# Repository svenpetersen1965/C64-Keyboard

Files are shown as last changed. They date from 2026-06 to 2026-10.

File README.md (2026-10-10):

# Status
* Hardware tested: done
* Software tested: done
* Upload all design files: done
* Documentaion: completed, except "Howto: Keycaps"
  
# C64-Keyboard
A mechanical keyboard for the C64.
*	<b>Reset</b>: The keyboard can generate RESET and EXROM RESET signals.
*	<b>Kernal switching</b>: The keyboard can switch between multiple Kernals on an EPROM Kernal adapter.
*	<b>OLED display</b>: An I²C OLED display can be connected to the keyboard.
*	<b>Piezo buzzer</b>: The keyboard includes a piezo buzzer for signaling.
*	<b>USB keyboard</b>: The keyboard can be operated as a USB keyboard for VICE and BMC64.
*	<b>RGB lighting</b>: The keyboard can produce a light show using a WS2812B RGB LED strip.
*	<b>Power LED</b>: The C64's power LED can be connected to the keyboard on either the left or right side and can be made to blink.
*	<b>Additional buttons</b>: Two additional buttons beside the shorter space bar provide additional control functions.

This is a work in progress. I am sharing some files in advance. A full release will happen soon. 

After about 21 months of work, the day has finally come: I’m releasing my Commodore C64 keyboard project on GitHub!

I haven’t been working on it full-time, of course, but I’ve still put several person-months of work into it (most of it for documentation). And I’ve certainly spent a few thousand euros along the way (so you don't have to).

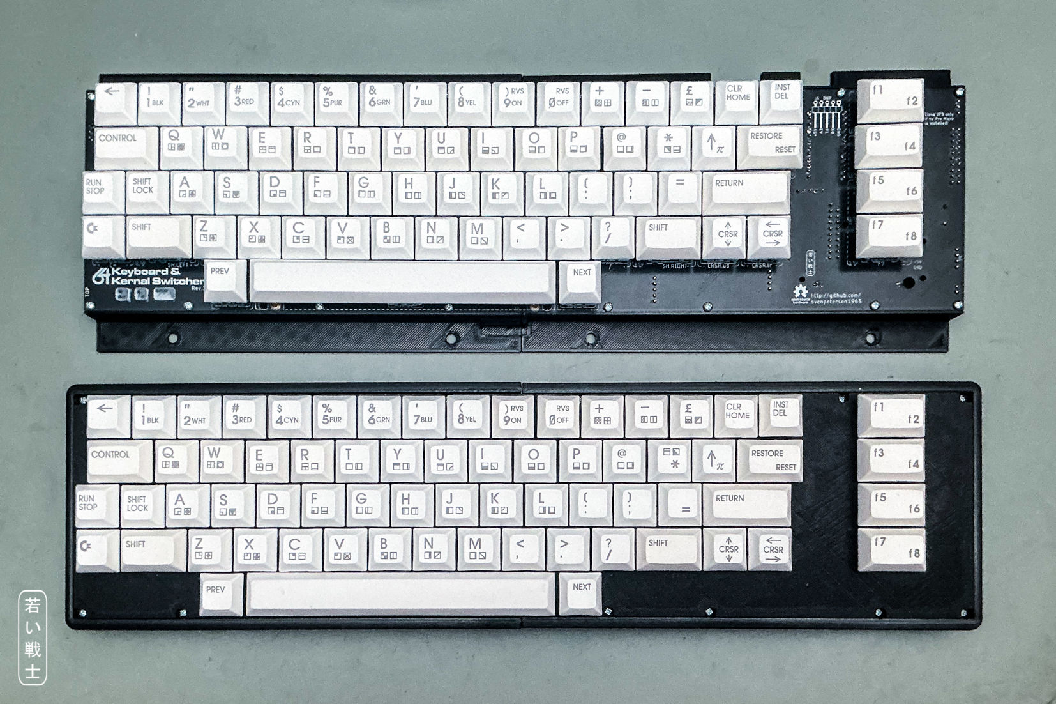
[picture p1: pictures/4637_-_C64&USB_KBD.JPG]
C64-Keyboard and the USB-Keyboard version

<p align="center">The C64 mechanic Keyboard and the USB-Keyboard version for VICE and BMC64</p>

My goal was to build a complete keyboard, including the keycaps, and figure out a way for others with some DIY skills to build one, too, without having to spend anywhere near as much money.

Let me be clear, though: this isn’t meant to be a cheap replacement for an original C64 keyboard. It’s for people who use a C64, an Ultimate 64, or another C64-compatible system and enjoy mechanical keyboards. If you’d like to build your own keyboard and add some extra functionality to your setup, this project might be just what you’re looking for.

The documentation is around 80 pages long, but most of it consists of pictures, and you don't need to read every single page. I'd really appreciate it, though, if you took the time to understand the important parts. Otherwise, I might end up providing support for years to come, and I'd rather spend that time working on new projects!

The bill of materials (BOM) is quite flexible. You don't need all the components; you can populate only the parts required for your intended setup. I've designed the BOM to make this as straightforward as possible.

However, you should decide which features you need before ordering the components. Even if you fully populate the board, none of the unused circuits will interfere with the keyboard's normal operation.

I'd like to draw your attention to the following important sections of the documentation:
*	Hardware module description: Versions with and without hot-swap sockets for the keyboard switches.
*	C64 Keyboard Connector PCB: Module description.
*	Which Cables Do I Need?
*	How To: Keycaps: A short guide to making your own keycaps.
*	Software documentation: How to use and configure the firmware.

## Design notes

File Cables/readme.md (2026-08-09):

There are three cables in this subdirectory:
1. The keyboard cable to the C64 Keyboard Connector PCB (plugged into the mainboard): KB_Cab
2. The Kernal Switcher Cable (between the keyboard and the EPROM Kernal adapter): KSw_Cab
3. The Ultimate 64 cable between the keyboard and the button pin header: Ulti_Cab

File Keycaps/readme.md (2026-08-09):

The key caps were scanned off a C64C keyboard. Then redrawn in Inksacpe and finally exported as PNG file for further processing/printing.

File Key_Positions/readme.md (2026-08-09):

The position information was obtained by measuring an original C64 keyboard plastic shield with calipers (a normal and an extral long one).

The data was further processed to even out failure and to finally calculate the switch positions on the PCB.

The "gap" left of the function keys occures on classic C64. Moving the function keys 0.7mm to the left would center them. 

I decided against doing so, because the original position would fit all cases, while I don't know, if a corrected position will do. 

Note: moving the function keys will require modifying the 3D ptintable plates, as well.

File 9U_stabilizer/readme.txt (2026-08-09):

The 9U stabilizer wire is bent from 1.5mm spring steel. It is only required, if classic keycaps are used, since 9U screw-in stabilizers are not sold anywhere.

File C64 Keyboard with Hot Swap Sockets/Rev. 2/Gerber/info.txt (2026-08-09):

      
       Board: Keyboard C64 (Hot Swap)
       Rev.:  2
  
       Files:
       ======
  
       All Gerber files are generated in extended gerber format (RS274X)
       *.TOP        : Film top copper
       *.BOT        :  -"- bottom copper
       *.STC        :  -"- top soldermask 
       *.STS        :  -"- bottom soldermask
       *.PLC        :  -"- silk screen top
       *.PLS        :  -"- silk screen bottom
       *.CRS        :  -"- cream bottom
       *.DK         : Drills plated Through (Excellon)
       *.NDK        : Drills not plated Through (Excellon)
       *.OUT        : Board outline

       Board Size:
       ===========
       Length     :   385.6 mm
       Width      :   96.4 mm
       Thickness  :   1.6 mm
       Material   :   FR 4
       Copper     :   35 um
       Surface    :   HASL
       
       Remarks:
       ========
       width > 6mil
       distane >= 6 mil
       drill >= 6mil

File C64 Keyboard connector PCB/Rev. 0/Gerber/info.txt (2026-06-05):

      
       Board: Keyboard C64 connector PCB
       Rev.:  0
  
       Files:
       ======
  
       All Gerber files are generated in extended gerber format (RS274X)
       *.TOP        : Film top copper
       *.BOT        :  -"- bottom copper
       *.STC        :  -"- top soldermask 
       *.STS        :  -"- bottom soldermask
       *.PLC        :  -"- silk screen top
       *.PLS        :  -"- silk screen bottom
       *.DK         : Drills plated Through (Excellon)
       *.NDK        : Drills not plated Through (Excellon)
       *.OUT        : Board outline

       Board Size:
       ===========
       Length     :   53.0 mm
       Width      :   15.0 mm
       Thickness  :   1.6 mm
       Material   :   FR 4
       Copper     :   35 um
       Surface    :   HASL
       
       Remarks:
       ========
       width > 6mil
       distane >= 6 mil
       drill >= 6mil

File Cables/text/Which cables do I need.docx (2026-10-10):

C64 Keyboard: Which Cables Do I Need?

You can find three cable drawings in the /Cables/pdf subfolder:

- KB_Cab.pdf: The 20-way ribbon cable connecting the keyboard to the keyboard connector PCB.
- KSw_Cab.pdf: The cable connecting the Kernal EPROM adapter PCB to /RESET and /EXROM.
- Ulti_Cab.pdf: The cable connecting the keyboard to the “Buttons” pin header on the Ultimate 64 Elite II or C64 Ultimate mainboard.

Which cables you need depends on how you intend to use the keyboard.

- USB keyboard for VICE: No cables required.
- C64 keyboard without Kernal switching or reset functionality: KB_Cab.
- C64 keyboard with Kernal switching and reset functionality: KB_Cab + KSw_Cab.
- Keyboard connected to an Ultimate 64 Elite II or C64 Ultimate: KB_Cab + Ulti_Cab.

So, you never need more than two cables.

# Making the ribbon cable

Making a ribbon cable requires no soldering and should only take a few minutes. All you need is a vise to press the connector onto the cable and a pair of scissors to cut the ribbon cable to length.

# Making the Dupont cables

For the Dupont cables, you can either use a ready-made 40 cm Dupont ribbon cable with individual female connectors, which can be used as is, or additionally use a Dupont connector assortment with crimp housings in the required sizes (3-way, 4-way and 5-way). The latter option is a bit better, as the housings keep the wires in the correct order and prevent mix-ups. To do this, you can remove the crimp terminals from the individual 1-way housings (pointy tweezers) and insert them into the appropriate multi-way housings from the assortment.

f you want to crimp the connectors yourself, I recommend the IWISS SN-025 crimping tool. It's the only tool I've personally found that can properly crimp Dupont terminals. Other tools, such as the SN-28B or SN-48B, are sometimes advertised as Dupont crimping tools, but they aren't suitable for this purpose. They're good tools, just not for Dupont terminals.

Which cables do I need.docx 10.10.2026 17:31 Drafted by Sven Petersen Page 2 of 2 Doc.-No.: 000-6-00-00

Which cables do I need.docx 10.10.2026 17:31 Drafted by Sven Petersen Page 1 of 1

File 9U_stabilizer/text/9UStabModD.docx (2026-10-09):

How To: 9U stabilizer (v.0)

Like 9U space bars, a 9U stabilizer cannot be purchased off the shelf. The only situation in which you need a 9U stabilizer is when using the original 9U space bar from a classic C64. A Blingboard64 or C64 Ultimate space bar is also 9U long, but uses a 7U stabilizer.

A 9U stabilizer can be made from a stabilizer of any length by replacing its stabilizer wire with a homemade wire of the appropriate length.

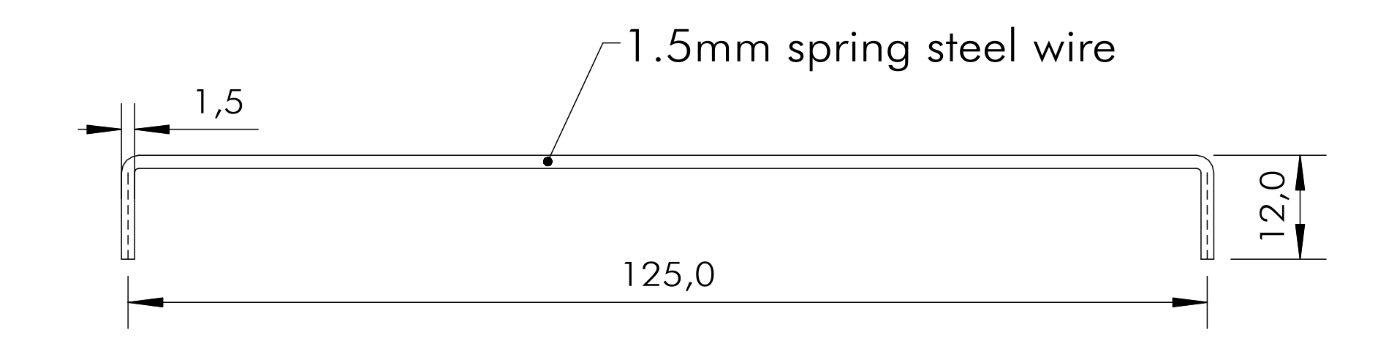
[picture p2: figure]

Figure 1: Dimensions of the 9U stabilizer wire

The material is 1.5 mm spring steel wire. This is often sold as a 5-meter spool, but a shorter, straight piece is easier to handle, as it does not need to be straightened first.

The required wire length is 147.5 mm. However, it is recommended to cut a slightly longer piece and trim and file the ends to the correct length after bending.

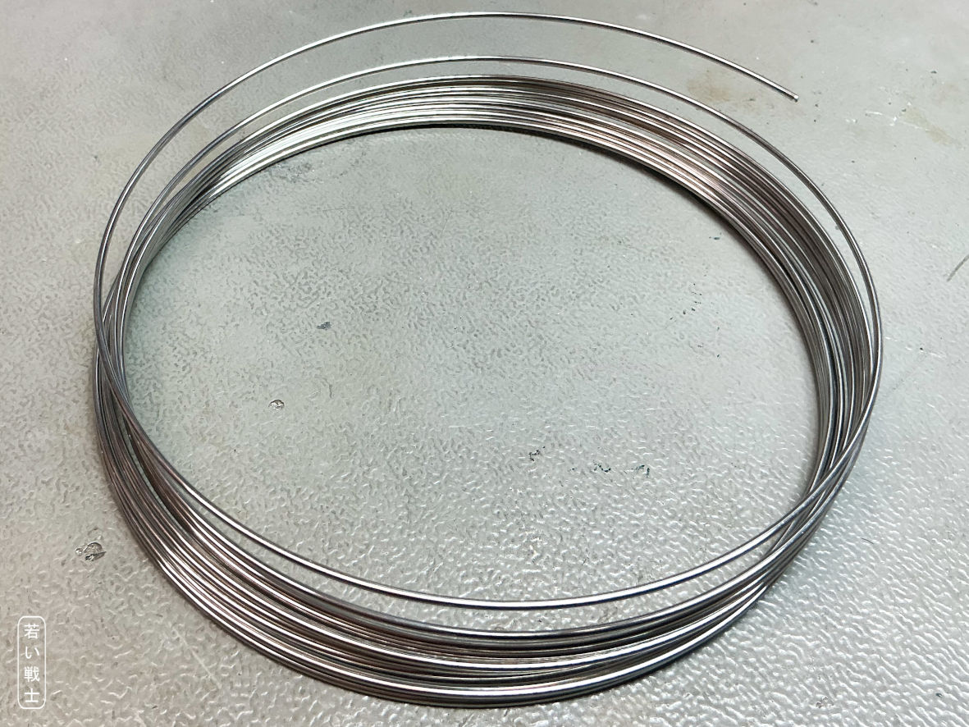
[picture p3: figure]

Figure 2: 1.5mm spring steel spool

The wire can be straightened using a wire straightener, which is an investment of €40 or more.

I was advised to unwind wire from the spool, then hold one end in a vise and pull the wire with combination pliers until it is straight. This, of course, requires a longer piece of wire, as the end will be worn out during this process.

The wire straightener I bought (Figure 3) gets the wire reasonably straight, but not perfectly straight. To achieve a perfectly straight wire, it can be rolled between two flat, hard surfaces as a final step. I tried it without this last step, and it worked fine.

The wire straightener consists of four steel rollers on one side and three on the other, all mounted on ball bearings. The distance between the rollers can be adjusted with a screw.

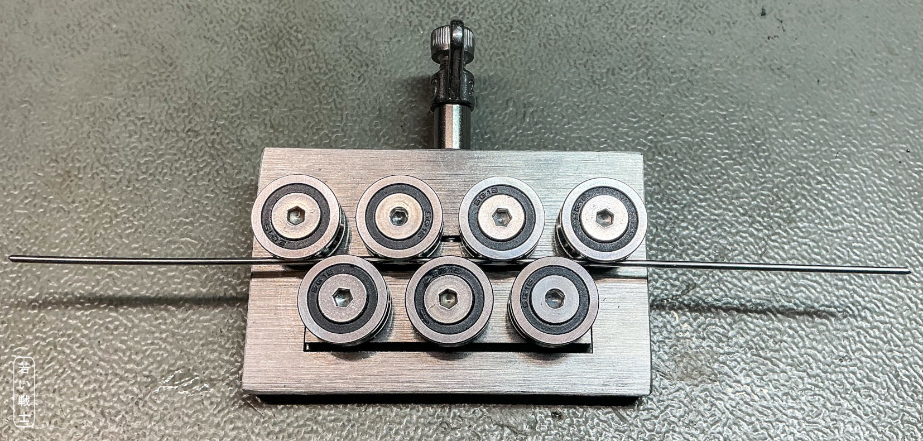
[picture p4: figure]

Figure 3: Wire straightener

The basic strategy for producing a straight wire is to cut a piece about 40–50 cm long from the spool.

Start with a relatively large distance between the rollers, which will leave the wire slightly curved. Push and pull the wire through the straightener several times. Then reduce the distance between the rollers and repeat the process. Reduce the distance again and continue in this way, gradually straightening the wire more and more.

If the wire becomes slightly overbent in the opposite direction, turn it 180°, increase the roller distance very slightly, and see what happens. “Pretty straight” is good enough.

The length of the stabilizer wire does not need to be highly accurate, neither does the angle. I estimate the tolerance to be ±0.7mm, that the stabilizers can accept, which I have used. The first 90° bend is not problematic at all. Just get the 12mm end a bit longer than that, it will later be trimmed and filed. For bending the wire, combination pliers and a hard surface are ok, a wire bender might be slightly better.

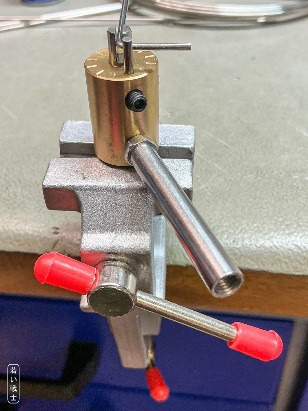
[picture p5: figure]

Figure 4: Not the greatest wire bender

I have bought a pretty crappy wire bender (Figure 4). The vise is actually the bad part of it. In case you always wanted to have a wire bender, make sure that a 1.5mm wire will fit in its slot.

Keep in mind, that the inner radius of the bend is not zero. I have managed about 1mm bending radius.

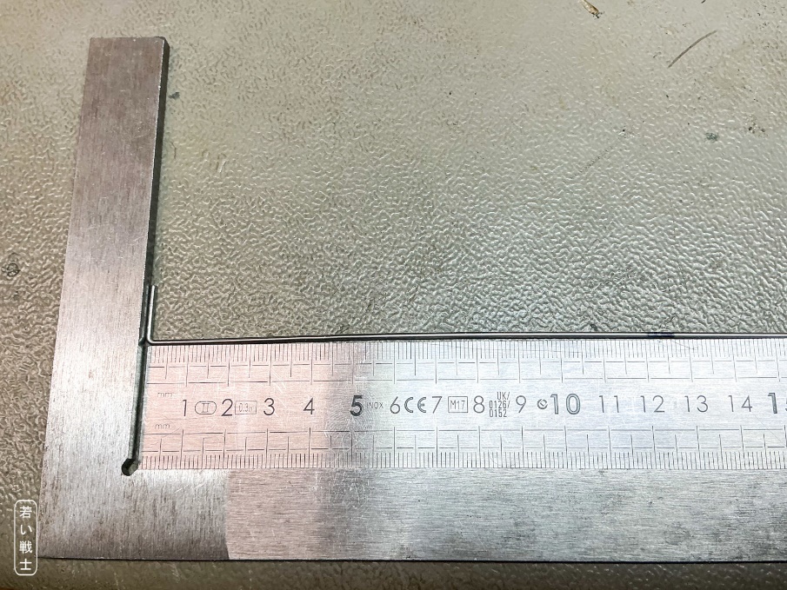
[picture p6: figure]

Figure 5: Marking the desired length after the first bend

For simplicity, I have measured the distance of the 2nd bend. It was a rough estimation, that marking 125mm from the outer surface of the first bend would be a good position. I first painted the wire a bit with a sharpie and marked the position with the scriber (Figure 5).

When bending the wire, it was important to have the first and the 2nd bend aligned (estimated), so the stabilizer wire is not twisted.

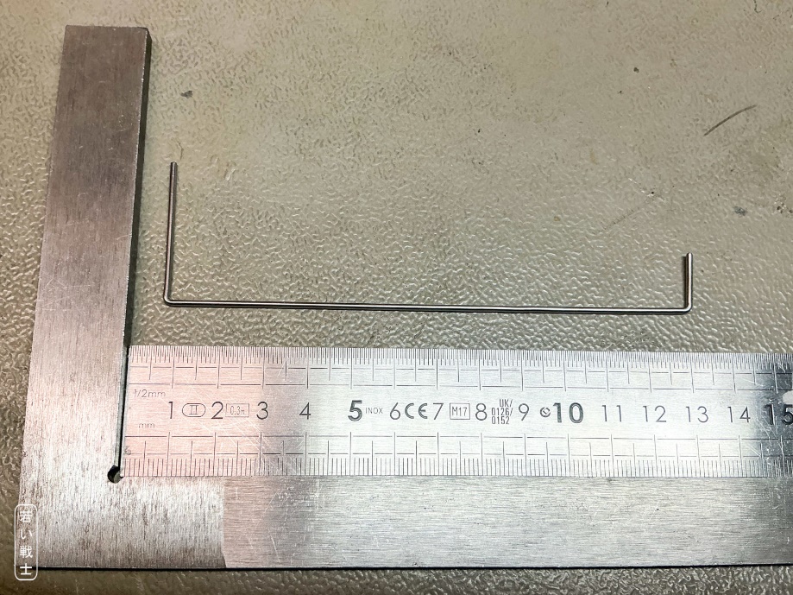
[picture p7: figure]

Figure 6: 2nd bend

The bent wire should lay flat on the work bench, the angle should be about 90°. To make it fit, you can manually twist and bend the wire a bit.

The bent parts of the wire should then be trimmed and filed to length. It should be 12mm or a bit less (Figure 1). If that it too long, the wire will not move freely, which is required.

Keep in mind, that testing the stabilizer wire before the switches are soldered in makes things a lot easier.

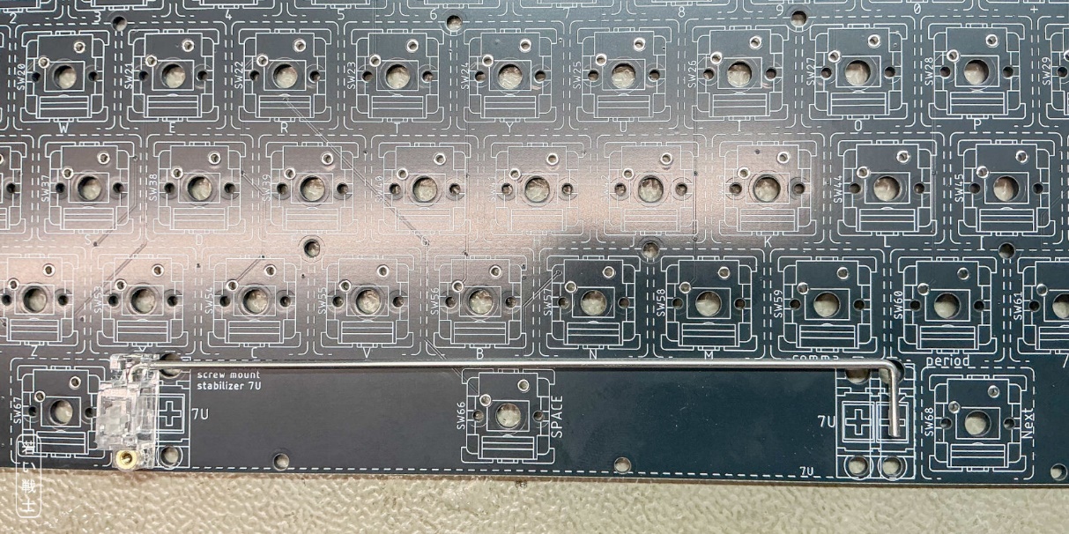
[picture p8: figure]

Figure 7: Checking the length of the stabilizer wire

Insert the wire into one of the stabilizers (the body with the little moving plastic part) and mount it on the PCB. The 2nd bend should be positioned on the center line of the 2nd stabilizer (Figure 7). If that is the case, the 2nd stabilizer can be mounted.

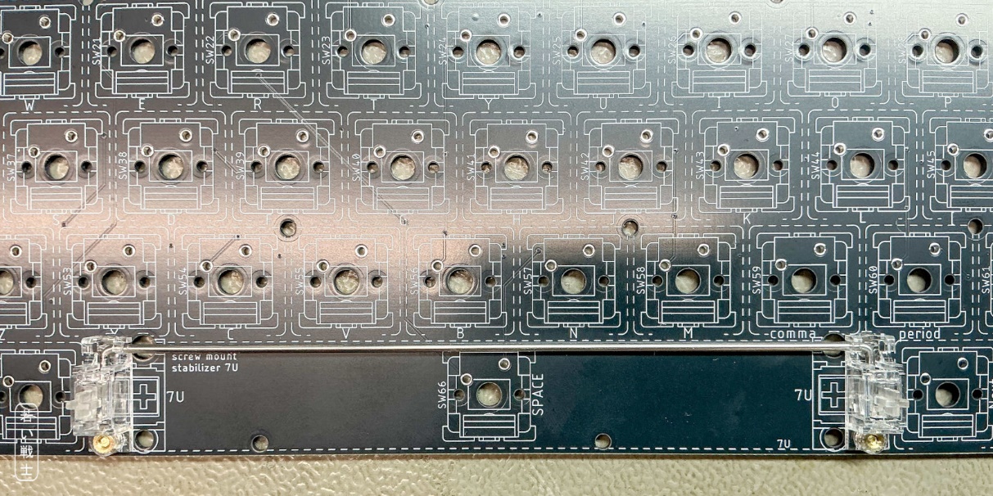
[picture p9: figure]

Figure 8: Space bar stabilizer completely mounted

The moving parts should move freely up and down. If you lift one side, the other should also lift in the same manner. When dropping it, the other side should drop, too. It should not get caught. The spring of the space bar switch needs to be able to fully push the space bar up.

I have made three stabilizer wires yet and screwed up one. So, it is a good thing to have enough wire for two or three attempts.

The perfect wire would have the outer dimension of 0.75mm + 125mm +0.75mm = 126.5mm. The screwed-up wire was only 125mm in total – 1.5mm too short. It could still be installed, but the stabilizer didn’t move freely anymore.

9UStabModD.docx 09.10.2026 18:35 Drafted by Sven Petersen Page 2 of 2 Doc.-No.: 232-6-00-00

9UStabModD.docx 09.10.2026 18:35 Drafted by Sven Petersen Page 1 of 1 Doc.-No.: 232-6-01-00

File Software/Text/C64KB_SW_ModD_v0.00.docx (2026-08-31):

C64 Keyboard Software

Module Description v0.00

# 1. Introduction

The C64 Keyboard functions as a normal/standard matrix keyboard if no micro controller (Pro Micro) is installed. However, if you want to use “smart” functions, like

- RESET/EXROM RESET
- Kernal Switching
- RGB LED illumination (WS2812B strip)
- USB Keyboard (for VICE or BMC64)

some software needs to be installed on the Pro Micro. This can be done using the free Arduino IDE, a suitable USB-C or micro-USB cable, and a PC.

The software can be configured to suit your particular use case simply by uncommenting the appropriate preprocessor macros. This does not require a PhD in computer science and will be described later in this document.

# 2. Functions

## 2.1. C64 (Matrix) keyboard

This requires the Kernal switcher cable to be connected to a Kernal EPROM adapter (long board or short board), plus /RESET and /EXROM.

Key | Duration | Function
| < 0.3 secs | Normal RESTORE
| ≥ 0.3 secs | “RESTORE Fix”: 5 pulses (of 30 msecs each) are issued on the RESTORE signal of the keyboard.
| ≥ 3 secs | A “normal” RESET is issued. SHIFT LOCK is turned off.
| ≥ 5 secs | An EXROM RESET is issued. This bypasses some CBM80 copy protections. SHIFT LOCK is turned off.
| | Cycle through RGB LED modes (downwards)
| | Cycle through RGB LED modes (upwards)
+ | | Cycle through Kernals (downwards), RESET the C64
+ | | Cycle through Kernals (upwards), RESET the C64

The requirement to press PREV/NEXT and RESTORE simultaneously prevents accidentally switching Kernals, since doing so resets the C64 and causes any running program to be lost.

## 2.2. Ultimate (Matrix) keyboard

This requires the Ultimate Buttons cable to be connected to the Buttons pin header on the Ultimate Elite II board. On earlier models, the button pin header is not implemented.

Key | Duration | Function
| < 0.3 secs | RESTORE key
| ≥ 0.3 secs | RESTORE key
| ≥ 3 secs | The RESET button on the buttons pin header is simulated. SHIFT LOCK is turned off.
| ≥ 5 secs | SHIFT LOCK is turned off.
| | Cycle through RGB LED modes (downwards)
| | Cycle through RGB LED modes (upwards)
+ | | The FREEZE button on the buttons pin header is simulated.*
+ | | The MENU button on the buttons pin header is simulated.

* The FREEZE button only has an effect when a freeze cartridge is present.

## 2.3. VICE USB Keyboard

The USB keyboard in VICE mode uses a positional keyboard layout in either English, German, or Swedish. The keyboard is scanned 125 times per second (every 8 ms).

Key | Duration | Function
| < 0.3 secs | RESTORE key sent.
| ≥ 0.3 secs | RESTORE key sent twice.
| ≥ 3 secs | A soft RESET (ALT+F9) is sent. SHIFT LOCK is turned off.
| ≥ 5 secs | A hard RESET (ALT+F12) is sent. SHIFT LOCK is turned off.
| | Cycle through RGB LED modes (downwards)
| | Cycle through RGB LED modes (upwards)
+ | | <ALT>+<8> is sent (attach disk image)
+ | | <ALT>+<C> is sent (attach cartridge image)

## 2.4. BMC64 USB Keyboard

The USB keyboard in VICE mode is a positional English keyboard. The keyboard is scanned 125 times per second (every 8 ms).

Key | Duration | Function
| < 3 secs | RESTORE key sent
| ≥ 3 secs | + f1 is sent. SHIFT LOCK is turned off. *
| ≥ 5 secs | + f3 is sent. SHIFT LOCK is turned off. *
| | Cycle through RGB LED modes (downwards)
| | Cycle through RGB LED modes (upwards)
+ | | + f5 is sent.*
+ | | + f7 is sent.*

* These functions require configuration in the BMC64 menu, which can be accessed by pressing RESTORE. The relevant submenu is:

Keyboard → Mapping → Positional

My Configuration:

Key | Configured Actions
+ f1 | Soft reset
+ f3 | Hard reset
+ f5 | Tape OSD
+ f7 | Menu

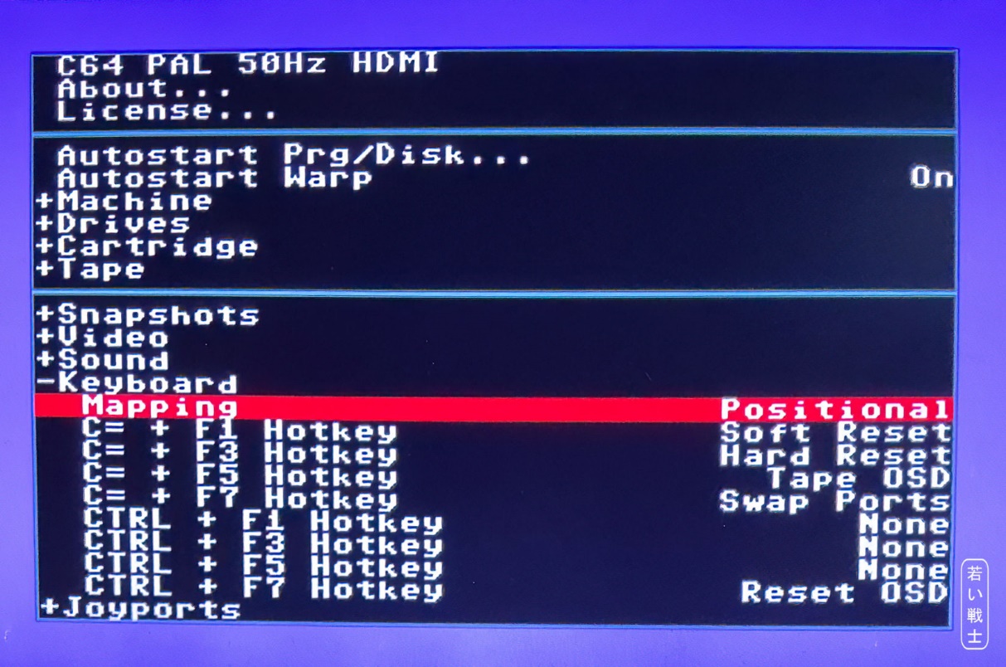
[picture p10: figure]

Figure 1: Configuration of BMC64 in the menu

# 3. Installing and preparing the Arduino IDE

## 3.1. Download and Installation

The Arduino IDE is required for programming the Pro Micro module. In addition, several libraries need to be installed using the IDE's Library Manager.

The Arduino IDE can be downloaded from arduino.cc (https://www.arduino.cc/en/software/). Select the version for your computer's operating system (Windows, Linux, or macOS) and follow the installation instructions.

## 3.2. Library Manager

Next, open the Library Manager in the Arduino IDE.

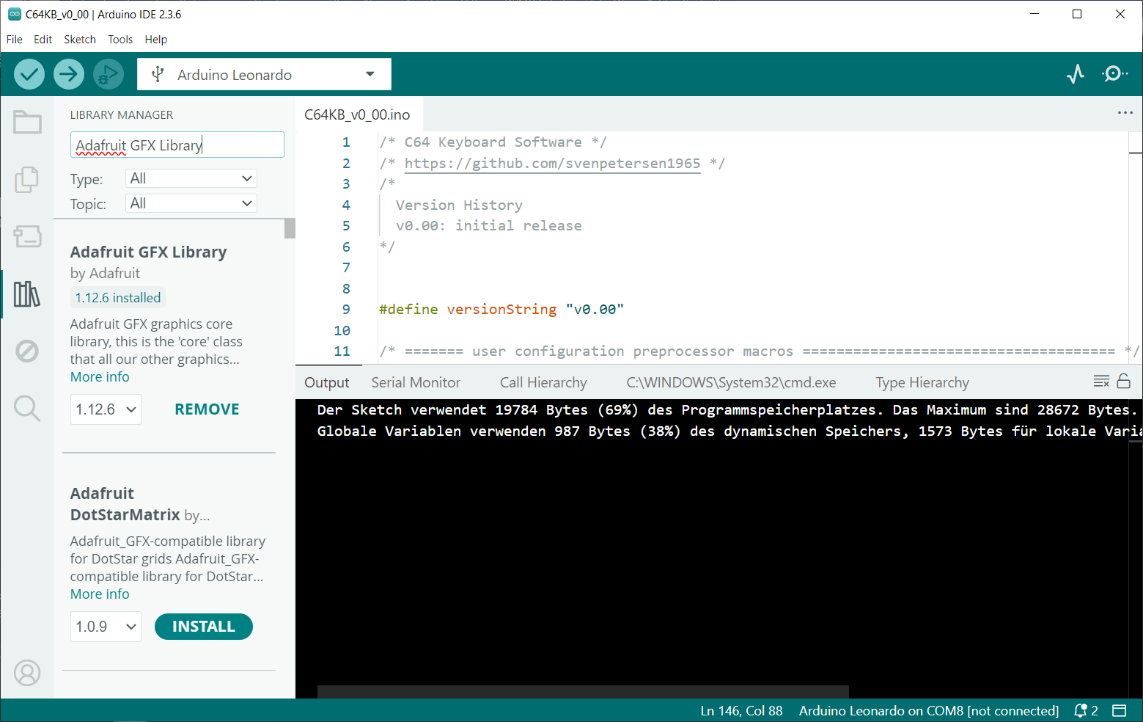
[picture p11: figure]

Figure 2: Library Manager (Arduino IDE 2.3.6)

The Library Manager can be found in the left-hand sidebar. It is represented by the “books” icon, as shown in Figure 2.

You need to install the following libraries:

Library | Source | Version used
Adafruit GFX Library | https://github.com/adafruit/Adafruit-GFX-Library | 1.12.6
Adafruit SSD1306 | https://github.com/adafruit/Adafruit_SSD1306 | 2.5.17
Adafruit SH110X | https://github.com/adafruit/Adafruit_SH110X | 2.1.15
PCF8575 | https://github.com/RobTillaart/PCF8575 | 0.3.0
HID-Project | https://github.com/NicoHood/HID | 2.8.4
Adafruit_NeoPixel | https://github.com/adafruit/Adafruit_NeoPixel | 1.15.5

The table above lists the required libraries, their Internet sources (which you probably will not need), and the library versions used for this project.

In most cases, using a newer version should not cause any problems. However, there may be cases where a newer version is incompatible with the project. If this happens, please install the specific library version used for this project.

# 4. Configuring the Software

## 4.1. Preprocessor macros

The C64 keyboard “C64KB_v?_??.ino” source code can be configured to suit your needs using preprocessor macros. These macros are evaluated during compilation and determine how the software is compiled.

Most of these macros are either defined or undefined. This allows options to be switched on or off simply by uncommenting or commenting out the corresponding line.

Comments are text annotations that are not compiled. A single-line comment starts with //. Preprocessor macros themselves are defined using a #define statement.

Note: Comments can also be enclosed between /* and */. However, this is less convenient when working with preprocessor macros.

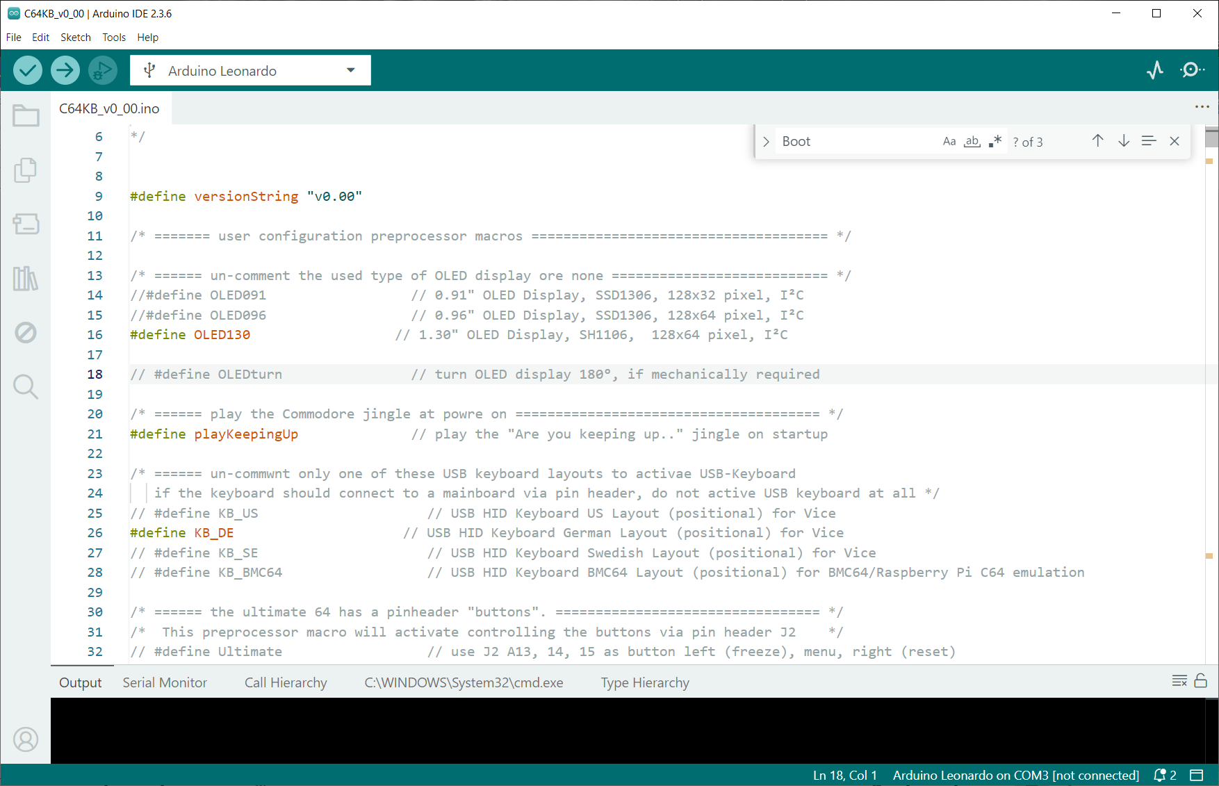
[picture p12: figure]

Figure 3: Some preprocessor macros (Arduino IDE)

In Figure 3 the preprocessor macros OLED130, playKeepingUp and KB_DE are enabled, while all other macros are disabled (i.e., commented out).

In the Arduino IDE editor, comments are displayed in grey, while active preprocessor macros are shown in color. The meaning of these macros is explained later in this document.

## 4.2. OLED display

The software supports three types of OLED displays.:

Preprocessor Macro | OLED Type
OLED091 | 0.91" OLED Display, SSD1306 controller, 128x32 pixel, I²C
OLED096 | 0.96" OLED Display, SSD1306 controller, 128x64 pixel, I²C
OLED130 | 1.30" OLED Display, SH1106 controller, 128x64 pixel, I²C

These OLED displays are widely available on eBay, Amazon, AliExpress, and other online retailers.

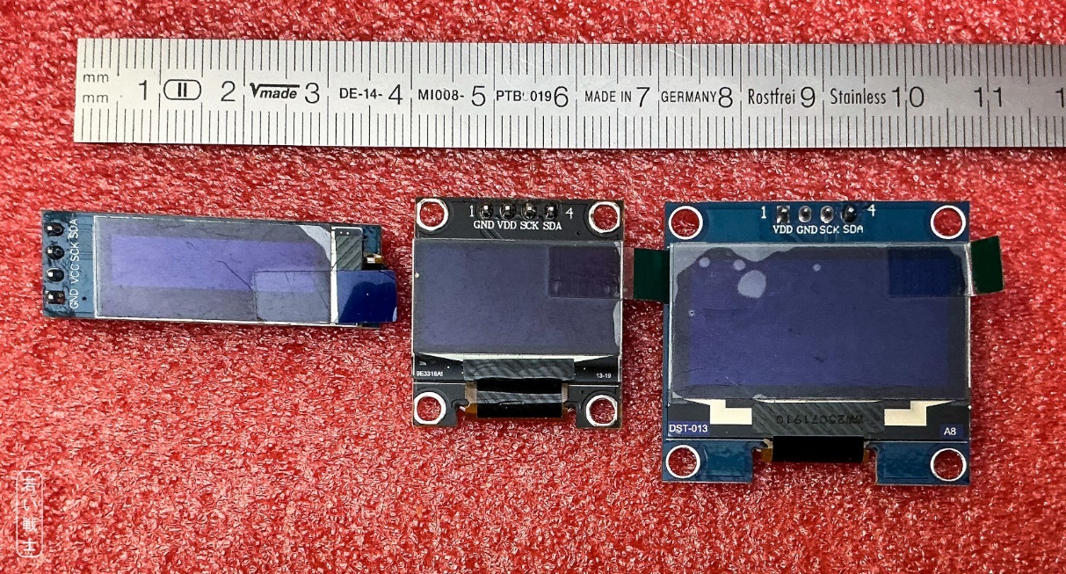
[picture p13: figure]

Figure 4: 0.91", 0.96" and 1.3" OLED Displays (l.t.r.)

If the display needs to be rotated 180° for a better installation, enable the OLEDturn preprocessor macro.

Only one display should be enabled at a time. If no display is connected, do not enable any of the display options.

Note:

- Enabling = uncommenting the macro definition by removing //.
- Disabling = commenting out the macro definition by adding // at the beginning of the line.

## 4.3. Playing the “Are you keeping up with the Commodore” jingle

Yes, I admit, it is a bit nerdy. I did it because I like to play…

The keyboard can play the jingle from the 1983 advertisement. Not in its full length, though—just a few seconds.

This feature can be activated by uncommenting the playKeepingUp. preprocessor macro definition. If it is not enabled, the keyboard starts up with just a beep.

## 4.4. USB Keyboard

There are four different types of positional USB keyboards: three for the VICE emulator and one for BMC64. To use these keyboards, VICE or BMC64 must be configured accordingly.

Preprocessor Macro | Keyboard Layout
KB_US | VICE, positional US Layout
KB_DE | VICE, positional German Layout
KB_SE | VICE, positional Swedish Layout
KB_BMC64 | BMC64, positional US Layout

The software does not support symbolic keyboard layouts (yet).

Only activate one or none of these layouts. If you want to connect the keyboard to a C64 or an Ultimate 64 via the pin header, do not enable any USB keyboard layout, as the keyboard scanning will interfere with the computer's keyboard scanning.

The Ultimate 64 and C64 Ultimate use a symbolic keyboard layout and are therefore not supported. The TheC64 Mini also uses a symbolic keyboard layout and is not supported. I was unable to determine which keyboard modes are required by the TheC64 Mini.

The USB keyboard requires the GPIO/PCF8575 module to scan the keyboard matrix.

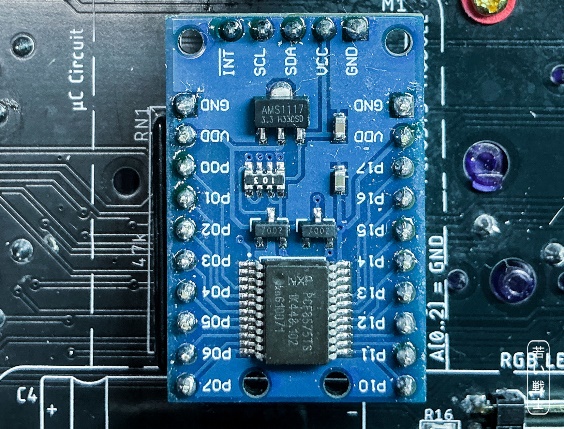
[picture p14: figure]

Figure 5: PCF8575 module M1

## 4.5. Ultimate 64 mode

In this mode, the keyboard is connected to the Ultimate 64 Elite II or C64 Ultimate mainboard via the 20-way ribbon cable/pin header. In addition, a cable must be connected between J2 and the “Buttons” pin header on the mainboard. In Ultimate mode, these buttons are emulated.

To enable this software option, uncomment the Ultimate preprocessor macro definition.

If you want to use the Kernal Switch functions with a regular C64 mainboard, disable this option.

## 4.6. WS2812B RGB LED Strip

The RGB LED strip can be enabled by uncommenting the RGB preprocessor macro definition. This requires several additional parameters, which are also defined as preprocessor macros:

- numRGB: The number of LEDs on your strip.
- effectLen: The length of the effect. It should be ≥ numRGB and can be a multiple of numRGB.
- RGBbright: The brightness of the LED effect.
- RGBspeed: The speed of the fade effect.

If numRGB is smaller than the actual number of LEDs, not all LEDs will be used. If it is larger, the additional value only wastes memory.

The brightness (and, in some cases, the hue) of the individual LEDs is derived from a sine wave function. Its wavelength is determined by effectLen. This value can—and should—be longer than the total number of LEDs (numRGB), resulting in a smoother and more subtle lighting effect.

RGBbright determines the brightness of the lighting effect—the amplitude of the sine wave described above. The maximum value is 255, while 0 turns the LEDs off. RGB LEDs can be very bright, potentially becoming distracting or even uncomfortable. Reflections from the LEDs on the monitor can also reduce the enjoyment of using the system. Therefore, the brightness should be selected carefully. I also recommend avoiding positioning the LEDs so that they point directly toward the monitor or the user's face.

RGBspeed determines the speed of the lighting effect. 0 is the fastest setting and the recommended value.

## 4.7. Kernal Names

The OLED display shows the Kernal name when the C64 Keyboard is used as a Kernal switcher. There are eight Kernals, or seven when using a short-board Kernal adapter. The default names are “Kernal #1” through “Kernal #8”. These names can be customized to match the Kernals programmed onto the Kernal EPROM. The names should not exceed 9 characters in length.

The names are defined using the preprocessor macros KrnName1 through KrnName8.

## 4.8. Boot Logo

There are two logos that can be shown on the OLED display during startup: the C64 logo and the VIC-20 logo, since the keyboard also works with the VIC-20.

Figure 6: 64 vs. VIC-20 logo

The Logo64 preprocessor macro displays the C64 logo, while Logo20 displays the VIC-20 logo. If neither preprocessor macro is defined, only the software version string (versionString) is displayed.

# 5. Programming The Software

The software is programmed using the Arduino IDE. All you need is a suitable USB cable: either a micro-USB or USB-C cable, depending on the model of your Pro Micro.

If you have a micro-USB model, please be careful while the cable is connected. The micro-USB connector is mounted directly on the PCB and can break off easily. USB-C Pro Micro boards are considerably more robust and are therefore the recommended model.

Connect the Pro Micro to your computer. It can either be connected to the C64 Keyboard or directly to the USB cable.

First, make sure that you select the correct board type in the Tools → Board → Arduino AVR Boards menu, as shown in Figure 7.

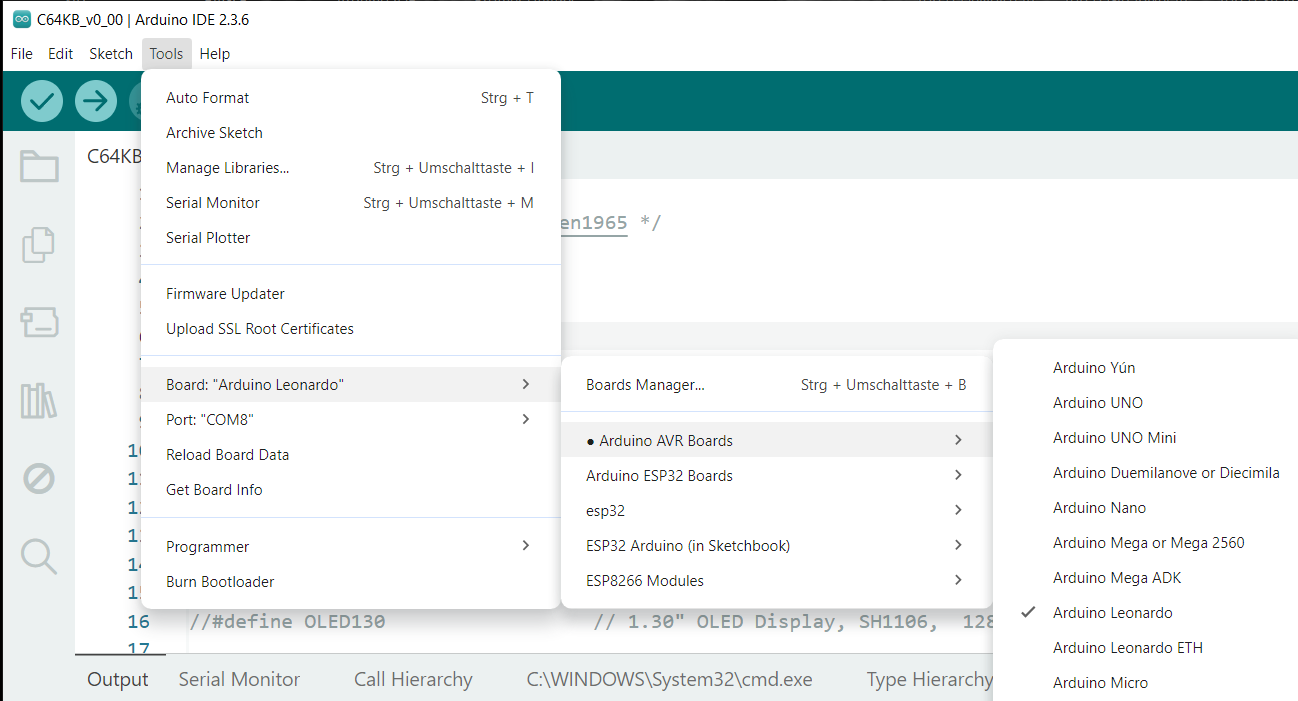
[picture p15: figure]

Figure 7: Selecting Arduino Leonardo

Now, select the appropriate COM port from the Tools → Port menu.

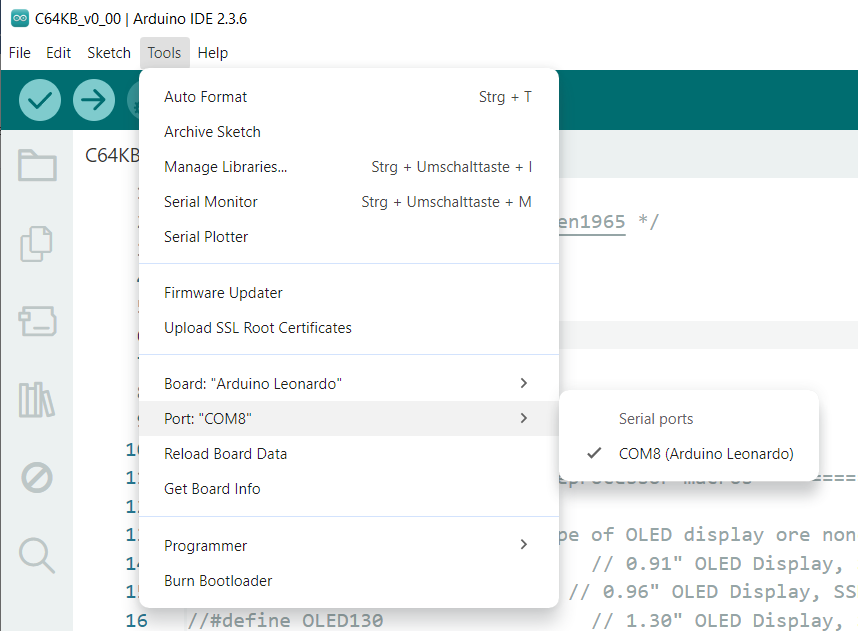
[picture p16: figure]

Figure 8: Selecting the port.

In my case, it is COM8. The port number depends on how the Pro Micro is registered on your computer, so it will be different for each system.

If you cannot find the Arduino Leonardo port, check the Device Manager in Windows:

Windows → Device Manager → Ports (COM & LPT)

The connected Pro Micro should appear there as Arduino Leonardo.

There are three buttons in the teal toolbar at the top of the Arduino IDE: Verify (✓), Upload (→) and Debug ().

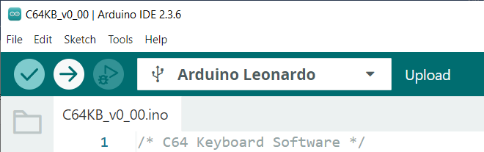
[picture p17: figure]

Figure 9: Verify, Upload and Debug buttons

The Verify button compiles the sketch (the term used by Arduino for source code). The Upload button also compiles the sketch, then connects to the Pro Micro and uploads the compiled program.

The result of compiling the source code (C64KB_v0_00.ino, where v0_00 indicates the version and may change) is displayed in the Output window at the bottom of the Arduino IDE. The output should show how much of the Pro Micro's flash memory and RAM is being used, without any error messages.

At some point during the upload process, the Arduino IDE will wait for the Upload Port. This should not take very long. The avrdude software will then write the program to the Pro Micro's flash memory. It produces red-colored output in the same window.

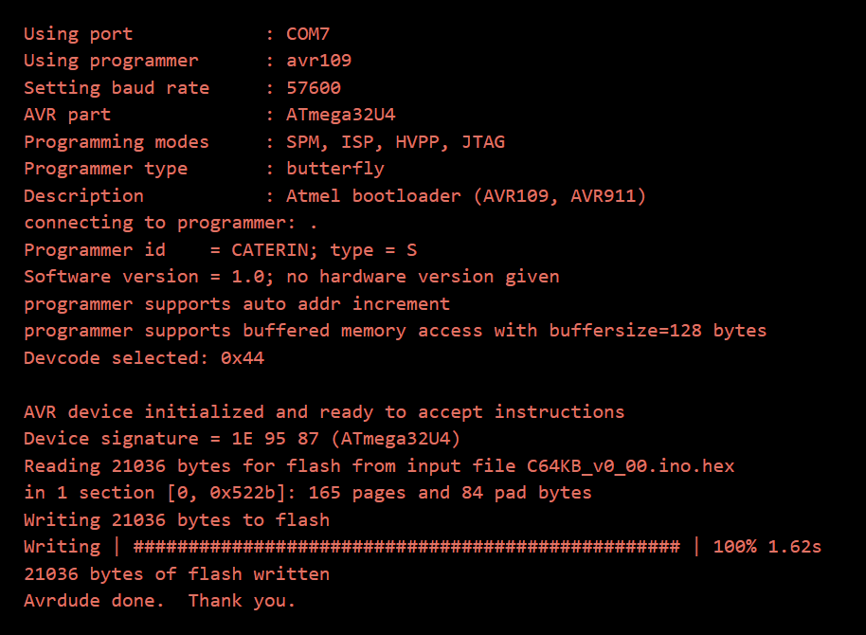
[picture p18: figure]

Figure 10: avrdude

It is important that the Writing | ##################### | progress indicator reaches 100%. This confirms that the Pro Micro has been programmed successfully.

In some cases, the Arduino IDE may fail to connect to the Pro Micro and remain at “Waiting for upload port…” for an extended period. I have read that this can be caused by incorrectly configured USB flags.

This problem can be resolved by resetting the Pro Micro after “Waiting for upload port…” has been displayed twice. To do this, briefly short the adjacent RST and GND pins on the Pro Micro using a jumper (Figure 11) or a reset button (Figure 12).

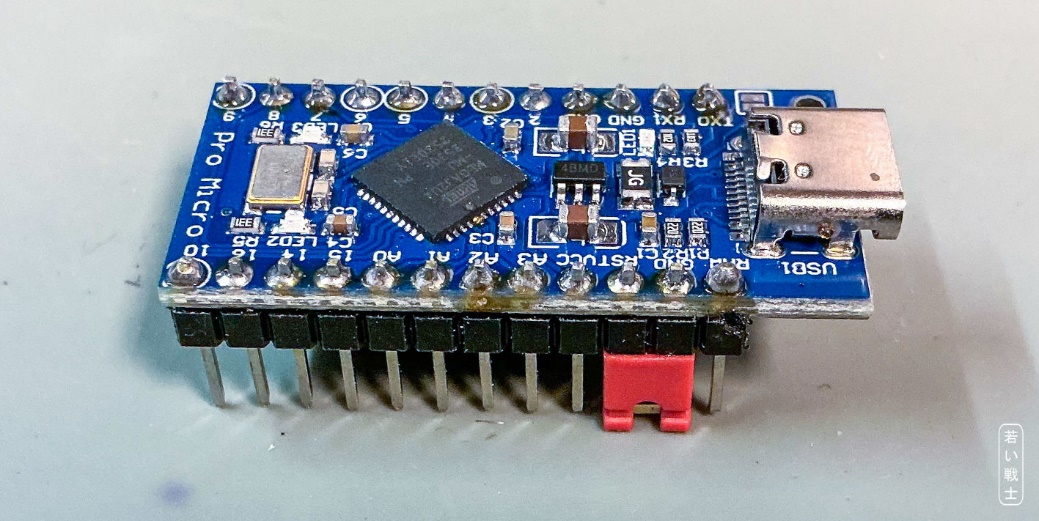
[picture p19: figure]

Figure 11: Pro Micro with a Reset jumper

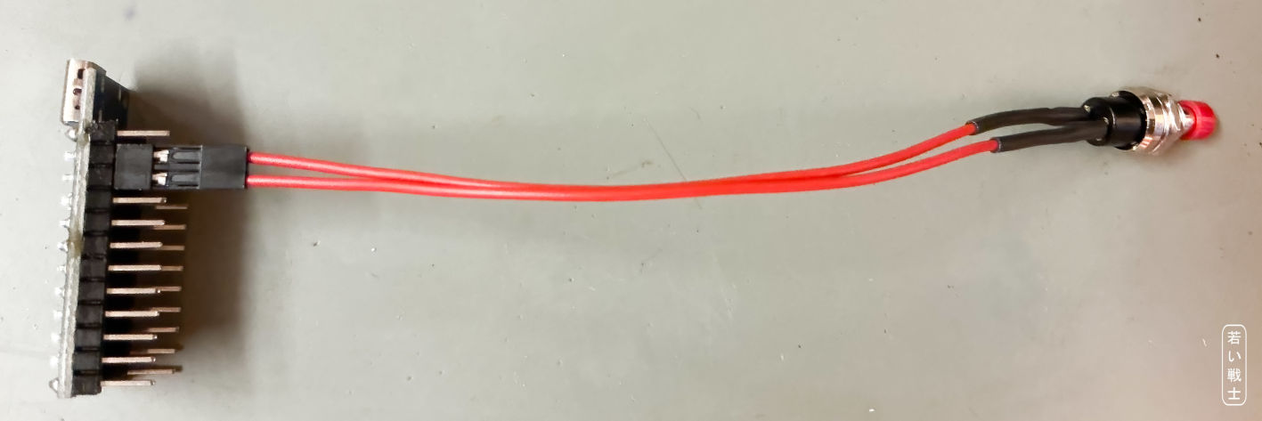
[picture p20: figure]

Figure 12: Pro Micro with a Reset button

In most cases, resetting the Pro Micro once was sufficient. In some cases, however, it was necessary to press the reset button twice. The same procedure can be performed using a jumper, or by briefly shorting the RST and GND pins with another suitable tool, such as tweezers or a Dupont wire.

# 6. Revision History

## 6.1. Rev. 0.00

- Initial Release

C64KB_SW_ModD_v0.00.docx 31.08.2026 16:07 Drafted by Sven Petersen Page 2 of 2 Doc.-No.: 231-6-01-00.00

C64KB_SW_ModD_v0.00.docx 31.08.2026 16:07 Drafted by Sven Petersen Page 1 of 1 Doc.-No.: 231-6-01-00.00

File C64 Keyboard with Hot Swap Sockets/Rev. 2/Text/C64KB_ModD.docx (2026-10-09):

C64 Mechanical Keyboard & Kernal Switcher

Hot Swap Socket Version Rev. 2

Module Description

# 1 Introduction

This project is a mechanical keyboard for the C64 or Ultimate 64, based on Cherry MX-compatible switches.

Mechanical keyboards are not a cheap alternative to the original keyboards. The switches alone (66 + 2) range from about €0.25 to over €1 per switch. The stabilizers for the space bar and Return key cost at least €8, while good-quality ones can easily cost over €20. A set of blank keycaps costs about €30. The PCB is surprisingly inexpensive, at less than €5 plus shipping and import taxes when ordered from JLCPCB.

Since it was possible, I added some functions that I like and that make this keyboard different from other mechanical keyboards for the C64:

- Reset: The keyboard can generate RESET and EXROM RESET signals.
- Kernal switching: The keyboard can switch between multiple Kernals on an EPROM Kernal adapter.
- OLED display: An I²C OLED display can be connected to the keyboard.
- Piezo buzzer: The keyboard includes a piezo buzzer for signaling.
- USB keyboard: The keyboard can be operated as a USB keyboard for VICE and BMC64.
- RGB lighting: The keyboard can produce a light show using a WS2812B RGB LED strip.
- Power LED: The C64's power LED can be connected to the keyboard on either the left or right side and can be made to blink.
- Additional buttons: Two additional buttons beside the shorter space bar provide additional control functions.

The software runs on a Pro Micro module, which is programmed using the free Arduino IDE via a USB cable (USB-C or micro-USB).

The keyboard does not require a metal positioning plate above the keyboard PCB because it uses 5-pin switches: two electrical pins and three centering pins. A 3D-printed frame holds the PCB in position and interfaces with the C64 case or, in the case of a C64C, the keyboard brackets.

The PCB is attached to the frame using 16 C 2.2 × 6.5 mm screws. The resulting assembly is sufficiently rigid to provide a wobble-free typing experience.

# 1 The Keycaps

## 1.1 General considerations

New keycaps have always been problematic. At least one crowdfunding campaign has failed. There are several ways to obtain suitable keycaps for this keyboard:

- Use old/original keycaps with an adapter pin, available from Retro Fuzion (https://www.retrofuzion.com/products/mechboard-64-injection-moulded-keycap-adapter-kit).
- C64 Ultimate-compatible keycaps from CBMStuff (https://www.cbmstuff.com/?utm_source=chatgpt.com) may become available in the future.
- Apply the legends onto available blank keycaps.

The keyboard requires:

- 54 × 1U keycaps + 2 × 1U keycaps for PREV and NEXT
- 8 × 1.5U keycaps
- 1 × 2U keycap (RETURN)
- 1 × 7U space bar

The keycaps need legends to be printed on them, except for the space bar.

For more information about the keycaps, please see the /Keycaps/ subfolder. It contains documentation on how to make or obtain suitable keycaps.

## 1.2 The 1.5U Key Problem (solved)

The problem is that original and modern 1.5U keycaps—such as those used for the F-keys, Shift, Control, and Restore—are different (Figure 1).

Modern keycaps, such as blank keycaps or those from the C64U, have their switch stem—the part on the underside of the keycap that connects to the switch plunger—located in the center.

Original keycaps have two switch-stems, each located 4.75 mm off-center.

Figure 1: Old versus new 1.5U keycap

The solution is that the switches can be installed in either the off-center or center position (see Figure 2). To achieve this, the switches are simply rotated by 90°. This does not affect their operation, since the keycap connector is symmetrical.

The SW**A position is the center position, while SW** is the original off-center position.

Figure 2: Alternative switch positions for the 1.5U keys

Now it is time to talk about the U. It is a unit used to specify key spacing.

Since the early 20th century, typewriter keys have had a spacing of ¾ inch (19.05 mm). This did not change with the transition to computer keyboards. The spacing was defined as 19 ± 1 mm in DIN 2111 from 1927, DIN 2139 from 1976, and ISO 1091 from 1977.

A 1U keycap fits a key with a 1U spacing. 1.5U keycaps are used for the SHIFT, CONTROL, RESTORE, and F-key keys.

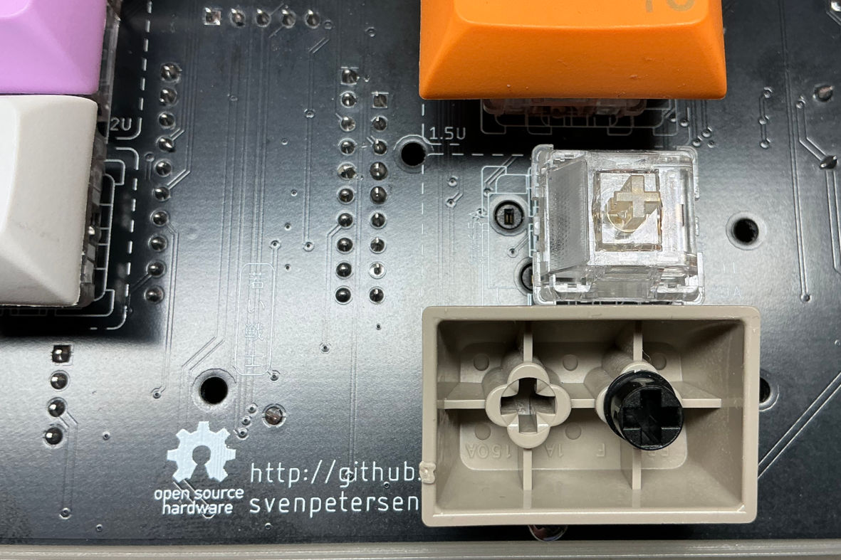
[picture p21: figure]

Figure 3: An original F7/F8 keycap with an adapter pin in position. The switch is mounted respectively (PCB Rev. 1 Hot Swap)

Figure 4: The original keycap mounted on switch

## 1.3 The Space Bar, PREV, NEXT

The original space bar is 9U wide, which I could not find available anywhere. I therefore decided to use a 7U space bar, which is available from several sellers on AliExpress. The remaining 2U are used for two additional 1U keys, PREV and NEXT, which can be used for switching between Kernals or LED modes.

## 1.4 Keycap Profiles

There are several keycap profiles available (Figure 5). Except for the CBMStuff keycaps, all other profile types differ from the original keycaps. Some profiles use a different keycap shape for each row of the keyboard, which would require ten different types of keycaps: four different 1U keycaps, four different 1.5U keycaps, one 2U keycap, and one space bar.

I have only looked for blank keycaps on AliExpress, and all the ones I found were DSA profile keycaps. At least this profile offers all the required keycap sizes.

The material of choice is PBT. It is well suited for applying legends, including processes involving heat, and it also has a pleasant feel.

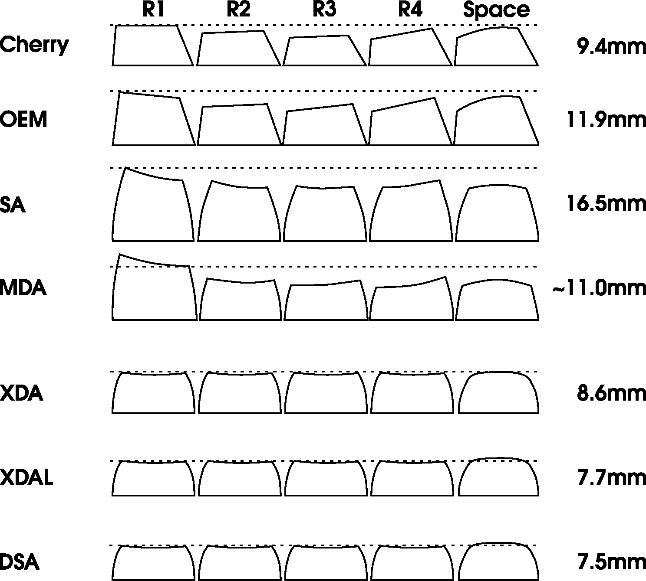
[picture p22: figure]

Figure 5: Different keycap profiles

# 2 The Switches

There are many mechanical switches available, offering different click characteristics and actuation-force profiles. I am not a “keyboard enthusiast,” so I do not have any particular preferences in this regard. I have tried switches ranging from budget models to somewhat more expensive ones and found them all quite good—and definitely better than the original keyboard. Even the €0.25 switches were perfectly acceptable.

Most importantly, the switches must be 5-pin switches. All switches have two electrically relevant pins and one plastic pin for centering. Since I did not design a separate mounting plate for this keyboard, the switches rely on two additional plastic pins, making a total of five pins, to position themselves accurately.

A mounting plate is a purely mechanical component made of metal, plastic, or FR4 (the material used for PCBs). It provides a second level, 5 mm above the actual PCB, with square cutouts for the switch bodies.

I once built a keyboard for 3-pin switches using a second PCB as the mounting plate. Due to the milled cutouts, this was several times more expensive than the keyboard PCB itself. Therefore, 5-pin switches are by far the better choice for this design.

Figure 6: 3 pin versus 5 pin switches (right)

When choosing the switches, avoid 3-pin switches as well as magnetic switches. Magnetic keyboard switches require Hall-effect sensors, which are not supported by this PCB.

The Shift Lock key does not latch. As far as I know, latching keyboard switches are no longer manufactured. Even if you can still find them, they are prohibitively expensive, costing more than €30 each.

# 3 The Hot Swap Sockets

The switches can be inserted into hot swap sockets without soldering. These hold the switches sufficiently well. It is likely, that you might pull out the switch together with keycap, in case you want to extract the keycap.

The hot swap socket is an SMD part which is placed on the solder (bottom) side of the C64 Keyboard PCB.

Figure 7: Hot swap sockets on the solder side of the PCB

The switches can easily be replaced with other switches of a different type. However, care must be taken when inserting them, as the hot-swap sockets can be damaged if the switch pins are not properly aligned and “excessive” force is used.

The 3D-printed plate should be thoroughly deburred so that the switches can snap into position without excessive force. From the bottom side of the PCB, check that both switch pins are properly seated in the hot-swap sockets before pressing the switch fully into place.

Damaging a hot-swap socket can also damage the associated copper traces. I experienced this once when using a plate that had not been properly deburred.

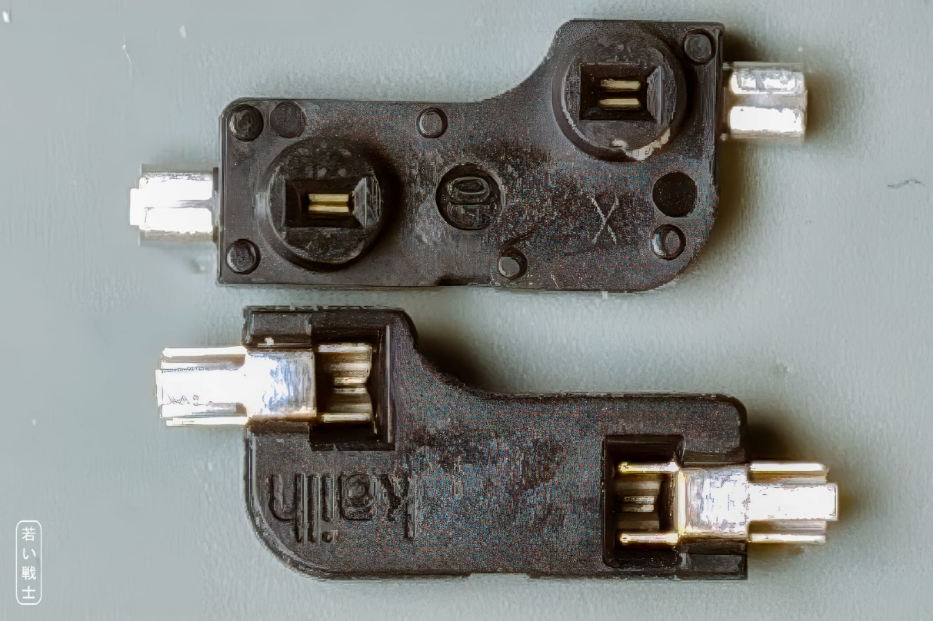
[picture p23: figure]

Figure 8: Hot Swap Sockets (both sides)

Figure 9: Hot swap socket as seen on the component/top side of the PCB

# 4 Stabilizers

The original space bar stabilizer consists of a spring-steel wire anchored to the plastic frame and guided through slots in two plastic pins located on the left and right underside of the space bar. It prevents the long key from tilting or binding when pressed.

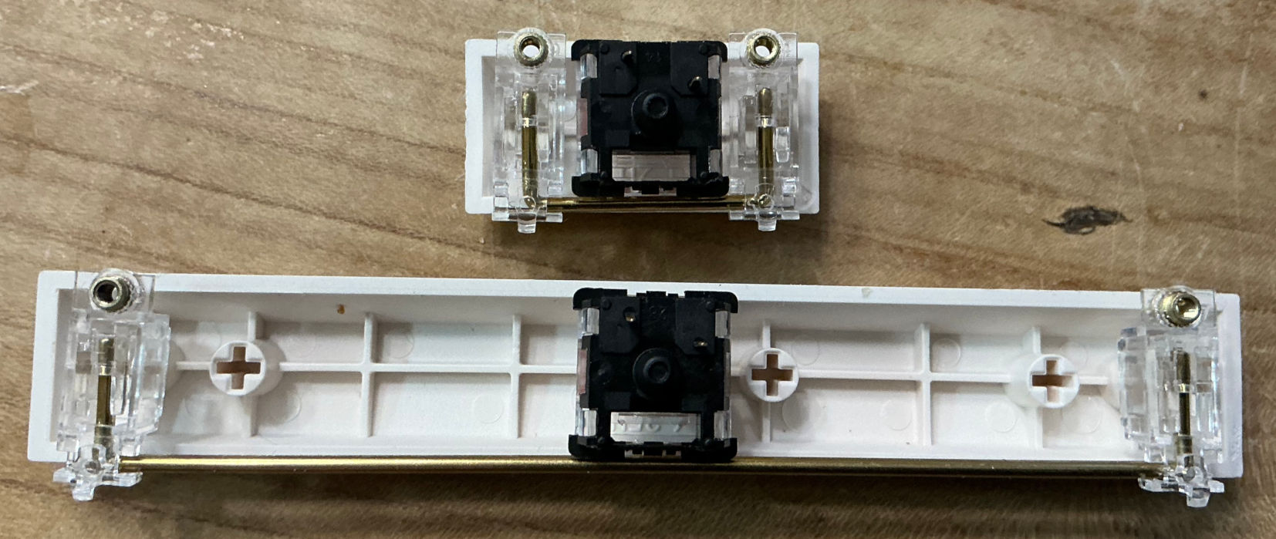
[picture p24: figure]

Figure 10: Stabilizer below space bar and RETURN keycap

The space bar stabilizer is essential; for the RETURN key, it is optional in my opinion.

The stabilizers are the most expensive components of this project. You can expect to pay €8 to more than €20 for both. It is important to buy a 7U stabilizer for the space bar—not a 6.25U stabilizer—and a 2U stabilizer for the RETURN key. They are often sold as a set.

Screw-in stabilizers are the best choice. There are also stabilizers that snap into the holes in the PCB; both types are suitable. Make sure the stabilizers are designed for a 1.6 mm PCB, not a 1.2 mm PCB.

Plate-mount stabilizers are not suitable, since this design does not use a mounting plate.

Figure 11: Stabilizer with mounting screw vs snap-in

The stabilizers are mounted in different orientations due to space constraints. The wire runs above the space bar switch and below the RETURN switch (Figure 9).

Figure 10 shows a screw-in stabilizer mounted on the bottom side of the PCB. One side has a hook that must be hooked into place first. The other side fits through the corresponding mounting hole. Once the stabilizer sits flush against the PCB, it can be secured with the screw. The plastic insulating washer should be used.

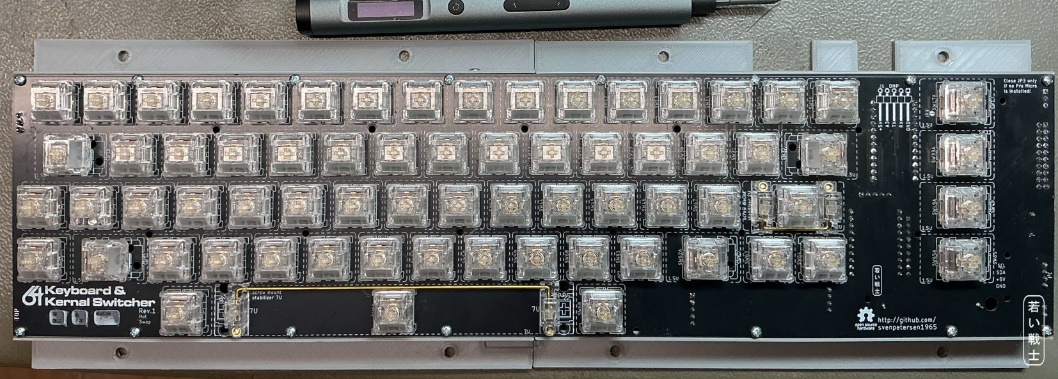
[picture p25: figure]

Figure 12: Stabilizers mounted on the keyboard

A 9U stabilizer is only required for the original spacebar. The C64 Ultimate and Blingboard64 spacebar works with a 7U stabilizer.

Find additional information in the /9U_stabilizer/ subfolder of this repository.

Figure 13: Bottom side of the mounted stabilizer (screw mount)

# 5 The Circuit

## 5.1 Block Diagram

This is the block diagram of the C64 keyboard project. The original keyboard consists only of the switch matrix (without PREV and NEXT), the interconnections, and the keyboard connector at the end of the cable.


Figure 14: Block Diagram of the C64 Keyboard

The circuit is scalable to suit your needs. The minimum configuration consists of the switch matrix (without PREV and NEXT), the keyboard connector, and the Shift Lock circuit.

If you do not want the beeps, simply leave out the piezo buzzer. If you do not need a display, do not connect one; the software must then be configured accordingly.

If you do not want to use the keyboard as a USB keyboard, the GPIO module is not required.

## 5.2 Keyboard Matrix and Output Connector

The key switches are connected in an 8 × 8 matrix, consisting of 8 rows and 8 columns. The RESTORE key has a dedicated pin on the keyboard connector. This is identical to the circuit of the original keyboard.

The output connector is a 2 × 10-pin, 90° box header. I chose this type of connector because it connects to the ribbon cable via an IDC socket connector. This requires only a vice to compress the connector and does not require any specialized crimping tools.

Figure 15: The keyboard connector with the ribbon cable and the connector PCB (Rev 1 with hot swap sockets)

## 5.3 The SHIFT LOCK Switch

The SHIFT LOCK key does not latch like on an original keyboard. As far as know, latching Cherry MX compatible keyboard switches are no longer being manufactured. Even in case you find a used one of them, they are prohibitively expensive (over 30€ each).

This is the reason for using a standard switch with a little circuit. In Rev. 0, this is not 100% reliable. Sometimes the keyboard starts up with shift lock on. The circuit works perfectly when powering the keyboard from a lab power supply. Only installed in a C64, it sometimes does not work properly. The problem will be resolved in a later revision of the PCB. There is a simple fix with a botch wire, though (see The Power-On Reset Botch).

The status of the SHIFT LOCK switch is indicated by an LED, which is attached to this switch. It should be a high brightness LED, so even in daylight it can be noticed.

The Power-On Reset (POR) circuit is only required if the keyboard is intended to be used without the Pro Micro controller, as a “passive” matrix keyboard.

An installed Pro Micro resets the Shift Lock circuit. Therefore, if M2 is installed, the “expensive” POR circuit (IC3) can be left unpopulated.

Figure 16: SHIFT LOCK status LED

I have tried normal LEDs in this position. In a dimly lit room, there was no problem, but in a well-lit room, their visibility was poor.

The current-limiting resistor for the LED is R1. It is calculated as 100 Ω for an LED with a 2 V forward voltage drop (red or green) and a forward current (IF) of 30 mA.

A standard LED may not be suitable for this relatively high current. A lower current, and therefore a higher resistor value (e.g. 150 Ω), may be more appropriate for normal LEDs.


Figure 17: Shift Lock circuit Rev. 2 (botch wire due to broken trace)

## 5.4 The Micro Controller Module

The keyboard controller is a Pro Micro, which is available for about €5 and can be programmed via a USB cable (micro-USB or USB-C, depending on the model).

I strongly recommend a Pro Micro with a USB-C connector, as these are more robust in several respects. It is also preferable to choose a model where the metal connector bracket is secured with through-hole soldering rather than only with SMD pads. I have already broken off half a dozen micro-USB connectors myself.

Figure 18: pro micro with a USB-C connector

The Pro Micro is programmed using the Arduino IDE via a USB cable. It is configured using #define statements at the beginning of the source code. Options that are not required can simply be commented out.

Adding // at the beginning of a line turns it into a comment, so configuring the software should be manageable even without a PhD in computer science.


Figure 19:The pro micro on the PCB. The 10k resistors are required.

Without the Pro Micro, there is no Kernal switching, OLED display, PREV and NEXT keys, piezo buzzer, or LED strip. That is perfectly acceptable if these additional features are not required.

## 5.5 The Piezo Buzzer

The piezo buzzer is a small speaker that is not exactly Hi-Fi, but it provides useful audible feedback.

It emits a beep when RESTORE has been held long enough to trigger a C64 reset, and two beeps when it has been held long enough to trigger an EXROM reset. Different beep patterns are used when PREV or NEXT is pressed.

It can also play the “Are You Keeping Up…” jingle during startup if the corresponding #define statement is enabled.

Figure 20: The speaker (piezo buzzer) circuit.

## 5.6 The Power LED

There are two connectors for the power LED, one on each side of the PCB (J8 and J3). This allows you to choose the side that best suits your installation and reduces the number of cables between the top and bottom of the keyboard to the keyboard cable alone.


Figure 21: The power LED connectorJ8 (top left)

The power LED is controlled by the Pro Micro and blinks in sync with the piezo buzzer beeps. This provides useful visual feedback, especially in noisy environments where the buzzer may be difficult to hear.

If there is no controller, the LED can be powered permanently by closing the JP3 solder bridge on the top side of the PCB. Only close JP3 if no Pro Micro is installed; otherwise, the controller may be damaged.

The current-limiting resistor is R11, which is 330 Ω by default. This provides a forward current of approximately 10 mA for a standard red LED.

Only one power LED should be used. Using two LEDs may cause them to be dim, have different brightness levels, or fail to light at all.

## 5.7 The GPIO Module

The purpose of the GPIO module (M1) is to provide the Pro Micro with the additional I/O pins required to scan the keyboard matrix 125 times per second when the keyboard is used as a USB keyboard for VICE.

In all other operating modes, the GPIO module is not required. Consequently, the pull-up resistor network RN1 is not required either.

Figure 22: The PCF8575 GPIO module

The module is connected to the pro micro via the I²C bus. To access any IC or module on this bus, a properly set I²C slave address is required to properly access the module. This slave address of the module is configured by solder bridges on the bottom side of the module PCB. They (A0…2) should all be closed to the GND side (Figure 20). That sets the slave address to 20HEX/0x20.

Figure 23: properly configured PCF8575 module


Figure 24: The µC circuit including the PCF8575 GPIO module M1 and resistor network RN1

## 5.8 The Kernal Switcher

The Kernal switcher is controlled by the RESTORE, PREV, and NEXT keys. The switching logic is handled by the Pro Micro controller.

It can switch between the Kernals stored in an EPROM on a Kernal adapter (Figure 22). A 27C512 EPROM can hold up to eight Kernals.

Figure 25: Kernal Adapter

I have created two different versions, both of which are available on GitHub:

- C64 Kernal Adapter/Switch Long Board (https://github.com/svenpetersen1965/C64-Kernal-Adapter-Switch-Long-Board)
- C64 Kernal Adapter/Switch Short Board (https://github.com/svenpetersen1965/C64-Kernal-Adaptor-Switch-short-board-)

The reason for the two different versions—for short boards (ASSY 250469) and long boards (all other ASSY numbers) is that the short boards use a combined Kernal and BASIC ROM (16 kB), whereas the long boards have two separate ROMs (8 kB each).

A 27C512 Kernal EPROM has a capacity of 64 kB and can therefore hold eight 8 kB Kernals on a long board. On a short board, the lowest 8 kB memory slot contains the BASIC ROM, leaving the subsequent seven slots for Kernals.

The three highest address bits, A[13..15], are used to select the active Kernal. The Kernal adapters mentioned above have jumpers that normally select the Kernal. However, these address lines can also be controlled by the keyboard. The lower row of pins on the adapter, from left to right, is A13, A14, A15, and +5 V. The +5 V connection is not used.

A cable from the keyboard to the Kernal adapter (Figure 23, yellow/orange/red wires: A15, A14, A13) already provides the three address signals. A RESET connection is also required.

RESET can be tapped at a suitable point near pin 3 of the user port. Usually, there is a via nearby that can be used to solder in a single-pin header. This is the grey wire in the upper part of Figure 23

Figure 26: Character set (left) and Kernal adapter (right) on a short board.

Figure 27: Reset Pin on ASSY250469 (short board)

Figure 28: Reset Pin on ASSY 250425 (long board)

An EXROM connection completes the functionality. An EXROM reset can be useful for getting out of fake cartridge signature (CBM80) situations used by some games as copy protection.

It is best to tap the EXROM signal directly at the Expansion Port connector.


Figure 29: EXROM pin soldered to pin 9 of the expansion port

Figure 30: EXROM wire connected to the pin header


Figure 31: The connector for the Kernal switcher J2

Figure 32: J2 with Kernal Switcher Cable

Figure 33: A properly wired-up C64 Breadbin with the installed Kernal cable

## 5.9 Ultimate Buttons

When connected to the Ultimate 64-Elite -II, the Kernal Switcher is not required. Instead, the buttons pin header on the mainboard is controlled by the keyboard (in case this option is enabled in the Software). Since the outputs are simulated open collector, the C64 keyboard can handle the required 3.3V logic of the Ultimate 64 or the C64 ultimate.


Figure 34: Ultimate elite II buttons pin header

Figure 35: J2 with the Ultimate buttons cable

An important part of the Kernal Switcher is the jumper J4, that selects long board (no jumper placed) or short board (jumper placed).

An important part of the Kernal switcher is the J4 jumper, which selects the appropriate C64 board type:

- Long board: J4 open (no jumper installed)
- Short board: J4 closed (jumper installed)


Figure 36: Jumper J4 and the I²C Bus connector J7

The reason for this distinction is that a 27C512 64 kB EPROM on a long-board adapter can contain up to eight Kernals, whereas the first 8 kB of the EPROM on a short-board adapter—at least on the adapter I designed—is reserved for BASIC. Therefore, the short-board adapter can contain only seven Kernals.

The J4 jumper prevents the keyboard from selecting the 8 kB BASIC block as a Kernal. Without this protection, selecting that block would result in a temporary black screen.

## 5.10 The RGB LED Strip

A free pin on the Pro Micro is dedicated to controlling a WS2812B-based RGB LED strip. The color and brightness of each individual LED can be controlled independently.

The Pro Micro contains 10 different light patterns, either using a rainbow spectrum (multicolor) or a single color with varying brightness. The patterns are designed to change slowly and smoothly, without distracting or nervous effects.

The length of the LED strip can be defined in the software's source code. It should not exceed 23 LEDs.

The computer's PSU must be capable of supplying the additional current required by the RGB LED strip. At full brightness (RGBbright = 255), the strip draws approximately 400 mA of additional current. A more moderate brightness setting is RGBbright = 32, which requires approximately 50 mA extra.

The RGB strip consists of WS2812B LEDs connected in a daisy chain. Each LED has a Din (data input) and Dout (data output). The strip must be connected with the Din side to the keyboard's J5 connector (Figure 36).

Figure 37: RGB LED Circuit

The RGB LED circuit consists of only a 1000 µF electrolytic capacitor, a 470Ω resistor, and the pin header itself.

If no RGB LED strip is connected, these components are not required.


Figure 38: LED Strip Cable at J5 (Board version with hot swap sockets)

Figure 39: RGB LED Strip with soldered cable

## 5.11 I²C-Bus/OLED display

The I²C bus is a serial bus used to communicate with components, ICs, and modules within electronic devices. It can be used to connect various devices, such as displays and sensors.

I have integrated support for three different OLED displays into the Pro Micro software. The desired display can be selected in the source code.

Size | Resolution | Controller
0.91” | 128 x 32 pixel | SSD1306
0.96” | 128 x 64 pixel | SSD1306
1.3” | 128 x 64 pixel | SH1106


Figure 40: 0.91", 0.96" and 1.3" OLED Display

The display shows the currently selected Kernal and LED pattern (with software version v0.00). During startup, it displays the C64 logo and the software version.

When a RESET or EXROM RESET is triggered, the display indicates which type of reset was performed.

On an Ultimate 64, the FREEZE, MENU, and RESET button presses are also displayed.

The cable of the OLED display is a Dupont cable. It might be required to solder the cable to the display, depending on how you want to install it.

Figure 38: 0.91" OLED display with cable


Figure 39: 0.91" OLED display connected to J7

The 5mm hole in the PCB next to the left pin of the 1000µF capacitor is provided for routing the display cable through the board, if required.

# 6 Connector Pinouts

## 6.1 J1 - Keyboard Connector

2x10 box pin header 90°

Signal | Pin | Pin | Signal
GND | 1 | 2 | n.c.
RESTORE | 3 | 4 | +5V
ROW3 | 5 | 6 | ROW6
ROW5 | 7 | 8 | ROW4
ROW7 | 9 | 10 | ROW2
ROW1 | 11 | 12 | ROW0
COL0 | 13 | 14 | COL6
COL5 | 15 | 16 | COL4
COL3 | 17 | 18 | COL2
COL1 | 19 | 20 | COL7

## 6.2 J2 – Kernal Switcher

5 way pin header 90°

Pin | Kernal Switcher | Ultimate
1 | A13 | Left = uFreeze
2 | A14 | Menu = uMenu
3 | A15 | Right = uReset
4 | RESET | Not relevant
5 | EXROM | Not relevant

## 6.3 J3 & J8 – Power LED

3 way Molex KK2.54/KF2510, 90°

Pin | Signal
1 | LED+
2 | GND
3 | LED+

## 6.4 J4 – Short Board Jumper

2 way pin header 90°

Place if short board

## 6.5 J5 – RGB LED Strip

4 way pin header 90°

Pin | Signal
1 | GND
2 | Din (of LED strip)
3 | +5V
4 | GND

## 6.6 J6 – Reserved

Do not place. Reserve pins of the pro micro.

5 way pin header

Pin | Signal
1 | GND
2 | RX
3 | TX
4 | A3
5 | +5V

## 6.7 J7 – I²C Bus

4 way pin header, 90°

Pin | Signal
1 | SCL
2 | SDA
3 | +5V
4 | GND

# 7 Jumpers

## 7.1 JP1 – SW67/PREV to GND

JP1 connects switch SW67 (pin 1) to GND. This jumper is closed by default.

If no microcontroller (M2) is used, JP1 can be opened to allow SW67 to be hardwired to any other switch in the keyboard matrix.

## 7.2 JP2 – SW68/NEXT to GND

JP2 connects switch SW68 (pin 1) to GND. This jumper is closed by default.

If no microcontroller (M2) is used, JP2 can be opened to allow SW68 to be hardwired to any other switch in the keyboard matrix.

## 7.3 JP3 – Power LED

The microcontroller (M2 = Pro Micro) controls the power LED connected to J3 or J8.

If the Pro Micro is not installed and J3 or J8 is to be used for an “always-on” power LED, the corresponding jumper must be closed.

The advantage of this arrangement is that only the keyboard cable is required between the upper and lower halves of the case.

## 7.4 J4 – Short Board Jumper

See J4 – Short Board Jumper

# 8 Programming model

## 8.1 Pro Micro

Pro micro Pin | GPIO | Name | Direction | Description
1 | D0/TX | TX | Tbd | Reserved (J6 pin 3)
2 | D1/RX | RX | Tbd | Reserved (J6 pin 2)
5 | SDA/D2 | SDA | Bidir | I²C-Bus (M1 & J7 pin 2)
6 | SCL/D3 | SCL | Output | I²C-Bus (M1 & J7 pin 1)
7 | A6/D4 | /RESTORE | Input | RESTORE button (active low)
8 | D5 | SND_OUT | Output | Output for piezo buzzer
9 | A7/D6 | RGBOUT | Output | Output for RGB LED strip (J5 pin2)
10 | D7 | /INT6 | Input | Interrupt from PCF8575 GPIO Module
11 | A8/D8 | /C64RES | Bidir* | Signal for resetting the C64 and shift lock status, active low
12 | A9/D9 | PWRLED | Output | Output for power led (J3&8), active high
13 | D10/A10 | /EXROM | Bidir* | EXROM signal, active low
14 | D16 | KSW_A15 | Bidir* | Kernal address bit A15/ultimate freeze
15 | D14 | KSW_A14 | Bidir* | Kernal address bit A14/ultimate menu
16 | D15 | KSW_A13 | Bidir* | Kernal address bit A13/ultimate reset
17 | A0 | /SHORT_BRD | Input | J4 short board jumper, active low
18 | A1 | /P1 | Input | SW67/PREV switch, active low
19 | A2 | /P2 | Input | SW68/NEXT switch, active low
20 | A3 | A3 | tbd | Reserved (J6 pin 4)

Bidir*: A pin marked with an asterisk is designed to emulate an open-collector GPIO. When the signal is low, the GPIO pin actively drives the output low. When the signal is “high,” the GPIO pin is left floating (i.e. configured as an input). A pull-up resistor elsewhere in the circuit then pulls the signal to the required high level.

This is important when a digital signal can have multiple sources, such as /C64RES, which can originate from the C64 reset circuit, a reset button, or the Pro Micro.

It is particularly important for the Ultimate button signals, because the Ultimate 64/C64U uses 3.3 V logic levels, which are not necessarily 5 V tolerant.

Note: GPIO stands for General Purpose Input/Output. A GPIO pin does not have a fixed function; its operation is determined by the circuit to which it is connected.

## 8.2 Keyboard Matrix/PCF8575

The PCF8575 module (M1) is a 16-bit GPIO expander connected via the I²C bus.

Its primary purpose is to detect the keyboard matrix scan signals. If these signals are not detected, the Pro Micro uses the PCF8575 to actively scan the keyboard matrix at 125 times per second.

This provides the functionality required to use the keyboard as a USB keyboard with a keyboard layout suitable for VICE (C64 emulator).

M1 GPIO | Signal | Discription
P00 | ROW0 | Keyboard return signals: These signals are read to detect the switches of the keyboard matrix, that are pressed.
P01 | ROW1
P02 | ROW2
P03 | ROW3
P04 | ROW4
P05 | ROW5
P06 | ROW6
P07 | ROW7
P10 | COL0 | Keyboard scan signal: A bit pattern is written to the columns of the keyboard matrix.
P11 | COL1
P12 | COL2
P13 | COL3
P14 | COL4
P15 | COL5
P16 | COL6
P17 | COL7

The GPIO slave address is selected using the solder bridges on the bottom side of the module (see Figure 20). The correct address is 0x20.

# 9 Keycap Making

Options for obtaining or making the keycaps will be described or listed in the /Keycaps/pdf/ subfolder.

At the time of writing, some options are still being evaluated.

# 10 3D Printables

A mounting frame is required to install the keyboard inside a C64 or C64C. It can be found in the /3D printables/Mounting Frame/ subfolder.

An optional stiffener can be screwed to the solder side of the PCB. In my experience, it is not required, since the PCB already provides sufficient stability when screwed to the mounting frame.

A separate plate is not required. A plate is the level approximately 5 mm above the PCB, with cutouts for the keyboard switches. It is normally used to align 3-pin switches. Since 5-pin switches are recommended for this keyboard, a plate is not necessary.

There are, however, plates that serve as the top cover of the USB keyboard case. These can be found in the /3D printables/USB Keyboard Case/ subfolder.

There are two types of plate: regular and classic. The classic plate is only suitable if you want to use original Commodore keycaps from the 20th century. All other DIY and modern Commodore keycaps require the regular plate. The difference is the cutout and switch position for the 1.5U keycaps (Shift, Control, Restore, F-keys, etc.).

Both the mounting frame and the USB keyboard case are designed to fit on a 25 cm-wide 3D printer bed.

Figure 42: 3D printable mountinmg frame (top) and USB keyboard case (bottom)

# 11 Assembly

## 11.1 The Bill of Material

The complete circuit is divided into subcircuits, which can be populated optionally depending on the individual application.

The C64 keyboard PCB can always be fully populated, as none of the optional circuits interfere with the other functions, even if they are not used. The only disadvantage is that the keyboard will be slightly more expensive than necessary for a particular application.

The BOM (Bill of Materials) represents the fully populated version of the PCB. However, you may not require all components, depending on your intended use case.

The components are assigned to functional groups:

Short | Group
SL | Shift Lock Circuit
CTRL | Controller/pro micro
SPK | Piezo Buzzer
USBKB | USB-Keyboard
KSW | Kernal Switcher
RGB | RGB LED strip
I²C | I²C (OLED) Display

The switches and the keyboard connector J1 are always required.

The Shift Lock circuit should normally be populated, unless you find Shift Lock annoying. If it is omitted, the Shift Lock key has no function.

Every other option requires the controller (CTRL) / Pro Micro.

The SPK (piezo buzzer) is recommended. It provides audible feedback for the status of a reset and for the additional PREV and NEXT switches.

If you do not intend to use the keyboard as a USB keyboard, you can leave out the USBKB group. Including these components does not cause any problems, however. For USB keyboard operation, a Pro Micro with a USB-C connector is highly recommended.

The Kernal switcher requires only a small number of additional components. In addition to everything marked KSW in the BOM, the two additional switches SW67 and SW68 (PREV and NEXT) are required to switch between the Kernals.

The RGB LED strip is optional, as are the components marked RGB. If these components are populated but the LED strip is not connected, they do not cause any problems. SW67 and SW68 are required to switch between the LED patterns. The default state is off—without the switches, there is no way to activate the lighting.

The I²C bus is intended for connecting an OLED display. It could also be used for other devices, such as IC temperature sensors, but this functionality is not implemented in the firmware yet. Since an OLED display requires either a transparent case or a suitable cutout, it is entirely optional.

## 11.2 Assembly of the PCB

### 11.2.1 SMD component

Not everybody likes SMD components, but in my opinion they are required for this project. I solder the SMD components with solder paste and a hot plate, but neither is required. You do not need a fancy hot-air rework station, either.

The components used are 0805 passives (which are still a reasonable size), SOT-23 transistors, and an SO-14 IC. For most of my life, I have soldered components of this size with normal solder and a soldering iron. When soldering SMD components, the use of additional flux (gel or liquid) is highly recommended.

If you are concerned about the component size because your eyes are over 40 years old, consider getting a headband magnifier. It can make a significant difference when working with small components.

Keep in mind that small components can easily get lost. Order a few more than specified in the BOM. There are already plenty of chip resistors orbiting the Earth after jumping off my tweezers.

Another option is to order the PCBs with the SMD components already assembled. I have only used this service with JLCPCB so far. A pick-and-place file is included in the project data in the format preferred by JLCPCB, as is the BOM.

Since I have not yet ordered assembled PCBs, I cannot say how much additional preparation is required. Both files will need to be edited. First, the non-SMD components should be removed. It is unlikely that JLCPCB will not have the required components available. Once the component placement is displayed, check the orientation carefully. In particular, the diodes, transistors, and ICs may not be oriented correctly and will need to be checked and corrected.

If you decide to place the SMD components yourself, solder them first, before installing the larger components. A very fine soldering tip is not necessary. I prefer a beveled tip approximately 2 mm wide as my general-purpose tip and rarely use anything else. It is wider than the pin spacing of an SO-14 IC, but that is not a problem:

The flux will do the magic!

I have to admit that I used soldering tips that were far too fine for at least 40 years.

### 11.2.2 The Through Hole Components

#### 11.2.2.1 The Pro Micro (M2)

The Pro Micro usually comes with two 12-pin headers that are not soldered. The module is mounted using two corresponding socket strips, which are soldered to the keyboard PCB. This method makes it easier to install the module with properly aligned pins.

1. Plug the pin headers into the socket strips.
2. Insert the **socket strips—not the pin headers—**into the keyboard PCB.
3. Place the Pro Micro onto the pin headers, with the components facing upward.
4. Solder the pin headers to the Pro Micro.
5. Solder the socket strips to the keyboard PCB on the solder side. The USB connector must face the edge of the PCB, as indicated by the silkscreen.

#### 11.2.2.2 The GPIO extension: PCF8575 Module

This module is, as stated previously, only required for the USB keyboard version.

The first step is to set the I²C address bits correctly. On the solder side of the module, there are three solder bridges labeled A0, A1, and A2. All three solder bridges must connect to GND; otherwise, the Pro Micro cannot communicate with the module. See Figure 20.

The module comes with two 10-pin headers. It also includes a 5-pin 90° angled header, which is not suitable for this project. Please use the straight 5-pin header specified in the BOM instead.

As with the Pro Micro, the module should be installed with the pins properly aligned. The installation procedure is the same as for the Pro Micro.


Figure 43: GPIO module - headers inserted (pin header up, socket stripe down

Figure 44: GPIO module before soldering


Figure 45: GPIO module after soldering (Held by blue tack)

For temporarily holding components in position, I use the popular Blu Tack. It is sufficiently sticky, can be reused many times, and is particularly useful for components that tend to fall out when the PCB is flipped over for soldering.

#### 11.2.2.3 Remaining components

It does not matter whether the other through-hole components are soldered before or after the modules.

The switches should be installed last.

#### 11.2.2.4 Stabilizers

It is a good idea to install the stabilizers before soldering in the switches. This leaves enough space to apply the moderate amount of force required to install them.

The wire of the 7U stabilizer runs above the spacebar switch, while the wire of the 2U stabilizer runs below the RETURN switch (see Figure 44).

Figure 46: 9U stabilizer

9U Stabilizer:
The 9U stabilizer is only required if you want to use classic keycaps.

To make a 9U stabilizer, take another stabilizer and bend the replacement wire according to drawing 223-3-03-01 in the /9U_stabilizer/ subfolder. The required material is 1.5 mm spring-steel wire (see Figure 43). You will also find a documentation about making a 9U stabilizer wire in the said subfolder.

Keep the required bend radius in mind. The stabilizer is quite tolerant of small deviations, so making the 9U wire is not particularly difficult. Nevertheless, it is a good idea to test the fit before final assembly.

Note: The C64U and Blingboard64 space bars use a 7U stabilizer, which is relevant if you intend to use these keycaps.


Figure 47: Keyboard with stabilizers, switches already installed

#### 11.2.2.5 Switches and SHIFT LOCK LED

Before soldering the keyboard switches, check whether the LED should be installed before or after the Shift Lock switch.

There are generally two types of switches:

- On some switches, the LED is installed above the switch.
- Switches with a light guide can have the LED installed underneath. In this case, the light guide must first be removed by pressing it out from below, and the LED must be soldered before the switch is installed.

The LED is polarized. The shorter pin is the cathode (-) and the longer pin is the anode (+).

The high-brightness LED specified in the BOM can be somewhat confusing because its internal construction may make the polarity appear different. Use the pin lengths to determine the polarity, not the internal appearance of the LED.

The PCB silkscreen indicates the correct polarity. Unfortunately, on earlier PCB revisions this marking is covered by the switch once the switch has been installed. The polarity issue is corrected in later PCB revisions.

The anode (+) points toward the RUN/STOP key.

If your switches have light guides, remove the light guide only from the SHIFT LOCK switch. The light guides in all other switches should remain installed.

Figure 48: left to right: Switch with top entry LED configuration, with light guide, light guide removed

# 12 Cable Making

## 12.1 The Ribbon Cable

There is one ribbon cable: the keyboard cable connecting the keyboard to the C64 keyboard connector PCB (see drawing no. 224-3-01-0*, file /C64 Keyboard Connector PCB/Rev. 0/pdf/KB-Cab.pdf).

The cable uses a 2×10-way IDC receptacle on one end and a MicroMatch (IDC) connector on the other. The only tool required is a small vice.

Insert the cut ribbon cable into the connector, making sure that the red wire (wire no. 1) is aligned with pin 1, which is marked by a triangle/arrow on the connector. Then compress the connector in the vice.

Note that the 2×10-way connector has a strain relief. This causes the connector to be rotated by 180° when the strain relief is installed.


Figure 49: IDC receptacle - ribbon cable aligned

Figure 50: IDC receptacle in the vice, before compressing


Figure 51: IDC receptacle - strain relief installed

The MicroMatch connector has a nipple that marks pin 1. There is no strain relief for this connector.

When compressing the connector with a vice, take care not to break off the pin-1 marking nipple.

Figure 52: MicroMatch connector in vice with adjusted ribbon cable (


Figure 53: MicroMatch connector properly installed

## 12.2 The Dupont Cable(s)

The cables are designed to work with ready-made Dupont cables, which are readily available. These are ribbon cables with pre-crimped single-pin female Dupont connectors.

You will need 40 cm cables.

The simplest solution is to tear off the required number of individual wires from the ribbon cable and use them as they are.

Figure 54: Ready-made Dupont cable (the length in the picture is short for photographic purposes)

A better solution is to use additional Dupont crimp housings. Remove the individual single-pin housings from the pre-crimped wires and replace them with 5-pin and 3-pin housings as required.

This method does not require a crimping tool, since the wires are already crimped. It also has the advantage of keeping the wires grouped correctly, making it much less likely that the pins will be mixed up.

The required Dupont housings are commonly available in assortment boxes.


Figure 55: Dupont connector assortment box

For cables made to exactly the required length, you can use a crimp tool and crimp the terminals yourself.

The main problem with crimping Dupont terminals is that many tools are marketed as “Dupont” crimp tools but are not actually suitable for these terminals. The tool must form the insulation crimp correctly so that the finished terminal fits properly into the crimp housing.

The only crimp tool for Dupont terminals that I have used successfully is the IWISS SN-025.

Figure 56: IWISS SN-025 crimp tool

The choice is yours.

In my opinion, buying a crimp tool solely for this project does not make much sense if it is going to end up as unused drawer clutter. However, if you intend to make your own crimped cables for other projects as well, I can recommend this tool.

Dupont assortment boxes are the simplest way to obtain all the crimp housings you need, typically including 3-way, 5-way, and optionally 4-way housings.

# 13 Wiring Up the Keyboard

## 13.1 USB Keyboard

The USB keyboard does not require any external wires.

## 13.2 Keyboard Matrix

The keyboard Matrix is wired to the C64 mainboard keyboard connector through the C64 Keyboard Connector PCB (project no. 224 in this repository). See Figure 12.

## 13.3 Kernal Switcher

The Kernal Switcher J2 is connected to the Kernal Adapter and the mainboard via the cable from drawing 223-3-01-00. See chapter 5.8, Figure 23, Figure 29 and Figure 30.

## 13.4 Ultimate Buttons

In Ultimate mode, the Kernal Switcher J2 can control the buttons pin header on the Ultimate/C64 Ultimate buttons pin header via the cable from drawing 223-3-02-00.

See chapter 5.9, Figure 31 and Figure 32.

## 13.5 OLED Display (optional)

The OLED displays have different pin outs. Just connect VCC to +5V, GND to GND, SDA to SDA, SCK to SCK. Use Dupont cables (self-fabricated or bought). See chapter 6.11.

## 13.6 The LED Strip cable (optional)

The LED strip cable is soldered to the WS2812B LED strip (see Figure 38 and Figure 39).

# 14 Series Production

If you plan to produce this project in series, the hot-swap version might be a good choice, as most of the components are SMD and can be machine-placed and soldered. Only the connectors and the sockets for the Pro Micro and GPIO module need to be soldered by hand.

The /JLCPCB Assembly/ folder contains a BOM and a pick-and-place file (CP1) in a format compatible with the JLCPCB PCBA (PCB assembly) process. It might still require some work to get the assembly on track, though.

# 15 Product References and Disclaimer

Throughout this documentation, I mention specific products, brand names, and suppliers. These references are provided solely for informational purposes and are not intended as advertising or endorsements. I have not received any compensation or other benefits for mentioning them. I refer to these products and suppliers simply because I have used them myself and can therefore share my personal experience with them.

# 16 Revision History

## 16.1 Rev. 0

- First prototype: requires a botch wire for the shift lock circuit. Requires a Pro Micro controller.

## 16.2 Rev. 1

- Shift Lock debounce circuit changed
- Power-on Reset added
- This requires a botch to suppress the power-on pulse. The problem is only effective, if no Pro Micro is populated

## 16.3 Rev. 2

- The Power-on Reset circuit (Shift Lock) now works properly.

C64KB_ModD.docx 09.10.2026 17:22 Drafted by Sven Petersen Page 2 of 2 Doc.-No.: 225-6-01-02

C64KB_ModD.docx 09.10.2026 17:22 Drafted by Sven Petersen Page 1 of 1 Doc.-No.: 225-6-01-01

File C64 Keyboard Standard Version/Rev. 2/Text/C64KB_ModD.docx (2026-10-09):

C64 Mechanical Keyboard & Kernal Switcher

Standard Version Rev. 2

Module Description

# 1 Introduction

This project is a mechanical keyboard for the C64 or Ultimate 64, based on Cherry MX-compatible switches.

Mechanical keyboards are not a cheap alternative to the original keyboards. The switches alone (66 + 2) range from about €0.25 to over €1 per switch. The stabilizers for the space bar and Return key cost at least €8, while good-quality ones can easily cost over €20. A set of blank keycaps costs about €30. The PCB is surprisingly inexpensive, at less than €5 plus shipping and import taxes when ordered from JLCPCB.

Since it was possible, I added some functions that I like and that make this keyboard different from other mechanical keyboards for the C64:

- Reset: The keyboard can generate RESET and EXROM RESET signals.
- Kernal switching: The keyboard can switch between multiple Kernals on an EPROM Kernal adapter.
- OLED display: An I²C OLED display can be connected to the keyboard.
- Piezo buzzer: The keyboard includes a piezo buzzer for signaling.
- USB keyboard: The keyboard can be operated as a USB keyboard for VICE and BMC64.
- RGB lighting: The keyboard can produce a light show using a WS2812B RGB LED strip.
- Power LED: The C64's power LED can be connected to the keyboard on either the left or right side and can be made to blink.
- Additional buttons: Two additional buttons beside the shorter space bar provide additional control functions.

The software runs on a Pro Micro module, which is programmed using the free Arduino IDE via a USB cable (USB-C or micro-USB).

The keyboard does not require a metal positioning plate above the keyboard PCB because it uses 5-pin switches: two electrical pins and three centering pins. A 3D-printed frame holds the PCB in position and interfaces with the C64 case or, in the case of a C64C, the keyboard brackets.

The PCB is attached to the frame using 16 C 2.2 × 6.5 mm screws. The resulting assembly is sufficiently rigid to provide a wobble-free typing experience.

# 1 The Keycaps

## 1.1 General considerations

New keycaps have always been problematic. At least one crowdfunding campaign has failed. There are several ways to obtain suitable keycaps for this keyboard:

- Use old/original keycaps with an adapter pin, available from Retro Fuzion (https://www.retrofuzion.com/products/mechboard-64-injection-moulded-keycap-adapter-kit).
- C64 Ultimate-compatible keycaps from CBMStuff (https://www.cbmstuff.com/?utm_source=chatgpt.com) may become available in the future.
- Apply the legends onto available blank keycaps.

The keyboard requires:

- 54 × 1U keycaps + 2 × 1U keycaps for PREV and NEXT
- 8 × 1.5U keycaps
- 1 × 2U keycap (RETURN)
- 1 × 7U space bar

The keycaps need legends to be printed on them, except for the space bar.

For more information about the keycaps, please see the /Keycaps/ subfolder. It contains documentation on how to make or obtain suitable keycaps.

## 1.2 The 1.5U Key Problem (solved)

The problem is that original and modern 1.5U keycaps—such as those used for the F-keys, Shift, Control, and Restore—are different (Figure 1).

Modern keycaps, such as blank keycaps or those from the C64U, have their switch stem—the part on the underside of the keycap that connects to the switch plunger—located in the center.

Original keycaps have two switch-stems, each located 4.75 mm off-center.


Figure 1: Old versus new 1.5U keycap

The solution is that the switches can be installed in either the off-center or center position (see Figure 2). To achieve this, the switches are simply rotated by 90°. This does not affect their operation, since the keycap connector is symmetrical.

The SW**A position is the center position, while SW** is the original off-center position.

Figure 2: Alternative switch positions for the 1.5U keys

Now it is time to talk about the U. It is a unit used to specify key spacing.

Since the early 20th century, typewriter keys have had a spacing of ¾ inch (19.05 mm). This did not change with the transition to computer keyboards. The spacing was defined as 19 ± 1 mm in DIN 2111 from 1927, DIN 2139 from 1976, and ISO 1091 from 1977.

A 1U keycap fits a key with a 1U spacing. 1.5U keycaps are used for the SHIFT, CONTROL, RESTORE, and F-key keys.

Figure 3: An original F7/F8 keycap with an adapter pin in position. The switch is mounted respectively (PCB Rev. 1 Hot Swap)


Figure 4: The original keycap mounted on switch

## 1.3 The Space Bar, PREV, NEXT

The original space bar is 9U wide, which I could not find available anywhere. I therefore decided to use a 7U space bar, which is available from several sellers on AliExpress. The remaining 2U are used for two additional 1U keys, PREV and NEXT, which can be used for switching between Kernals or LED modes.

## 1.4 Keycap Profiles

There are several keycap profiles available (Figure 5). Except for the CBMStuff keycaps, all other profile types differ from the original keycaps. Some profiles use a different keycap shape for each row of the keyboard, which would require ten different types of keycaps: four different 1U keycaps, four different 1.5U keycaps, one 2U keycap, and one space bar.

I have only looked for blank keycaps on AliExpress, and all the ones I found were DSA profile keycaps. At least this profile offers all the required keycap sizes.

The material of choice is PBT. It is well suited for applying legends, including processes involving heat, and it also has a pleasant feel.

Figure 5: Different keycap profiles

# 2 The Switches

There are many mechanical switches available, offering different click characteristics and actuation-force profiles. I am not a “keyboard enthusiast,” so I do not have any particular preferences in this regard. I have tried switches ranging from budget models to somewhat more expensive ones and found them all quite good—and definitely better than the original keyboard. Even the €0.25 switches were perfectly acceptable.

Most importantly, the switches must be 5-pin switches. All switches have two electrically relevant pins and one plastic pin for centering. Since I did not design a separate mounting plate for this keyboard, the switches rely on two additional plastic pins, making a total of five pins, to position themselves accurately.

A mounting plate is a purely mechanical component made of metal, plastic, or FR4 (the material used for PCBs). It provides a second level, 5 mm above the actual PCB, with square cutouts for the switch bodies.

I once built a keyboard for 3-pin switches using a second PCB as the mounting plate. Due to the milled cutouts, this was several times more expensive than the keyboard PCB itself. Therefore, 5-pin switches are by far the better choice for this design.

Figure 6: 3 pin versus 5 pin switches (right)

When choosing the switches, avoid 3-pin switches as well as magnetic switches. Magnetic keyboard switches require Hall-effect sensors, which are not supported by this PCB.

The Shift Lock key does not latch. As far as I know, latching keyboard switches are no longer manufactured. Even if you can still find them, they are prohibitively expensive, costing more than €30 each.

# 3 Stabilizers

The original space bar stabilizer consists of a spring-steel wire anchored to the plastic frame and guided through slots in two plastic pins located on the left and right underside of the space bar. It prevents the long keys from tilting or binding when pressed.


Figure 7: Stabilizer below space bar and RETURN keycap

The space bar stabilizer is essential; for the RETURN key, it is optional in my opinion.

The stabilizers are the most expensive components of this project. You can expect to pay €8 to more than €20 for both. It is important to buy a 7U stabilizer for the space bar—not a 6.25U stabilizer—and a 2U stabilizer for the RETURN key. They are often sold as a set.

Screw-in stabilizers are the best choice. There are also stabilizers that snap into the holes in the PCB; both types are suitable. Make sure the stabilizers are designed for a 1.6 mm PCB, not a 1.2 mm PCB.

Plate-mount stabilizers are not suitable, since this design does not use a mounting plate.

Figure 8: Stabilizer with mounting screw vs snap-in

The stabilizers are mounted in different orientations due to space constraints. The wire runs above the space bar switch and below the RETURN switch (Figure 9).


Figure 9: Stabilizers mounted on the keyboard

Figure 10 shows a screw-in stabilizer mounted on the bottom side of the PCB. One side has a hook that must be hooked into place first. The other side fits through the corresponding mounting hole. Once the stabilizer sits flush against the PCB, it can be secured with the screw. The plastic insulating washer should be used.

A 9U stabilizer is only required for the original spacebar. The C64 Ultimate and Blingboard64 spacebar works with a 7U stabilizer.

Find additional information in the /9U_stabilizer/ subfolder of this repository.

Figure 10: Bottom side of the mounted stabilizer (screw mount)

# 4 The Circuit

## 4.1 Block Diagram

This is the block diagram of the C64 keyboard project. The original keyboard consists only of the switch matrix (without PREV and NEXT), the interconnections, and the keyboard connector at the end of the cable.


Figure 11: Block Diagram of the C64 Keyboard

The circuit is scalable to suit your needs. The minimum configuration consists of the switch matrix (without PREV and NEXT), the keyboard connector, and the Shift Lock circuit.

If you do not want the beeps, simply leave out the piezo buzzer. If you do not need a display, do not connect one; the software must then be configured accordingly.

If you do not want to use the keyboard as a USB keyboard, the GPIO module is not required.

## 4.2 Keyboard Matrix and Output Connector

The key switches are connected in an 8 × 8 matrix, consisting of 8 rows and 8 columns. The RESTORE key has a dedicated pin on the keyboard connector. This is identical to the circuit of the original keyboard.

The output connector is a 2 × 10-pin, 90° box header. I chose this type of connector because it connects to the ribbon cable via an IDC socket connector. This requires only a vice to compress the connector and does not require any specialized crimping tools.

Figure 12: The keyboard connector with the ribbon cable and the connector PCB (Rev 1 with hot swap sockets)

## 4.3 The SHIFT LOCK Switch

The SHIFT LOCK key does not latch like on an original keyboard. As far as know, latching Cherry MX compatible keyboard switches are no longer being manufactured. Even in case you find a used one of them, they are prohibitively expensive (over 30€ each).

This is the reason for using a standard switch with a little circuit. In Rev. 0, this is not 100% reliable. Sometimes the keyboard starts up with shift lock on. The circuit works perfectly when powering the keyboard from a lab power supply. Only installed in a C64, it sometimes does not work properly. The problem will be resolved in a later revision of the PCB. There is a simple fix with a botch wire, though (see The Power-On Reset Botch).

The status of the SHIFT LOCK switch is indicated by an LED, which is attached to this switch. It should be a high brightness LED, so even in daylight it can be noticed.

The Power-On Reset (POR) circuit is only required if the keyboard is intended to be used without the Pro Micro controller, as a “passive” matrix keyboard.

An installed Pro Micro resets the Shift Lock circuit. Therefore, if M2 is installed, the “expensive” POR circuit (IC3) can be left unpopulated.

Figure 13: SHIFT LOCK status LED

I have tried normal LEDs in this position. In a dimly lit room, there was no problem, but in a well-lit room, their visibility was poor.

The current-limiting resistor for the LED is R1. It is calculated as 100 Ω for an LED with a 2 V forward voltage drop (red or green) and a forward current (IF) of 30 mA.

A standard LED may not be suitable for this relatively high current. A lower current, and therefore a higher resistor value (e.g. 150 Ω), may be more appropriate for normal LEDs.


Figure 14: Shift Lock circuit Rev. 1, POR (power-on reset) not populated

## 4.4 The Micro Controller Module

The keyboard controller is a Pro Micro, which is available for about €5 and can be programmed via a USB cable (micro-USB or USB-C, depending on the model).

I strongly recommend a Pro Micro with a USB-C connector, as these are more robust in several respects. It is also preferable to choose a model where the metal connector bracket is secured with through-hole soldering rather than only with SMD pads. I have already broken off half a dozen micro-USB connectors myself.

Figure 15: pro micro with a USB-C connector

The Pro Micro is programmed using the Arduino IDE via a USB cable. It is configured using #define statements at the beginning of the source code. Options that are not required can simply be commented out.

Adding // at the beginning of a line turns it into a comment, so configuring the software should be manageable even without a PhD in computer science.


Figure 16:The pro micro on the PCB. The 10k resistors are required.

Without the Pro Micro, there is no Kernal switching, OLED display, PREV and NEXT keys, piezo buzzer, or LED strip. That is perfectly acceptable if these additional features are not required.

## 4.5 The Piezo Buzzer

The piezo buzzer is a small speaker that is not exactly Hi-Fi, but it provides useful audible feedback.

It emits a beep when RESTORE has been held long enough to trigger a C64 reset, and two beeps when it has been held long enough to trigger an EXROM reset. Different beep patterns are used when PREV or NEXT is pressed.

It can also play the “Are You Keeping Up…” jingle during startup if the corresponding #define statement is enabled.

Figure 17: The speaker (piezo buzzer) circuit.

## 4.6 The Power LED

There are two connectors for the power LED, one on each side of the PCB (J8 and J3). This allows you to choose the side that best suits your installation and reduces the number of cables between the top and bottom of the keyboard to the keyboard cable alone.

The power LED is controlled by the Pro Micro and blinks in sync with the piezo buzzer beeps. This provides useful visual feedback, especially in noisy environments where the buzzer may be difficult to hear.


Figure 18: The power LED connectorJ8 (top left)

If there is no controller, the LED can be powered permanently by closing the JP3 solder bridge on the top side of the PCB. Only close JP3 if no Pro Micro is installed; otherwise, the controller may be damaged.

The current-limiting resistor is R11, which is 330 Ω by default. This provides a forward current of approximately 10 mA for a standard red LED.

Only one power LED should be used. Using two LEDs may cause them to be dim, have different brightness levels, or fail to light at all.

## 4.7 The GPIO Module

The purpose of the GPIO module (M1) is to provide the Pro Micro with the additional I/O pins required to scan the keyboard matrix 125 times per second when the keyboard is used as a USB keyboard for VICE.

In all other operating modes, the GPIO module is not required. Consequently, the pull-up resistor network RN1 is not required either.

Figure 19: The PCF8575 GPIO module

The module is connected to the pro micro via the I²C bus. To access any IC or module on this bus, a properly set I²C slave address is required to properly access the module. This slave address of the module is configured by solder bridges on the bottom side of the module PCB. They (A0…2) should all be closed to the GND side (Figure 20). That sets the slave address to 20HEX/0x20.

Figure 20: properly configured PCF8575 module


Figure 21: The µC circuit including the PCF8575 GPIO module M1 and resistor network RN1

## 4.8 The Kernal Switcher

The Kernal switcher is controlled by the RESTORE, PREV, and NEXT keys. The switching logic is handled by the Pro Micro controller.

It can switch between the Kernals stored in an EPROM on a Kernal adapter (Figure 22). A 27C512 EPROM can hold up to eight Kernals.

Figure 22: Kernal Adapter

I have created two different versions, both of which are available on GitHub:

- C64 Kernal Adapter/Switch Long Board (https://github.com/svenpetersen1965/C64-Kernal-Adapter-Switch-Long-Board)
- C64 Kernal Adapter/Switch Short Board (https://github.com/svenpetersen1965/C64-Kernal-Adaptor-Switch-short-board-)

The reason for the two different versions—for short boards (ASSY 250469) and long boards (all other ASSY numbers) is that the short boards use a combined Kernal and BASIC ROM (16 kB), whereas the long boards have two separate ROMs (8 kB each).

A 27C512 Kernal EPROM has a capacity of 64 kB and can therefore hold eight 8 kB Kernals on a long board. On a short board, the lowest 8 kB memory slot contains the BASIC ROM, leaving the subsequent seven slots for Kernals.

The three highest address bits, A[13..15], are used to select the active Kernal. The Kernal adapters mentioned above have jumpers that normally select the Kernal. However, these address lines can also be controlled by the keyboard. The lower row of pins on the adapter, from left to right, is A13, A14, A15, and +5 V. The +5 V connection is not used.

A cable from the keyboard to the Kernal adapter (Figure 23, yellow/orange/red wires: A15, A14, A13) already provides the three address signals. A RESET connection is also required.

RESET can be tapped at a suitable point near pin 3 of the user port. Usually, there is a via nearby that can be used to solder in a single-pin header. This is the grey wire in the upper part of Figure 23

Figure 23: Character set (left) and Kernal adapter (right) on a short board.

Figure 24: Reset Pin on ASSY250469 (short board)

Figure 25: Reset Pin on ASSY 250425 (long board)

An EXROM connection completes the functionality. An EXROM reset can be useful for getting out of fake cartridge signature (CBM80) situations used by some games as copy protection.

It is best to tap the EXROM signal directly at the Expansion Port connector.


Figure 26: EXROM pin soldered to pin 9 of the expansion port

Figure 27: EXROM wire connected to the pin header


Figure 28: The connector for the Kernal switcher J2

Figure 29: J2 with Kernal Switcher Cable


Figure 30: A properly wired-up C64 Breadbin with the installed Kernal cable

## 4.9 Ultimate Buttons

When connected to the Ultimate 64-Elite -II, the Kernal Switcher is not required. Instead, the buttons pin header on the mainboard is controlled by the keyboard (in case this option is enabled in the Software). Since the outputs are simulated open collector, the C64 keyboard can handle the required 3.3V logic of the Ultimate 64 or the C64 ultimate.

Figure 31: Ultimate elite II buttons pin header


Figure 32: J2 with the Ultimate buttons cable

An important part of the Kernal Switcher is the jumper J4, that selects long board (no jumper placed) or short board (jumper placed).

An important part of the Kernal switcher is the J4 jumper, which selects the appropriate C64 board type:

- Long board: J4 open (no jumper installed)
- Short board: J4 closed (jumper installed)

Figure 33: Jumper J4 and the I²C Bus connector J7

The reason for this distinction is that a 27C512 64 kB EPROM on a long-board adapter can contain up to eight Kernals, whereas the first 8 kB of the EPROM on a short-board adapter—at least on the adapter I designed—is reserved for BASIC. Therefore, the short-board adapter can contain only seven Kernals.

The J4 jumper prevents the keyboard from selecting the 8 kB BASIC block as a Kernal. Without this protection, selecting that block would result in a temporary black screen.

## 4.10 The RGB LED Strip

A free pin on the Pro Micro is dedicated to controlling a WS2812B-based RGB LED strip. The color and brightness of each individual LED can be controlled independently.

The Pro Micro contains 10 different light patterns, either using a rainbow spectrum (multicolor) or a single color with varying brightness. The patterns are designed to change slowly and smoothly, without distracting or nervous effects.

The length of the LED strip can be defined in the software's source code. It should not exceed 23 LEDs.

The computer's PSU must be capable of supplying the additional current required by the RGB LED strip. At full brightness (RGBbright = 255), the strip draws approximately 400 mA of additional current. A more moderate brightness setting is RGBbright = 32, which requires approximately 50 mA extra.

The RGB strip consists of WS2812B LEDs connected in a daisy chain. Each LED has a Din (data input) and Dout (data output). The strip must be connected with the Din side to the keyboard's J5 connector (Figure 36).


Figure 34: RGB LED Circuit

The RGB LED circuit consists of only a 1000 µF electrolytic capacitor, a 470Ω resistor, and the pin header itself.

If no RGB LED strip is connected, these components are not required.

Figure 35: LED Strip Cable at J5 (Board version with hot swap sockets)


Figure 36: RGB LED Strip with soldered cable

## 4.11 I²C-Bus/OLED display

The I²C bus is a serial bus used to communicate with components, ICs, and modules within electronic devices. It can be used to connect various devices, such as displays and sensors.

I have integrated support for three different OLED displays into the Pro Micro software. The desired display can be selected in the source code.

Size | Resolution | Controller
0.91” | 128 x 32 pixel | SSD1306
0.96” | 128 x 64 pixel | SSD1306
1.3” | 128 x 64 pixel | SH1106

Figure 37: 0.91", 0.96" and 1.3" OLED Display

The display shows the currently selected Kernal and LED pattern (with software version v0.00). During startup, it displays the C64 logo and the software version.

When a RESET or EXROM RESET is triggered, the display indicates which type of reset was performed.

On an Ultimate 64, the FREEZE, MENU, and RESET button presses are also displayed.

The cable of the OLED display is a Dupont cable. It might be required to solder the cable to the display, depending on how you want to install it.


Figure 38: 0.91" OLED display with cable

Figure 39: 0.91" OLED display connected to J7

The 5mm hole in the PCB next to the left pin of the 1000µF capacitor is provided for routing the display cable through the board, if required.

# 5 Connector Pinouts

## 5.1 J1 - Keyboard Connector

2x10 box pin header 90°

Signal | Pin | Pin | Signal
GND | 1 | 2 | n.c.
RESTORE | 3 | 4 | +5V
ROW3 | 5 | 6 | ROW6
ROW5 | 7 | 8 | ROW4
ROW7 | 9 | 10 | ROW2
ROW1 | 11 | 12 | ROW0
COL0 | 13 | 14 | COL6
COL5 | 15 | 16 | COL4
COL3 | 17 | 18 | COL2
COL1 | 19 | 20 | COL7

## 5.2 J2 – Kernal Switcher

5 way pin header 90°

Pin | Kernal Switcher | Ultimate
1 | A13 | Left = uFreeze
2 | A14 | Menu = uMenu
3 | A15 | Right = uReset
4 | RESET | Not relevant
5 | EXROM | Not relevant

## 5.3 J3 & J8 – Power LED

3 way Molex KK2.54/KF2510, 90°

Pin | Signal
1 | LED+
2 | GND
3 | LED+

## 5.4 J4 – Short Board Jumper

2 way pin header 90°

Place if short board

## 5.5 J5 – RGB LED Strip

4 way pin header 90°

Pin | Signal
1 | GND
2 | Din (of LED strip)
3 | +5V
4 | GND

## 5.6 J6 – Reserved

Do not place. Reserve pins of the pro micro.

5 way pin header

Pin | Signal
1 | GND
2 | RX
3 | TX
4 | A3
5 | +5V

## 5.7 J7 – I²C Bus

4 way pin header, 90°

Pin | Signal
1 | SCL
2 | SDA
3 | +5V
4 | GND

# 6 Jumpers

## 6.1 JP1 – SW67/PREV to GND

JP1 connects switch SW67 (pin 1) to GND. This jumper is closed by default.

If no microcontroller (M2) is used, JP1 can be opened to allow SW67 to be hardwired to any other switch in the keyboard matrix.

## 6.2 JP2 – SW68/NEXT to GND

JP2 connects switch SW68 (pin 1) to GND. This jumper is closed by default.

If no microcontroller (M2) is used, JP2 can be opened to allow SW68 to be hardwired to any other switch in the keyboard matrix.

## 6.3 JP3 – Power LED

The microcontroller (M2 = Pro Micro) controls the power LED connected to J3 or J8.

If the Pro Micro is not installed and J3 or J8 is to be used for an “always-on” power LED, the corresponding jumper must be closed.

The advantage of this arrangement is that only the keyboard cable is required between the upper and lower halves of the case.

## 6.4 J4 – Short Board Jumper

See J4 – Short Board Jumper

# 7 Programming model

## 7.1 Pro Micro

Pro micro Pin | GPIO | Name | Direction | Description
1 | D0/TX | TX | Tbd | Reserved (J6 pin 3)
2 | D1/RX | RX | Tbd | Reserved (J6 pin 2)
5 | SDA/D2 | SDA | Bidir | I²C-Bus (M1 & J7 pin 2)
6 | SCL/D3 | SCL | Output | I²C-Bus (M1 & J7 pin 1)
7 | A6/D4 | /RESTORE | Input | RESTORE button (active low)
8 | D5 | SND_OUT | Output | Output for piezo buzzer
9 | A7/D6 | RGBOUT | Output | Output for RGB LED strip (J5 pin2)
10 | D7 | /INT6 | Input | Interrupt from PCF8575 GPIO Module
11 | A8/D8 | /C64RES | Bidir* | Signal for resetting the C64 and shift lock status, active low
12 | A9/D9 | PWRLED | Output | Output for power led (J3&8), active high
13 | D10/A10 | /EXROM | Bidir* | EXROM signal, active low
14 | D16 | KSW_A15 | Bidir* | Kernal address bit A15/ultimate freeze
15 | D14 | KSW_A14 | Bidir* | Kernal address bit A14/ultimate menu
16 | D15 | KSW_A13 | Bidir* | Kernal address bit A13/ultimate reset
17 | A0 | /SHORT_BRD | Input | J4 short board jumper, active low
18 | A1 | /P1 | Input | SW67/PREV switch, active low
19 | A2 | /P2 | Input | SW68/NEXT switch, active low
20 | A3 | A3 | tbd | Reserved (J6 pin 4)

Bidir*: A pin marked with an asterisk is designed to emulate an open-collector GPIO. When the signal is low, the GPIO pin actively drives the output low. When the signal is “high,” the GPIO pin is left floating (i.e. configured as an input). A pull-up resistor elsewhere in the circuit then pulls the signal to the required high level.

This is important when a digital signal can have multiple sources, such as /C64RES, which can originate from the C64 reset circuit, a reset button, or the Pro Micro.

It is particularly important for the Ultimate button signals, because the Ultimate 64/C64U uses 3.3 V logic levels, which are not necessarily 5 V tolerant.

Note: GPIO stands for General Purpose Input/Output. A GPIO pin does not have a fixed function; its operation is determined by the circuit to which it is connected.

## 7.2 Keyboard Matrix/PCF8575

The PCF8575 module (M1) is a 16-bit GPIO expander connected via the I²C bus.

Its primary purpose is to detect the keyboard matrix scan signals. If these signals are not detected, the Pro Micro uses the PCF8575 to actively scan the keyboard matrix at 125 times per second.

This provides the functionality required to use the keyboard as a USB keyboard with a keyboard layout suitable for VICE (C64 emulator).

M1 GPIO | Signal | Discription
P00 | ROW0 | Keyboard return signals: These signals are read to detect the switches of the keyboard matrix, that are pressed.
P01 | ROW1
P02 | ROW2
P03 | ROW3
P04 | ROW4
P05 | ROW5
P06 | ROW6
P07 | ROW7
P10 | COL0 | Keyboard scan signal: A bit pattern is written to the columns of the keyboard matrix.
P11 | COL1
P12 | COL2
P13 | COL3
P14 | COL4
P15 | COL5
P16 | COL6
P17 | COL7

The GPIO slave address is selected using the solder bridges on the bottom side of the module (see Figure 20). The correct address is 0x20.

# 8 Keycap Making

Options for obtaining or making the keycaps will be described or listed in the /Keycaps/pdf/ subfolder.

At the time of writing, some options are still being evaluated.

# 9 3D Printables

A mounting frame is required to install the keyboard inside a C64 or C64C. It can be found in the /3D printables/Mounting Frame/ subfolder.

An optional stiffener can be screwed to the solder side of the PCB. In my experience, it is not required, since the PCB already provides sufficient stability when screwed to the mounting frame.

A separate plate is not required. A plate is the level approximately 5 mm above the PCB, with cutouts for the keyboard switches. It is normally used to align 3-pin switches. Since 5-pin switches are recommended for this keyboard, a plate is not necessary.

There are, however, plates that serve as the top cover of the USB keyboard case. These can be found in the /3D printables/USB Keyboard Case/ subfolder.

There are two types of plate: regular and classic. The classic plate is only suitable if you want to use original Commodore keycaps from the 20th century. All other DIY and modern Commodore keycaps require the regular plate. The difference is the cutout and switch position for the 1.5U keycaps (Shift, Control, Restore, F-keys, etc.).

Both the mounting frame and the USB keyboard case are designed to fit on a 25 cm-wide 3D printer bed.


Figure 41: 3D printable mountinmg frame (top) and USB keyboard case (bottom)

# 10 Assembly
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

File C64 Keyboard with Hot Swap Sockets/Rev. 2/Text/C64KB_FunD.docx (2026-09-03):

C64 Mechanical Keyboard & Kernal Switcher

Hot Swap Socket Version Rev. 2

Functional Description

SW1 to SW66, with the exception of SW35, form the keyboard matrix of the C64 keyboard. It is identical to the original C64 keyboard matrix.

SW17A, SW18A, SW32A, SW33A, SW49A, SW51A, SW62A and SW65A are alternative positions for 1.5U keys, which nowadays typically have a central stem. They are wired in parallel with their corresponding classic-position switches (without the “A”).

SW32 is the RESTORE button. It is connected to the /RESTORE pin and GND, just like in the original keyboard. Unlike the original, it has a 10 kΩ pull-up resistor (R15), since the RESTORE signal is also required to have a defined state when the keyboard is not connected to a C64 mainboard.

SW35 is the SHIFT LOCK button. Unlike the original keyboard, where it is a latching switch and is electrically connected in parallel with the left SHIFT key, SW35 is connected to a dedicated Shift Lock circuit.

R3 is the pull-up resistor, and IC2A provides switch debouncing circuit.
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

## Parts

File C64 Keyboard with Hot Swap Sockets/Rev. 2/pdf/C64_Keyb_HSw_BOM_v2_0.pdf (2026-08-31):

Pos. | Qty Value | Footprint | Ref.-No. | Comment | Group
1 | 1 225-2-01-01 | 2 Layer | _PCB Rev. 1 | 2 layer, Cu 35µ, HASL, 385.6mm x
| | | | 96.4mm, 1.6mm FR4
2 | 4 100n | 0805 | C1, C2, C3, C4 | Capacitor SMD 0805, 25V, X7R,
| | | | ±10% or better | SL
3 | 1 1000u/10V | C30X16L | C4 | electrolytic capacitor, axial leads,
| | | | maximum length 30mm, maximum ∅ 16mm. E.g. Reichelt AX 105 1000/10 | RGB
4 | 1 100n | 0805 | C5 | Capacitor SMD 0805, 25V, X7R,
| | | | ±10% or better | SL
5 | 2 100n | 0805 | C6, C8 | Capacitor SMD 0805, 25V, X7R,
| | | | ±10% or better | POR
6 | 1 4u7 | | C7 | Capacitor SMD 0805, 25V, X7R,
| | | | ±10% or better | POR
7 | 1 LL4148 | SOD80C | D1 | Diode, SMD | SL
8 | 2 LL4148 | SOD80C | D2 | Diode, SMD | SPK
9 | 1 SN74HC74D | SO-14 | IC1 | SMD IC, e.G. TI | SL
10 | 1 74HC123D | SO-16 | IC2 | SMD IC, e.G. TI | SL
11 | 1 TL7705ACD | SO8 | IC3 | SMD IC, e.G. TI | POR
12 | 1 box pin header, 2x10, 90° 2X10WH | J1 | standard 2x10 pin box pin header,
| | | | e.g. Reichelt.de WSL 20W
13 | 1 pin header, 5p/90°,
| 2.54mm | 1X05/90 | J2 | standard 90° pin header, e.g. Reichelt
| | | | BKL 10120522 | KSW
14 | 1 pin header, 5p/90°,
| 2.54mm | 1X05/90 | J6 | DO NOT PLACE
15 | 2 KF2510 , 3p/90°, 2.54mm 1X03/90 | J3, J8 | KF2510 (AliExpress) or Molex KK 2.54
| | | | (3p, 90°)
16 | 1 pin header, 2p/90°,
| 2.54mm | 1X02/90 | J4 | standard 90° pin header, e.g. Reichelt
| | | | BKL 10120522 | KSW

## C64 Keyboard (Hot Swap) Rev. 2 Bill of Material Rev. 2.0

C64_Keyb_HSw_BOM_v2_0.xlsx
Drafted by Sven Petersen | Page 1 of 5

31.08.2026 20:33
Doc.No.: 225-5-01-02.0

Pos. | Qty Value | Footprint | Ref.-No. | Comment | Group

## C64 Keyboard (Hot Swap) Rev. 2 Bill of Material Rev. 2.0

17 | 1 Jumper, 2.54mm | | (J4) | standard 2.54mm jumper, only requird for short boards | KSW
18 | 1 pin header, 4p/90°, 2.54mm | 1X04/90 | J5 | standard 90° pin header, e.g. Reichelt W+P 946-144 | RGB
19 | 1 pin header, 4p/90°, 2.54mm | 1X04/90 | J7 | standard 90° pin header, e.g. Reichelt W+P 946-144 | I²C
20 | 1 PCF8575-MODULE | PCF8575MODU L | M1 | Ali Express PCF8575 module. Read module description. Configuration of solder bridges requires | USBKB
21 | 2 10 way socket for pin
header 2.54mm
(M1) | precision sockets, 2.54mm, 1x10,
straight. E.g. Reichelt MPE 115-1-010

USBKB

22 | 1 5 way socket for pin
header 2.54mm
(M1) | precision sockets, 2.54mm, 1x5,
straight. E.g. Reichelt MPE 115-1-005

USBKB

23 | 1 5 way pin header, 2.54mm | (M1) | straight, e.g. Reichelt BKL 10120503 | USBKB
24 | 1 PRO_MICRO | PRO_MICRO | M2 | Ali Express pro micro module. USB-C
connector prefered. Read module description

CTRL

25 | 2 12 way socket for pin
| header 2.54mm | | (M2) | precision sockets, 2.54mm, 1x12,
| | | | straight. E.g. Reichelt MPE 115-1-012 | CTRL
26 | 3 BC847B | SOT23 | Q1, Q3, Q5
27 | 1 100R* | 0805 | R1 | Resistor SMD 0805, 5% or better.
| | | | Read Module Description | SL
28 | 1 330R | 0805 | R11 | Resistor SMD 0805, 5% or better
29 | 1 470R | 0805 | R16 | Resistor SMD 0805, 5% or better | RGB
30 | 1 4k7 | 0805 | R18 | Resistor SMD 0805, 5% or better | SPK
31 | 1 33R | 0805 | R19 | Resistor SMD 0805, 5% or better | SPK
32 | 11 10k | 0805 | R2, R3, R5, R7 | Resistor SMD 0805, 5% or better | SL
33 | 11 10k | 0805 | R8, R9, R10, R12, R13, R14,
| | | R15 | Resistor SMD 0805, 5% or better

Pos. | Qty Value | Footprint | Ref.-No. | Comment | Group

## C64 Keyboard (Hot Swap) Rev. 2 Bill of Material Rev. 2.0

34 | 1 27k | 0805 | R20 | Resistor SMD 0805, 5% or better | SPK
35 | 1 27k | 0805 | R4 | Resistor SMD 0805, 5% or better | SL
36 | 1 dnp | 0805 | R6 | DO NOT PLACE
37 | 1 47k | RN-9 | RN1 | Resistor network, 8 resistors/9 pins. E.g-
| | | | Reichelt SIL 9-8 47K | USBKB
38 | 1 RMP-14P/HT | RMP-14P/HT | SPK1 | piezzo buzzer, ∅14mm, pin distance
| | | | 7.6mm, EKULIT (Reichelt SUMMER
| | | | EPM 121) | SPK
39 | 58 Cherry MX compatible
switch, 5 Pin

CHERRYMX SW1, SW2, SW3, SW4, SW5, SW6, SW7, SW8, SW9, SW10,
SW11, SW12, SW13, SW14,
SW15, SW16, SW19, SW20,
SW21, SW22, SW23, SW24,
SW25, SW26, SW27, SW28,
SW29, SW30, SW31, SW34,
SW35, SW36, SW37, SW38,
SW39, SW40, SW41, SW42,
SW43, SW44, SW45, SW46,
SW47, SW48, SW50, SW52,
SW53, SW54, SW55, SW56,
SW57, SW58, SW59, SW60,
SW61, SW63, SW64, SW66

Cherry MX compatible switches of your choice. Read the module description.

40 | 8 Cherry MX compatible
switch, 5 Pin

CHERRYMX SW17 or SW17A, SW18 or SW18A, SW32 or SW32A,
SW33 or SW33A, SW49 or
SW49A, SW51 or SW51A,
SW62 or SW62A, SW65 or
SW65A

SW** = for original keycaps, SW**A = for modern keycaps. Read module description

41 | 2 Cherry MX compatible
switch, 5 Pin
CHERRYMX | SW67, SW68 | KSW and RGB

Pos. | Qty Value | Footprint | Ref.-No. | Comment | Group

## C64 Keyboard (Hot Swap) Rev. 2 Bill of Material Rev. 2.0

42 | 76 SMD Hot Swap Sockets | | SW1-68, SW17A, SW18A,
| | | SW32A, SW33A, SW49A,
| | | SW51A, SW62A, SW65A | E.g. Kailh CPG151101S11-16
| | | | (AliExpress). Read module description
43 | 1 LED (high brightness) | LED 3mm | (SW35) | e.G. Kingbright L-7104SRC-J4
| | | | (Reichelt LED 3-4500 RT) | SL
44 | 1 Stabilizer, screw in type 7U | | (SW66) | (for 7U space bar or 9U spacebar of
| | | | C64U/Blingboard64 (CBMStuff.com).
| | | | Read module description)
45 | 1 Stabilizer, screw in type 2U | | (SW48) | for RETURN key
46 | 58 1U, blank keycaps | | | for MX compatibel switches, DSA
| | | | profile. Read module description
47 | 8 1.5U, blank keycaps | | | for MX compatibel switches, DSA
| | | | profile. Read module description
48 | 1 2U, blank keycap | | (SW48) | for MX compatibel switches, DSA
| | | | profile. Read module description
49 | 1 7U space bar | | (SW66) | for MX compatibel switches, DSA
| | | | profile. Read module description
50 | 25 C 2.2 x 6,5 H | | | screw, self tapping, DIN 7981
51 | 2 C 2.9 x 9,5 H | | | screw, self tapping, DIN 7981
52 | 2 3.2mm washer
53 | 1 3D printed keyboard frame | | | Rev. 1
54 | 1 ribbon cable + connector
| PCB | | | Project No. 224
55 | 1 kernal switcher cable | | | Drawing 223-3-001-00. Read module
| | | | description | KSW
56 | 1 optional WS2812B RGB
| LED strip | | | Read module description | RGB
57 | 1 optional OLED display | | | Read module description | I²C

Pos. | Qty Value | Footprint | Ref.-No. | Comment | Group

## C64 Keyboard (Hot Swap) Rev. 2 Bill of Material Rev. 2.0

Grp. SL | Shift Lock Circuit
POR | Power on reset
RGB | RGB LED strip
SPK | Piezo Buzzer
KSW | Kernal Switcher
USBKB USB Keyboard
I²C | I²C (OLED) Display
CTRL | Controller/pro micro

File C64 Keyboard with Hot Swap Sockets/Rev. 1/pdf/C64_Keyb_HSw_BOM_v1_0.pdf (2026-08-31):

Pos. | Qty Value | Footprint | Ref.-No. | Comment | Group
1 | 1 225-2-01-01 | 2 Layer | _PCB Rev. 1 | 2 layer, Cu 35µ, HASL, 385.6mm x
| | | | 96.4mm, 1.6mm FR4
2 | 3 100n | 0805 | C1, C2, C3 | Capacitor SMD 0805, 25V, X7R,
| | | | ±10% or better | SL
3 | 1 1000u/10V | C30X16L | C4 | electrolytic capacitor, axial leads,
| | | | maximum length 30mm, maximum ∅ 16mm. E.g. Reichelt AX 105 1000/10 | RGB
4 | 1 22n | 0805 | C5 | Capacitor SMD 0805, 25V, X7R,
| | | | ±10% or better | SL
5 | 3 100n | 0805 | C6, C7, C8 | Capacitor SMD 0805, 25V, X7R,
| | | | ±10% or better | POR
6 | 1 LL4148 | SOD80C | D1 | Diode, SMD | SL
7 | 2 LL4148 | SOD80C | D2 | Diode, SMD | SPK
8 | 1 SN74HC74D | SO-14 | IC1 | SMD IC, e.G. TI | SL
9 | 1 74HC123D | SO-16 | IC2 | SMD IC, e.G. TI | SL
10 | 1 TL7705ACD | SO8 | IC3 | SMD IC, e.G. TI | POR
11 | 1 box pin header, 2x10, 90° 2X10WH | J1 | standard 2x10 pin box pin header,
| | | | e.g. Reichelt.de WSL 20W
12 | 1 pin header, 5p/90°,
| 2.54mm | 1X05/90 | J2 | standard 90° pin header, e.g. Reichelt
| | | | BKL 10120522 | KSW
13 | 1 pin header, 5p/90°,
| 2.54mm | 1X05/90 | J6 | DO NOT PLACE
14 | 2 KF2510 , 3p/90°, 2.54mm 1X03/90 | J3, J8 | KF2510 (AliExpress) or Molex KK 2.54
| | | | (3p, 90°)
15 | 1 pin header, 2p/90°,
| 2.54mm | 1X02/90 | J4 | standard 90° pin header, e.g. Reichelt
| | | | BKL 10120522 | KSW
16 | 1 Jumper, 2.54mm | | (J4) | standard 2.54mm jumper, only requird
| | | | for short boards | KSW

## C64 Keyboard (Hot Swap) Rev. 1 Bill of Material Rev. 1.0

C64_Keyb_HSw_BOM_v1_0.xlsx
Drafted by Sven Petersen | Page 1 of 5

31.08.2026 20:32
Doc.No.: 225-5-01-01.0

Pos. | Qty Value | Footprint | Ref.-No. | Comment | Group

## C64 Keyboard (Hot Swap) Rev. 1 Bill of Material Rev. 1.0

17 | 1 pin header, 4p/90°, 2.54mm | 1X04/90 | J5 | standard 90° pin header, e.g. Reichelt W+P 946-144 | RGB
18 | 1 pin header, 4p/90°, 2.54mm | 1X04/90 | J7 | standard 90° pin header, e.g. Reichelt W+P 946-144 | I²C
19 | 1 PCF8575-MODULE | PCF8575MODU L | M1 | Ali Express PCF8575 module. Read module description. Configuration of solder bridges requires | USBKB
20 | 2 10 way socket for pin
header 2.54mm
(M1) | precision sockets, 2.54mm, 1x10,
straight. E.g. Reichelt MPE 115-1-010

USBKB

21 | 1 5 way socket for pin
header 2.54mm
(M1) | precision sockets, 2.54mm, 1x5,
straight. E.g. Reichelt MPE 115-1-005

USBKB

22 | 1 5 way pin header, 2.54mm | (M1) | straight, e.g. Reichelt BKL 10120503 | USBKB
23 | 1 PRO_MICRO | PRO_MICRO | M2 | Ali Express pro micro module. USB-C
connector prefered. Read module description

CTRL

24 | 2 12 way socket for pin
| header 2.54mm | | (M2) | precision sockets, 2.54mm, 1x12,
| | | | straight. E.g. Reichelt MPE 115-1-012 | CTRL
25 | 3 BC847B | SOT23 | Q1, Q3, Q5
26 | 1 100R* | 0805 | R1 | Resistor SMD 0805, 5% or better.
| | | | Read Module Description | SL
27 | 1 330R | 0805 | R11 | Resistor SMD 0805, 5% or better
28 | 1 470R | 0805 | R16 | Resistor SMD 0805, 5% or better | RGB
29 | 1 4k7 | 0805 | R18 | Resistor SMD 0805, 5% or better | SPK
30 | 1 33R | 0805 | R19 | Resistor SMD 0805, 5% or better | SPK
31 | 11 10k | 0805 | R2, R3, R5, R7 | Resistor SMD 0805, 5% or better | SL
32 | 11 10k | 0805 | R8, R9, R10, R12, R13, R14,
| | | R15 | Resistor SMD 0805, 5% or better
33 | 1 27k | 0805 | R20 | Resistor SMD 0805, 5% or better | SPK
34 | 1 27k | 0805 | R4 | Resistor SMD 0805, 5% or better | SL

Pos. | Qty Value | Footprint | Ref.-No. | Comment | Group

## C64 Keyboard (Hot Swap) Rev. 1 Bill of Material Rev. 1.0

35 | 1 dnp | 0805 | R6 | DO NOT PLACE
36 | 1 47k | RN-9 | RN1 | Resistor network, 8 resistors/9 pins. E.g-
| | | | Reichelt SIL 9-8 47K | USBKB
37 | 1 RMP-14P/HT | RMP-14P/HT | SPK1 | piezzo buzzer, ∅14mm, pin distance
| | | | 7.6mm, EKULIT (Reichelt SUMMER
| | | | EPM 121) | SPK
38 | 58 Cherry MX compatible
switch, 5 Pin

CHERRYMX SW1, SW2, SW3, SW4, SW5, SW6, SW7, SW8, SW9, SW10,
SW11, SW12, SW13, SW14,
SW15, SW16, SW19, SW20,
SW21, SW22, SW23, SW24,
SW25, SW26, SW27, SW28,
SW29, SW30, SW31, SW34,
SW35, SW36, SW37, SW38,
SW39, SW40, SW41, SW42,
SW43, SW44, SW45, SW46,
SW47, SW48, SW50, SW52,
SW53, SW54, SW55, SW56,
SW57, SW58, SW59, SW60,
SW61, SW63, SW64, SW66

Cherry MX compatible switches of your choice. Read the module description.

39 | 8 Cherry MX compatible
switch, 5 Pin

CHERRYMX SW17 or SW17A, SW18 or SW18A, SW32 or SW32A,
SW33 or SW33A, SW49 or
SW49A, SW51 or SW51A,
SW62 or SW62A, SW65 or
SW65A

SW** = for original keycaps, SW**A = for modern keycaps. Read module description

40 | 2 Cherry MX compatible
switch, 5 Pin
CHERRYMX | SW67, SW68 | KSW and RGB

Pos. | Qty Value | Footprint | Ref.-No. | Comment | Group

## C64 Keyboard (Hot Swap) Rev. 1 Bill of Material Rev. 1.0

41 | 76 SMD Hot Swap Sockets | | SW1-68, SW17A, SW18A,
| | | SW32A, SW33A, SW49A,
| | | SW51A, SW62A, SW65A | E.g. Kailh CPG151101S11-16
| | | | (AliExpress). Read module description
42 | 1 LED (high brightness) | LED 3mm | (SW35) | e.G. Kingbright L-7104SRC-J4
| | | | (Reichelt LED 3-4500 RT) | SL
43 | 1 Stabilizer, screw in type 7U | | (SW66) | (for 7U space bar or 9U spacebar of
| | | | C64U/Blingboard64 (CBMStuff.com).
| | | | Read module description)
44 | 1 Stabilizer, screw in type 2U | | (SW48) | for RETURN key
45 | 58 1U, blank keycaps | | | for MX compatibel switches, DSA
| | | | profile. Read module description
46 | 8 1.5U, blank keycaps | | | for MX compatibel switches, DSA
| | | | profile. Read module description
47 | 1 2U, blank keycap | | (SW48) | for MX compatibel switches, DSA
| | | | profile. Read module description
48 | 1 7U space bar | | (SW66) | for MX compatibel switches, DSA
| | | | profile. Read module description
49 | 25 C 2.2 x 6,5 H | | | screw, self tapping, DIN 7981
50 | 2 C 2.9 x 9,5 H | | | screw, self tapping, DIN 7981
51 | 2 3.2mm washer
52 | 1 3D printed keyboard frame | | | Rev. 1
53 | 1 ribbon cable + connector
| PCB | | | Project No. 224
54 | 1 kernal switcher cable | | | Drawing 223-3-001-00. Read module
| | | | description | KSW
55 | 1 optional WS2812B RGB
| LED strip | | | Read module description | RGB
56 | 1 optional OLED display | | | Read module description | I²C

Pos. | Qty Value | Footprint | Ref.-No. | Comment | Group

## C64 Keyboard (Hot Swap) Rev. 1 Bill of Material Rev. 1.0

Grp. SL | Shift Lock Circuit
POR | Power on reset
RGB | RGB LED strip
SPK | Piezo Buzzer
KSW | Kernal Switcher
USBKB USB Keyboard
I²C | I²C (OLED) Display
CTRL | Controller/pro micro

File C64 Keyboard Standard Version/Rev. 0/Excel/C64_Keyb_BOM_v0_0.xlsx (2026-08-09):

C64 Keyboard Rev. 0
Bill of Material Rev. 0.0
Pos. | Qty | Value | Footprint | Ref.-No. | Comment | Group
1 | 1 | 223-2-01-00 | 2 Layer | PCB Rev. 0 | 2 layer, Cu 35µ, HASL, 385.6mm x 96.4mm, 1.6mm FR4
2 | 1 | pin header, 2p/90°, 2.54mm | 1X02/90 | J4 | standard 90° pin header, e.g. Reichelt W+P 946-132 | KSW
3 | 1 | Jumper, 2.54mm |  | (J4) | standard 2.54mm jumper, only requird for short boards | KSW
4 | 2 | KF2510 , 3p/90°, 2.54mm | 1X03/90 | J3, J8 | KF2510 (AliExpress) or Molex KK 2.54 (3p, 90°) | Power LED
5 | 1 | pin header, 4p/90°, 2.54mm | 1X04/90 | J5 | standard 90° pin header, e.g. Reichelt W+P 946-144 | RGB
6 |  | pin header, 4p/90°, 2.54mm | 1X04/90 | J7 | standard 90° pin header, e.g. Reichelt W+P 946-144 | I²C
7 | 1 | pin header, 5p/90°, 2.54mm | 1X05/90 | J2 | standard 90° pin header, e.g. Reichelt BKL 10120522 | KSW
8 | 1 | pin header, 5p/90°, 2.54mm | 1X05/90 | J6 | DO NOT Populate
9 | 1 | box pin header, 2x10, 90° | 2X10WH | J1 | standard 2x10 pin box pin header, e.g. Reichelt.de WSL 20W
10 | 1 | 1000u/10V | C30X16L | C4 | electrolytic capacitor, axial leads, maximum length 30mm, maximum Æ 16mm. E.g. Reichelt AX 105 1000/10 | RGB
11 | 2 | 100n | 0805 | C2, C3 | Capacitor SMD 0805, 25V, X7R, ±10% or better | SL
12 | 5 | 10k | 0805 | R2, R4, R5, R6, R7, | Resistor SMD 0805, 5% | SL
13 | 7 | 10k | 0805 | R8, R9, R10, R12, R13, R14, R15 | Resistor SMD 0805, 5% | CTRL
14 | 1 | 15k | 0805 | R3 | Resistor SMD 0805, 5% | SL
15 | 1 | 27k | 0805 | R20 | Resistor SMD 0805, 5% | SPK
16 | 1 | 100R | 0805 | R1 | Resistor SMD 0805, 5% | SL
17 | 1 | 330R | 0805 | R11 | Resistor SMD 0805, 5% | Power LED
18 | 1 | 33R | 0805 | R19 | Resistor SMD 0805, 5% | SPK
19 | 1 | 33n | 0805 | C1 | Capacitor SMD 0805, 25V, X7R, ±10% or better | SL
20 | 1 | 470R | 0805 | R16 | Resistor SMD 0805, 5% | RGB
21 | 1 | 47k | RN-9 | RN1 | Resistor network, 8 resistors/9 pins. E.g- Reichelt SIL 9-8 47K | USBKB
22 | 1 | 4k7 | 0805 | R18 | Resistor SMD 0805, 5% | SPK
23 | 3 | BC847B | SOT23 | Q1, Q2, Q3 | Transistor, SMD (NPN universal) | SL
24 | 1 | BC847B | SOT23 | Q5 | Transistor, SMD (NPN universal) | SPK
25 | 1 | LL4148 | SOD80C | D1 | Diode, SMD | SL
26 | 1 | LL4148 | SOD80C | D2 | Diode, SMD | SPK
26 | 68 | Cherry MX, 5 Pin | CHERRYMX | SW1 - SW68 | For new 1.5U keycaps, populate the SW**A position. Read module description
27 | 1 | LED (high brightness) | LED 3mm | (SW35) | e.G. Kingbright L-7104SRC-J4 (Reichelt LED 3-4500 RT) | SL
28 | 1 | PCF8575-MODULE | PCF8575MODUL | M1 | Ali Express PCF8575 module. Read module description. Configuration of solder bridges requires | USBKB
29 | 2 | 10 way socket for pin header 2.54mm |  | (M1) | precision sockets, 2.54mm, 1x10, straight. E.g. Reichelt MPE 115-1-010 | USBKB
30 | 1 | 5 way socket for pin header 2.54mm |  | (M1) | precision sockets, 2.54mm, 1x5, straight. E.g. Reichelt MPE 115-1-005 | USBKB
31 | 1 | 5 way pin header, 2.54mm |  | (M1) | straight, e.g. Reichelt BKL 10120503 | USBKB
32 | 1 | PRO_MICRO | PRO_MICRO | M2 | Ali Express pro micro module. Read module description | CTRL
33 | 2 | 12 way socket for pin header 2.54mm |  | (M2) | precision sockets, 2.54mm, 1x12, straight. E.g. Reichelt MPE 115-1-012 | CTRL
34 | 1 | RMP-14P/HT | RMP-14P/HT | SPK1 | piezzo buzzer, Æ14mm, pin distance 7.6mm, EKULIT (Reichelt SUMMER EPM 121) | SPK
35 | 1 | SN74HC74D | SO-14 | IC1 | SMD IC, e.G. TI | SL
36 | 1 | Stabilizer, screw in type 7U |  | (SW66) | (for 7U space bar or 9U spacebar of C64U/Blingboard64 (CBMStuff.com). Read module description)
37 | 1 | Stabilizer, screw in type 2U |  | (SW48) | for RETURN key
38 | 58 | 1U, blank keycaps |  |  | for MX compatgibel switches, DSA profile. Read module description
39 | 8 | 1.5U, blank keycaps |  |  | for MX compatgibel switches, DSA profile. Read module description
40 | 1 | 2U, blank keycap |  | (SW48) | for MX compatgibel switches, DSA profile. Read module description
41 | 1 | 7U space bar |  | (SW66) | for MX compatgibel switches, DSA profile. Read module description
42 | 25 | C 2.2 x 6,5 H |  |  | screw, self tapping, DIN 7981
43 | 2 | C 2.9 x 9,5 H |  |  | screw, self tapping, DIN 7981
44 | 2 | 3.2mm washer
45 | 1 | 3D printed keyboard frame |  |  | Rev. 0
46 | 1 | ribbon cable + connector PCB |  |  | Project No. 224
47 | 1 | kernal switcher cable |  |  | Drawing 223-3-001-00. Read module description
48 | 1 | optional WS2812B RGB LED strip |  |  | Read module description | RGB
49 | 1 | optional OLED display |  |  | Read module description | I²C
Grp. | SL | Shift Lock Circuit
 | RGB | RGB LED strip
 | SPK | Piezo Buzzer
 | KSW | Kernal Switcher
 | USBKB | USB Keyboard
 | I²C | I²C (OLED) Display
 | CTRL | Controller/pro micro

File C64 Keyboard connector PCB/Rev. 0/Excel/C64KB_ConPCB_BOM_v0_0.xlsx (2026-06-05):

C64 Keyboard Connector PCB Rev. 0
Bill of Material Rev. 0.0
Pos. | Qty | Value | Footprint | Ref.-No. | Comment
1 | 1 | 224-2-01-00 | 2 Layer | PCB Rev. 0 | 2 layer, Cu 35µ, HASL, 53.0mm x 15.0mm, 1.6mm FR4
 | 1 | LED, green, 3mm | 3MM | LD1 | Standard LED, 3mm, green
 | 1 | 330R | R-10 | R1 | Metal film resistor, 1/4W & 10% or better
 | 1 | BL1-85AXX-20U | BL1-85AXX-20U | J1 | 1x20 pin socket connector, 90°, e.g. MPE Garry, Reichelt BL 1x20W8 2,54
 | 1 | 369-1-020 or 2-215079-0 | MICMA20B | J2 | 20 pin MicroMatch, femal, PCB-mount, e.g. MPE Garry, Reichelt MPE 369-1-020 or TE Connectivity 2-215079-0
 | 1 | 45cm ribbon cable |  | cable | 20 way, AWG28, 1.27mm
 | 1 | IDC header Micro Match, 20-pin |  | cable | Reichelt MPE 369-1-020 or TE Connectivity 9-215083-0
 | 1 | 20-pin IDC socket with strain relief, 2.54mm |  | cable | e.g. Reichelt PFL 20

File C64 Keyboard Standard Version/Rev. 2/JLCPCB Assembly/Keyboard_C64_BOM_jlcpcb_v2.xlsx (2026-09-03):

Comment | Designator | Footprint | JLCPCB Part #
100R | R1 | 805 | C17408
100n | C1, C2, C3, C5, C6, C8, C9 | 805 | C49678
10k | R2, R3, R5, R7, R8, R9, R10, R12, R13, R14, R15 | 805 | C17414
27k | R4, R20 | 805 | C17593
330R | R11 | 805 | C17630
33R | R19 | 805 | C17634
470R | R16 | 805 | C17710
4k7 | R18 | 805 | C17673
4u7 | C7 | 805 | C1779
74HC123D | IC2 | SO-16 | C5597
BC847B | Q1, Q3, Q5 | SOT23 | C20069135
LL4148 | D1, D2 | SOD80C | C181117
SN74HC74D | IC1 | SO-14 | C6762
TL7705ACD | IC3 | SO8 | C350569

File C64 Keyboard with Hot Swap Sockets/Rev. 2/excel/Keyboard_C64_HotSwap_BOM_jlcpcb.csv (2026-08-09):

Comment | Designator | Footprint | JLCPCB Part # | KEY
 | JP1, JP2 | CP_CL
 | JP3 | CP_OP
 | J4 | 1X02/90
 | J3, J8 | 1X03/90
 | J5, J7 | 1X04/90
 | J2, J6 | 1X05/90
 | J1 | 2X10WH
1000u/16V | C4 | C30X16L
100R | R1 | 0805
100n | C1, C2, C3, C5 | 0805
100n | C6, C8, C9 | 0805
10k | R2, R3, R5, R7, R8, R9, R10, R12, R13, R14, R15 | 0805
27k | R4, R20 | 0805
330R | R11 | 0805
33R | R19 | 0805
470R | R16 | 0805
47k | RN1 | RN-9
4k7 | R18 | 0805
4u7 | C7 | 0805
74HC123D | IC2 | SO-16
BC847B | Q1, Q3, Q5 | SOT23
LL4148 | D1, D2 | SOD80C
MX+LEDHSWP | SW35 | CHERRYMX_HSWP_LD |  | SH.LOCK
MXHOTSWAP | SW30 | CHERRYMX_HOTSWAP |  | *
MXHOTSWAP | SW12 | CHERRYMX_HOTSWAP |  | +
MXHOTSWAP | SW13 | CHERRYMX_HOTSWAP |  | -
MXHOTSWAP | SW61 | CHERRYMX_HOTSWAP |  | /
MXHOTSWAP | SW11 | CHERRYMX_HOTSWAP |  | 0
MXHOTSWAP | SW2 | CHERRYMX_HOTSWAP |  | 1
MXHOTSWAP | SW3 | CHERRYMX_HOTSWAP |  | 2
MXHOTSWAP | SW4 | CHERRYMX_HOTSWAP |  | 3
MXHOTSWAP | SW5 | CHERRYMX_HOTSWAP |  | 4
MXHOTSWAP | SW6 | CHERRYMX_HOTSWAP |  | 5
MXHOTSWAP | SW7 | CHERRYMX_HOTSWAP |  | 6
MXHOTSWAP | SW8 | CHERRYMX_HOTSWAP |  | 7
MXHOTSWAP | SW9 | CHERRYMX_HOTSWAP |  | 8
MXHOTSWAP | SW10 | CHERRYMX_HOTSWAP |  | 9
MXHOTSWAP | SW47 | CHERRYMX_HOTSWAP |  | =
MXHOTSWAP | SW29 | CHERRYMX_HOTSWAP |  | @
MXHOTSWAP | SW36 | CHERRYMX_HOTSWAP |  | A
MXHOTSWAP | SW56 | CHERRYMX_HOTSWAP |  | B
MXHOTSWAP | SW54 | CHERRYMX_HOTSWAP |  | C
MXHOTSWAP | SW50 | CHERRYMX_HOTSWAP |  | C=
MXHOTSWAP | SW64 | CHERRYMX_HOTSWAP |  | CRSR.lr
MXHOTSWAP | SW63 | CHERRYMX_HOTSWAP |  | CRSR.ud
MXHOTSWAP | SW18, SW18A | CHERRYMX_HOTSWAP |  | CTRL
MXHOTSWAP | SW38 | CHERRYMX_HOTSWAP |  | D
MXHOTSWAP | SW16 | CHERRYMX_HOTSWAP |  | DEL
MXHOTSWAP | SW21 | CHERRYMX_HOTSWAP |  | E
MXHOTSWAP | SW39 | CHERRYMX_HOTSWAP |  | F
MXHOTSWAP | SW17, SW17A | CHERRYMX_HOTSWAP |  | F1
MXHOTSWAP | SW33, SW33A | CHERRYMX_HOTSWAP |  | F3
MXHOTSWAP | SW49, SW49A | CHERRYMX_HOTSWAP |  | F5
MXHOTSWAP | SW65, SW65A | CHERRYMX_HOTSWAP |  | F7
MXHOTSWAP | SW40 | CHERRYMX_HOTSWAP |  | G
MXHOTSWAP | SW41 | CHERRYMX_HOTSWAP |  | H
MXHOTSWAP | SW15 | CHERRYMX_HOTSWAP |  | HOME
MXHOTSWAP | SW26 | CHERRYMX_HOTSWAP |  | I
MXHOTSWAP | SW42 | CHERRYMX_HOTSWAP |  | J
MXHOTSWAP | SW43 | CHERRYMX_HOTSWAP |  | K
MXHOTSWAP | SW44 | CHERRYMX_HOTSWAP |  | L
MXHOTSWAP | SW1 | CHERRYMX_HOTSWAP |  | LEFT ARR
MXHOTSWAP | SW58 | CHERRYMX_HOTSWAP |  | M
MXHOTSWAP | SW57 | CHERRYMX_HOTSWAP |  | N
MXHOTSWAP | SW68 | CHERRYMX_HOTSWAP |  | Next
MXHOTSWAP | SW27 | CHERRYMX_HOTSWAP |  | O
MXHOTSWAP | SW28 | CHERRYMX_HOTSWAP |  | P
MXHOTSWAP | SW67 | CHERRYMX_HOTSWAP |  | Prev
MXHOTSWAP | SW19 | CHERRYMX_HOTSWAP |  | Q
MXHOTSWAP | SW22 | CHERRYMX_HOTSWAP |  | R
MXHOTSWAP | SW32, SW32A | CHERRYMX_HOTSWAP |  | RESTORE
MXHOTSWAP | SW48 | CHERRYMX_HOTSWAP |  | RETURN
MXHOTSWAP | SW34 | CHERRYMX_HOTSWAP |  | RUN
MXHOTSWAP | SW37 | CHERRYMX_HOTSWAP |  | S
MXHOTSWAP | SW51, SW51A | CHERRYMX_HOTSWAP |  | SH.LEFT
MXHOTSWAP | SW62, SW62A | CHERRYMX_HOTSWAP |  | SH.RIGHT
MXHOTSWAP | SW66 | CHERRYMX_HOTSWAP |  | SPACE
MXHOTSWAP | SW23 | CHERRYMX_HOTSWAP |  | T
MXHOTSWAP | SW25 | CHERRYMX_HOTSWAP |  | U
MXHOTSWAP | SW31 | CHERRYMX_HOTSWAP |  | UP ARR
MXHOTSWAP | SW55 | CHERRYMX_HOTSWAP |  | V
MXHOTSWAP | SW20 | CHERRYMX_HOTSWAP |  | W
MXHOTSWAP | SW53 | CHERRYMX_HOTSWAP |  | X
MXHOTSWAP | SW24 | CHERRYMX_HOTSWAP |  | Y
MXHOTSWAP | SW52 | CHERRYMX_HOTSWAP |  | Z
MXHOTSWAP | SW45 | CHERRYMX_HOTSWAP |  | [
MXHOTSWAP | SW46 | CHERRYMX_HOTSWAP |  | ]
MXHOTSWAP | SW59 | CHERRYMX_HOTSWAP |  | comma
MXHOTSWAP | SW60 | CHERRYMX_HOTSWAP |  | period
MXHOTSWAP | SW14 | CHERRYMX_HOTSWAP |  | £
OPEN_SOURCE_HW | U$90 | OPENHW
PCF8575-MODULE | M1 | PCF8575MODUL
PRO_MICRO | M2 | PRO_MICRO
RMP-14P/HT | SPK1 | RMP-14P/HT
SN74HC74D | IC1 | SO-14
TL7705ACD | IC3 | SO8

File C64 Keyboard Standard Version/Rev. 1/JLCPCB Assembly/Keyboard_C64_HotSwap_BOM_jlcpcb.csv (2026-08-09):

Comment | Designator | Footprint | JLCPCB Part #
 | JP1, JP2 | CP_CL
 | JP3 | CP_OP
 | J4 | 1X02/90
 | J3, J8 | 1X03/90
 | J5, J7 | 1X04/90
 | J2, J6 | 1X05/90
 | J1 | 2X10WH
1000u/16V | C4 | C30X16L
100R | R1 | 0805
100k | R4 | 0805
100n | C1, C2, C3 | 0805
100n | C6, C7, C8 | 0805
10k | R2, R3, R5, R7, R8, R9, R10, R12, R13, R14, R15 | 0805
22n | C5 | 0805
27k | R20 | 0805
330R | R11 | 0805
33R | R19 | 0805
470R | R16 | 0805
47k | RN1 | RN-9
4k7 | R18 | 0805
74HC123D | IC2 | SO-16
BC847B | Q1, Q3, Q5 | SOT23
LL4148 | D1, D2 | SOD80C
MX+LEDHSWP | SW35 | CHERRYMX_HSWP_LD
MXHOTSWAP | SW1, SW2, SW3, SW4, SW5, SW6, SW7, SW8, SW9, SW10, SW11, SW12, SW13, SW14, SW15, SW16, SW17, SW17A, SW18, SW18A, SW19, SW20, SW21, SW22, SW23, SW24, SW25, SW26, SW27, SW28, SW29, SW30, SW31, SW32, SW32A, SW33, SW33A, SW34, SW36, SW37, SW38, SW39, SW40, SW41, SW42, SW43, SW44, SW45, SW46, SW47, SW48, SW49, SW49A, SW50, SW51, SW51A, SW52, SW53, SW54, SW55, SW56, SW57, SW58, SW59, SW60, SW61, SW62, SW62A, SW63, SW64, SW65, SW65A, SW66, SW67, SW68 | CHERRYMX_HOTSWAP
OPEN_SOURCE_HW | U$90 | OPENHW
PCF8575-MODULE | M1 | PCF8575MODUL
PRO_MICRO | M2 | PRO_MICRO
RMP-14P/HT | SPK1 | RMP-14P/HT
SN74HC74D | IC1 | SO-14
TL7705ACD | IC3 | SO8
dnp | R6 | 0805

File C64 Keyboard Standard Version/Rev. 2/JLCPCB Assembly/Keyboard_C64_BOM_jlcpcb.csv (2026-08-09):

Comment | Designator | Footprint | JLCPCB Part # | KEY
 | JP1, JP2 | CP_CL
 | JP3 | CP_OP
 | J4 | 1X02/90
 | J3, J8 | 1X03/90
 | J5, J7 | 1X04/90
 | J2, J6 | 1X05/90
 | J1 | 2X10WH
1000u/16V | C4 | C30X16L
100R | R1 | 0805
100n | C1, C2, C3, C5 | 0805
100n | C6, C8, C9 | 0805
10k | R2, R3, R5, R7, R8, R9, R10, R12, R13, R14, R15 | 0805
27k | R4, R20 | 0805
330R | R11 | 0805
33R | R19 | 0805
470R | R16 | 0805
47k | RN1 | RN-9
4k7 | R18 | 0805
4u7 | C7 | 0805
74HC123D | IC2 | SO-16
BC847B | Q1, Q3, Q5 | SOT23
LL4148 | D1, D2 | SOD80C
MX | SW30 | CHERRYMX |  | *
MX | SW12 | CHERRYMX |  | +
MX | SW13 | CHERRYMX |  | -
MX | SW61 | CHERRYMX |  | /
MX | SW11 | CHERRYMX |  | 0
MX | SW2 | CHERRYMX |  | 1
MX | SW3 | CHERRYMX |  | 2
MX | SW4 | CHERRYMX |  | 3
MX | SW5 | CHERRYMX |  | 4
MX | SW6 | CHERRYMX |  | 5
MX | SW7 | CHERRYMX |  | 6
MX | SW8 | CHERRYMX |  | 7
MX | SW9 | CHERRYMX |  | 8
MX | SW10 | CHERRYMX |  | 9
MX | SW47 | CHERRYMX |  | =
MX | SW29 | CHERRYMX |  | @
MX | SW36 | CHERRYMX |  | A
MX | SW56 | CHERRYMX |  | B
MX | SW54 | CHERRYMX |  | C
MX | SW50 | CHERRYMX |  | C=
MX | SW64 | CHERRYMX |  | CRSR.lr
MX | SW63 | CHERRYMX |  | CRSR.ud
MX | SW18, SW18A | CHERRYMX |  | CTRL
MX | SW38 | CHERRYMX |  | D
MX | SW16 | CHERRYMX |  | DEL
MX | SW21 | CHERRYMX |  | E
MX | SW39 | CHERRYMX |  | F
MX | SW17, SW17A | CHERRYMX |  | F1
MX | SW33, SW33A | CHERRYMX |  | F3
MX | SW49, SW49A | CHERRYMX |  | F5
MX | SW65, SW65A | CHERRYMX |  | F7
MX | SW40 | CHERRYMX |  | G
MX | SW41 | CHERRYMX |  | H
MX | SW15 | CHERRYMX |  | HOME
MX | SW26 | CHERRYMX |  | I
MX | SW42 | CHERRYMX |  | J
MX | SW43 | CHERRYMX |  | K
MX | SW44 | CHERRYMX |  | L
MX | SW1 | CHERRYMX |  | LEFT ARR
MX | SW58 | CHERRYMX |  | M
MX | SW57 | CHERRYMX |  | N
MX | SW68 | CHERRYMX |  | Next
MX | SW27 | CHERRYMX |  | O
MX | SW28 | CHERRYMX |  | P
MX | SW67 | CHERRYMX |  | Prev
MX | SW19 | CHERRYMX |  | Q
MX | SW22 | CHERRYMX |  | R
MX | SW32, SW32A | CHERRYMX |  | RESTORE
MX | SW48 | CHERRYMX |  | RETURN
MX | SW34 | CHERRYMX |  | RUN
MX | SW37 | CHERRYMX |  | S
MX | SW51, SW51A | CHERRYMX |  | SH.LEFT
MX | SW62, SW62A | CHERRYMX |  | SH.RIGHT
MX | SW66 | CHERRYMX |  | SPACE
MX | SW23 | CHERRYMX |  | T
MX | SW25 | CHERRYMX |  | U
MX | SW31 | CHERRYMX |  | UP ARR
MX | SW55 | CHERRYMX |  | V
MX | SW20 | CHERRYMX |  | W
MX | SW53 | CHERRYMX |  | X
MX | SW24 | CHERRYMX |  | Y
MX | SW52 | CHERRYMX |  | Z
MX | SW45 | CHERRYMX |  | [
MX | SW46 | CHERRYMX |  | ]
MX | SW59 | CHERRYMX |  | comma
MX | SW60 | CHERRYMX |  | period
MX | SW14 | CHERRYMX |  | £
MX+LED | SW35 | CHERRYMXLD |  | SH.LOCK
OPEN_SOURCE_HW | U$90 | OPENHW
PCF8575-MODULE | M1 | PCF8575MODUL
PRO_MICRO | M2 | PRO_MICRO
RMP-14P/HT | SPK1 | RMP-14P/HT
SN74HC74D | IC1 | SO-14
TL7705ACD | IC3 | SO8

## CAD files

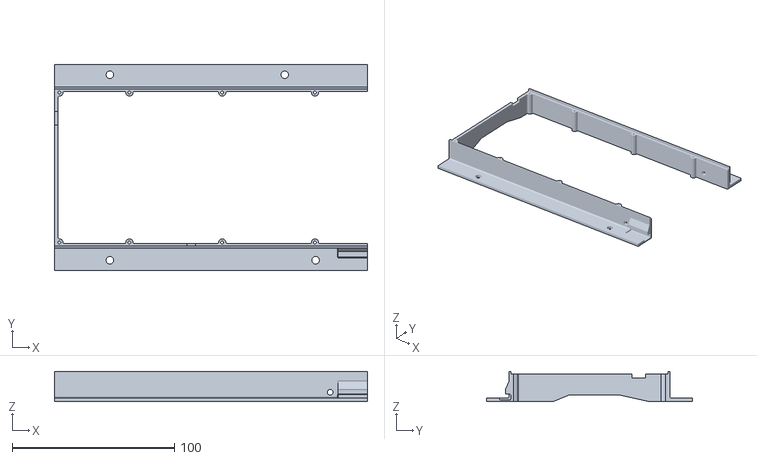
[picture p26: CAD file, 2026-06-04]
3D printables/Mounting Frame/Rev. 0/stl/bracket_left.stl
192.8 x 126.7 x 18.5

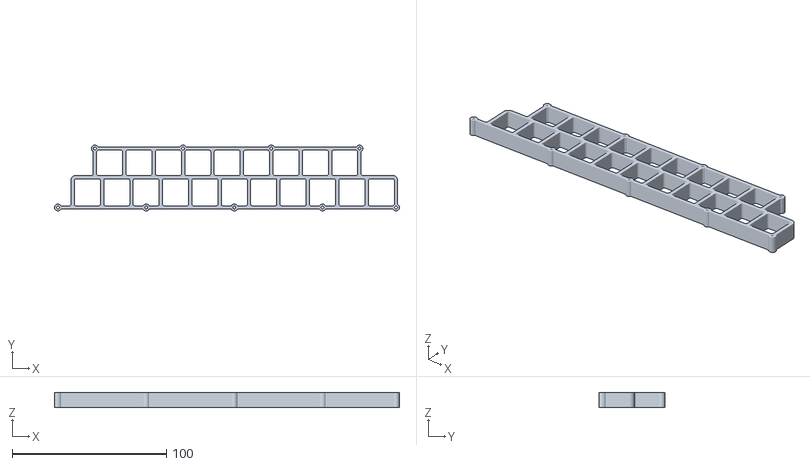
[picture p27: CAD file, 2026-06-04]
3D printables/Mounting Frame/Rev. 1/stl/C64KB_Stiffener.stl
223.4 x 42.7 x 10.0

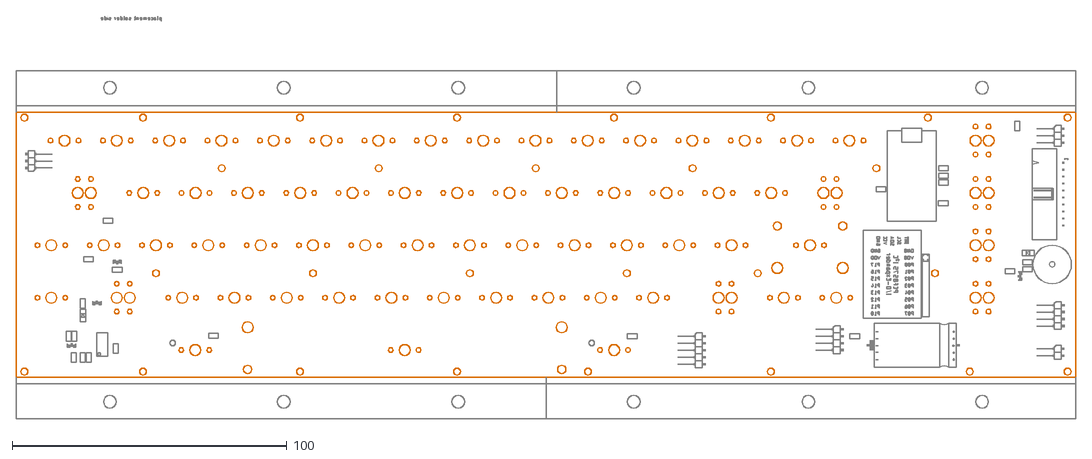
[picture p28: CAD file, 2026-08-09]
C64 Keyboard Standard Version/Rev. 0/dxf/Keyboard_C64.dxf
385.6 x 146.4

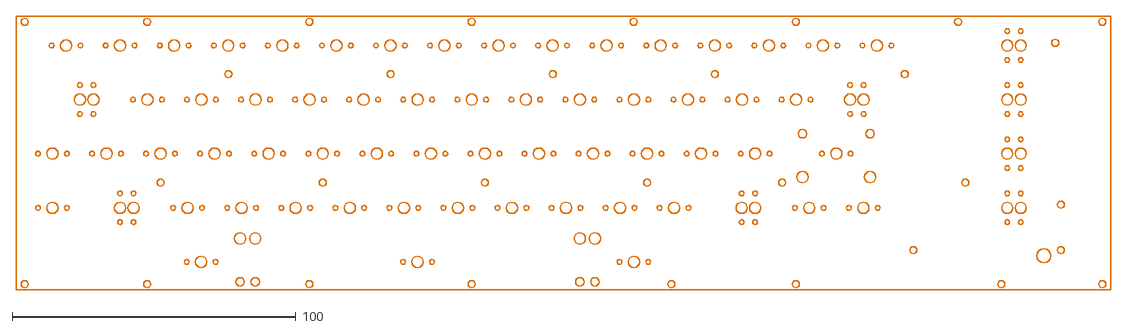
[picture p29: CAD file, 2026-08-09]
C64 Keyboard Standard Version/Rev. 2/dxf/Keyboard_C64_PCB_outline.dxf
385.6 x 96.4

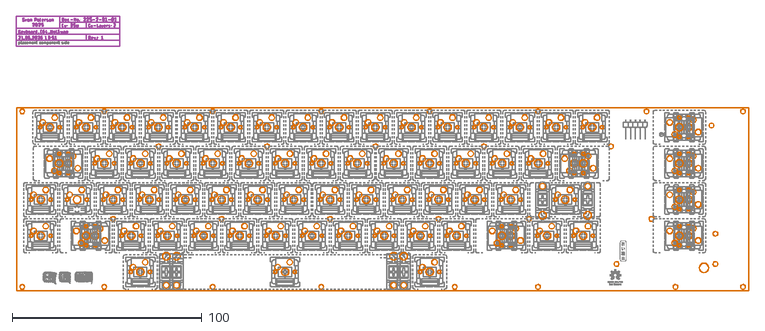
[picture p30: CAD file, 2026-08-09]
C64 Keyboard with Hot Swap Sockets/Rev. 2/dxf/Keyboard_C64_HotSwap.dxf
385.8 x 144.5

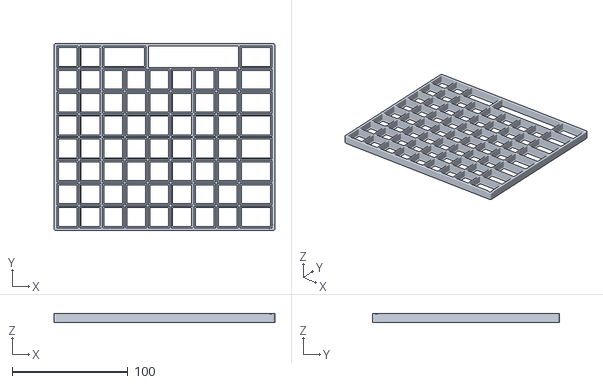
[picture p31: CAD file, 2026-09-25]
Keycaps/print_trays/stl/c64_kb_keycap_tray_all.stl
191.3 x 162.2 x 8.10

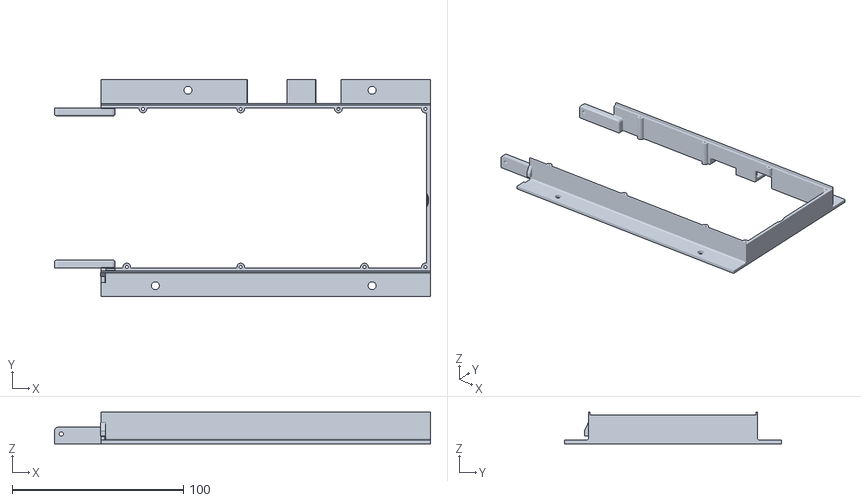
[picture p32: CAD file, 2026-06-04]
3D printables/Mounting Frame/Rev. 0/stl/bracket_right.stl
219.8 x 126.7 x 18.5

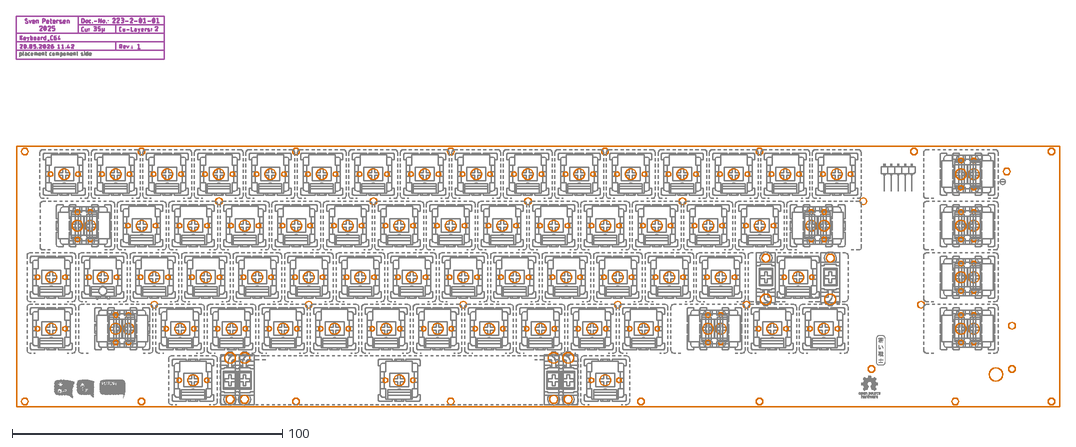
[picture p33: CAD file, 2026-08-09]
C64 Keyboard Standard Version/Rev. 2/dxf/Keyboard_C64.dxf
385.8 x 144.5

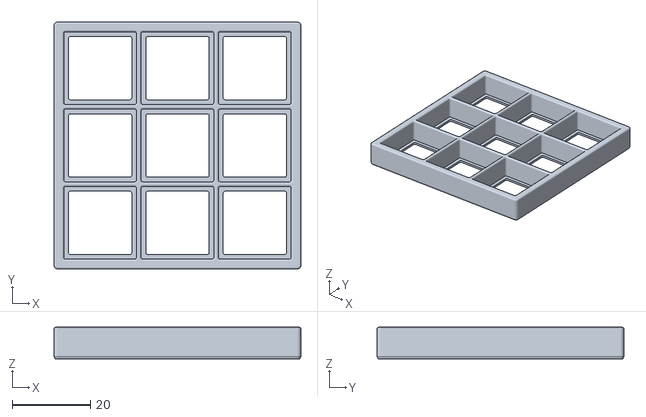
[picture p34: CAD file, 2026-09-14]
Keycaps/print_trays/stl/c64_kb_1U_tray_9x.stl
63.2 x 63.2 x 8.10

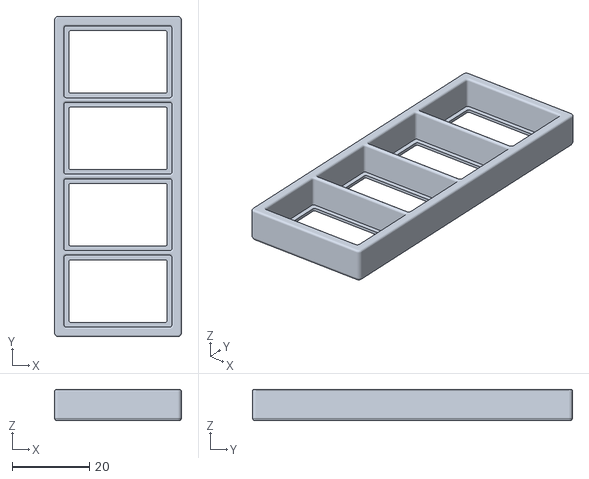
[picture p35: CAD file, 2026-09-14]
Keycaps/print_trays/stl/c64_kb_1_5U_tray_4x.stl
32.9 x 83.0 x 8.10

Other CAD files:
9U_stabilizer/Autosketch/9U_StabBar.DWG
Cables/Autosketch/KB_Cab.DWG
3D printables/Mounting Frame/Rev. 1/stl/C64KB_bracket_left.stl
Cables/Autosketch/Ulti_Cab.DWG
3D printables/Mounting Frame/Rev. 0/stl/Stiffener.stl
3D printables/Mounting Frame/Rev. 1/stl/C64KB_bracket_right.stl
Cables/Autosketch/KSw_Cab.DWG
3D printables/Mounting Frame/Rev. 0/fusion 360/C64 Keyboard Frame v0.f3d
3D printables/Mounting Frame/Rev. 1/fusion 360/C64 Keyboard Frame v1.f3d
3D printables/USB Keyboard Case/Rev. 1/fusion 360/C64 Keyboard Case Classic v1.f3d
3D printables/USB Keyboard Case/Rev. 1/fusion 360/C64 Keyboard Case v1.f3d
Keycaps/print_trays/fusion360/c64_kb_1U_tray_9x.f3d
Keycaps/print_trays/fusion360/c64_kb_1_5U_tray_4x.f3d
Keycaps/print_trays/fusion360/c64_kb_keycap_tray_all.f3d

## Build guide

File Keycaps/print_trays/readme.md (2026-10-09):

The print trays have a grid distance of 19.8mm. They are for printing or laser etching the key caps multiple at once, while fabrication. 

The size of the print trays is about the maximum, that my fiber laser (LaserPecker LP3) can do.

There is a further print tray for UV printing all keys at once.

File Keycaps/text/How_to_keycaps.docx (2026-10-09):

How to: Keycaps

# 1. Introduction

For every retro-computer mechanical keyboard project, keycaps have been a significant challenge. There are, however, several methods for making decent-looking keycaps. Making keycaps is also the subject of many YouTube videos. I have tried some of these methods with varying degrees of success.

Before making any C64 keycaps, there was a major task to complete: creating the legends with Inkscape (http://www.inkscape.org). Inkscape is free and open-source vector graphics software, which I use for almost every project to create case labels, logos and block diagrams.

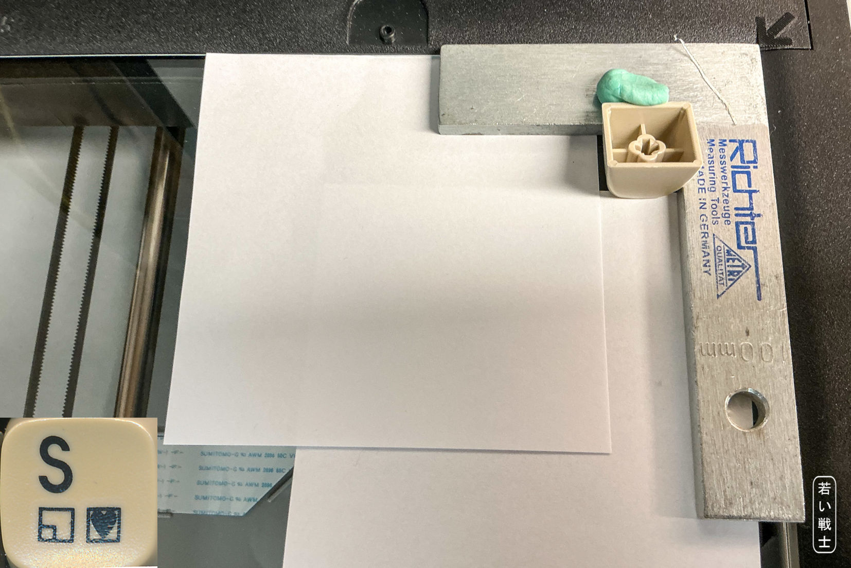
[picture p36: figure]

Figure 1: Scanning a single keycap

The legend drawings are based on scans of the top of every individual keycap of a C64C keyboard. These keycaps have top-printed legends only. A great help was discovering that the font used for the letters is ITC Avangarde Gothic LT Medium (https://github.com/bbh-labs/anti-social/tree/master/www/font/ITC%20Avant%20Garde%20Gothic), which is also freely available on GitHub. To use the *.svg (Inkscape) files provided in this repository, you need to install this font first. It needs to be installed for all users so that it is available to Inkscape.

The Inkscape keycap legends are exported as pixel-based *.png images at a resolution of 600 dpi. These are the files I used for laser-engraving several sets of keycaps.

Of course, you can also use C64 Ultimate or original C64 keycaps with this C64 keyboard project.

# 2. Blank Keycaps

The basis for all DIY keycaps is blank keycaps, which are available from various sources. I have only tried purchasing them from AliExpress, so all of my market research is based on this source.

Figure 2: Some keycap profiles

Several keycap profiles are available (Figure 2). The problem is that we do not just need 1U keycaps, but also 1.5U keycaps for SHIFT, CONTROL, RESTORE and the function keys, a 2U keycap for RETURN, and a 7U space bar—all in the same profile. So far, I have only found a complete set of the required sizes in the DSA profile.

Obviously, some keycap profiles have a different shape for each row. The original C64 keyboard has ten different keycap types: four different 1U keycaps, four different 1.5U keycaps, one 2U keycap, and the space bar.

Most keycaps are made of PBT (polybutylene terephthalate), a type of plastic that feels very nice to the touch and is also suitable for dye-sublimation printing (temperature!), unlike ABS. The clear or transparent keycaps I tried were obviously not made of PBT. I cannot recommend clear, transparent or translucent keycaps for dye sublimation or laser marking.

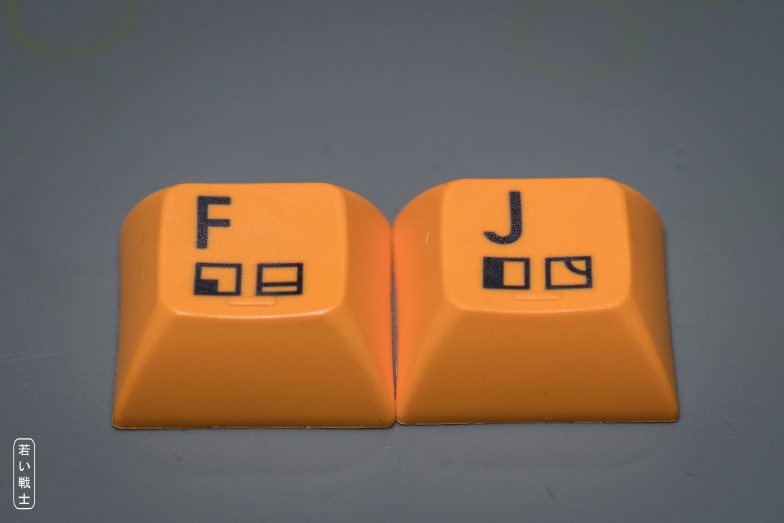
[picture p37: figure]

Figure 3: F/J homing keycaps (dye sublimation)

The F and J keys usually have a small raised bar or a bump to help touch typists locate the home-row position without looking at the keyboard. The index fingers rest on these keys when using the standard touch-typing position. Blank homing keycaps are somewhat harder to find, but may appeal to keyboard enthusiasts.

# 3. Keyboard Layouts

In addition to the standard keyboard layout, there are Danish, Swedish, and Spanish keyboard layouts, with language-specific keycaps. Of course, these also require a different Kernal ROM. In the 20th century, the language specific keycaps were modified with stickers - that is what I was told, and it is also what I have seen.

Figure 4: Standard/US keyboard layout

Apart from these, I have heard of a Turkish keyboard layout, but I do not have enough information about it. I have also heard of a German keyboard layout for the SX-64, but I have no further information about that, either.

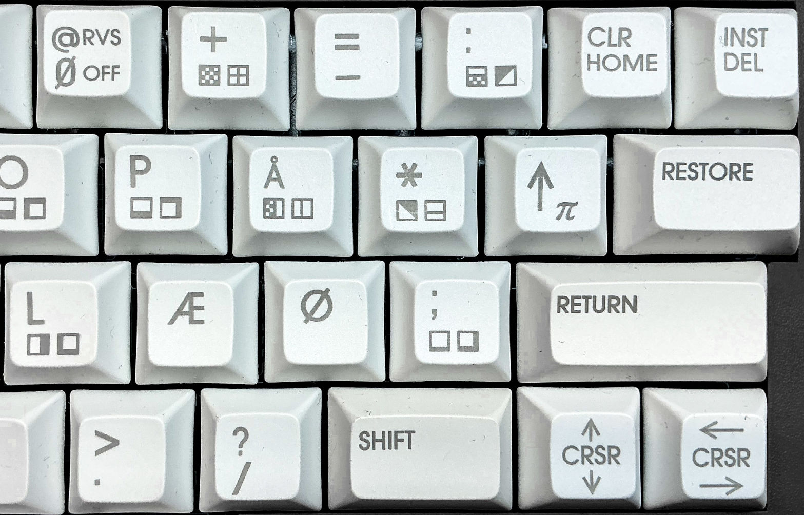
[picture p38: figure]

Figure 5: Danish-specific keycaps on the right-hand side of the keyboard

Figure 6: Swedish- (and Finnish-)specific keycaps on the right-hand side of the keyboard

The Danish and Swedish keyboard layouts require seven specific keycaps each (none of them works for both languages), while Spanish only requires three specific keycaps.

None of the keyboard layouts (even the US-/standard layout) is fully meeting the nowadays used ANSI layouts – sure, there are just more keys today. The Danish Å, Æ, Ø and the Swedish Å, Ö and Ä are in the same position relative to the other letters like on modern keyboards, while the Spanish- specific characters/letters are just moved to three specific keys.

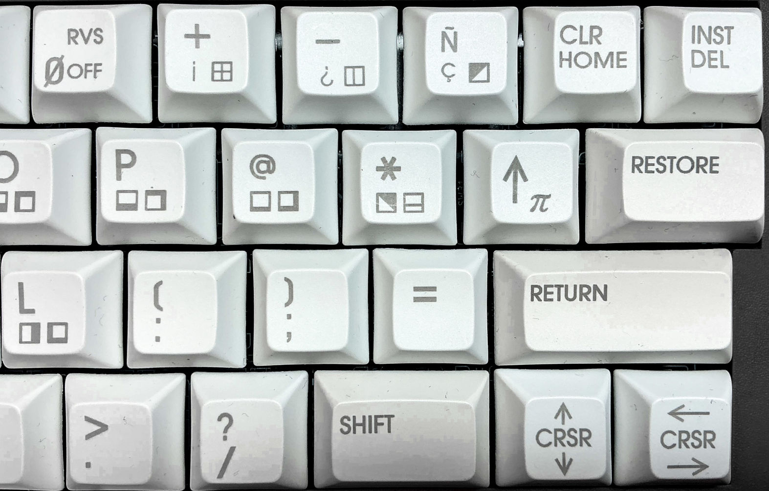
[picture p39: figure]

Figure 7: Right-hand side of the Spanish keyboard with the language-specific keycaps

# 4. Laser Engraving

Purchasing a fiber laser just to make a single set of keycaps is not very economical. The LaserPecker LP3 cost €1,260 in February 2025.

It is important to use a laser that is suitable for engraving plastic keycaps. This requires a 1064 nm infrared laser. The blue laser, that works for cutting and engraving wood will not produce any good results with plastic/PBT keycaps.

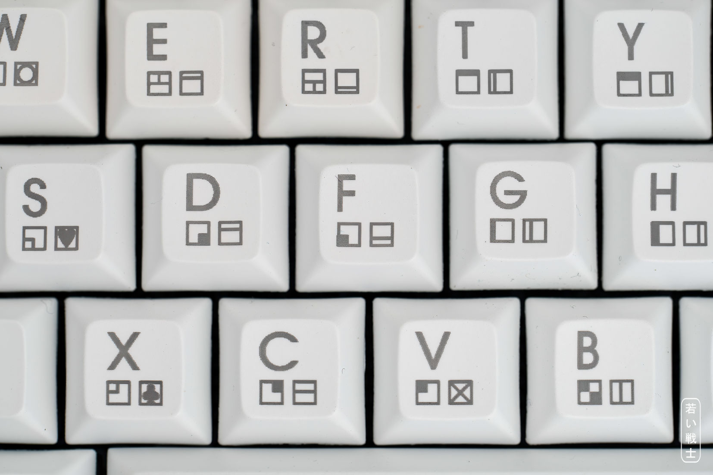
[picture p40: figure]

Figure 8: Keycaps made with a fiber laser (LaserPecker LP3)

Actually, the term “laser engraving” is somewhat misleading. The keycaps are not really engraved; they are laser marked, which means that the surface of the keycaps is locally charred by the laser. The result is a dark grey marking rather than a completely black one, but it still looks good (see Figure 8).

This process works best on white keycaps. Lighter colors also work for laser marking, it is required to optimize the parameters for laser marking for each color individually, since different colors react differently to the laser. Darker colors require significantly less energy.

For black/dark plastic, micro-foaming can be used to create a light-colored laser marking. The laser locally heats the material, causing microscopic bubbles to form below the surface and producing a contrasting light-grey-brownish mark.

Figure 9: Colored keycaps experiments

It is not possible to laser-mark transparent or clear keycaps, as shown in Figure 9. The micro-foaming on the black and grey keycaps has a slight brownish tint. It was also possible to micro-foam the translucent black keycaps (f7/f8, top row, second from the left), but the result did not look good.

Here are some LP3 parameters, that I have used for laser marking the particular colored PBT keycaps. The parameters depend on the keycap color.

Color | Resolution | Power | Depth | Passes
White | 4k | 40% | 1% | 4
Grey | 4k | 70% | 3% | 4
Orange | 4k | 30% | 1% | 4
Black | 4k | 20% | 1% | 4
Translucent black | 4k | 32% | 1% | 6
Light blue | 4k | 30% | 1% | 4
Light violet | 4k | 35% | 1% | 4

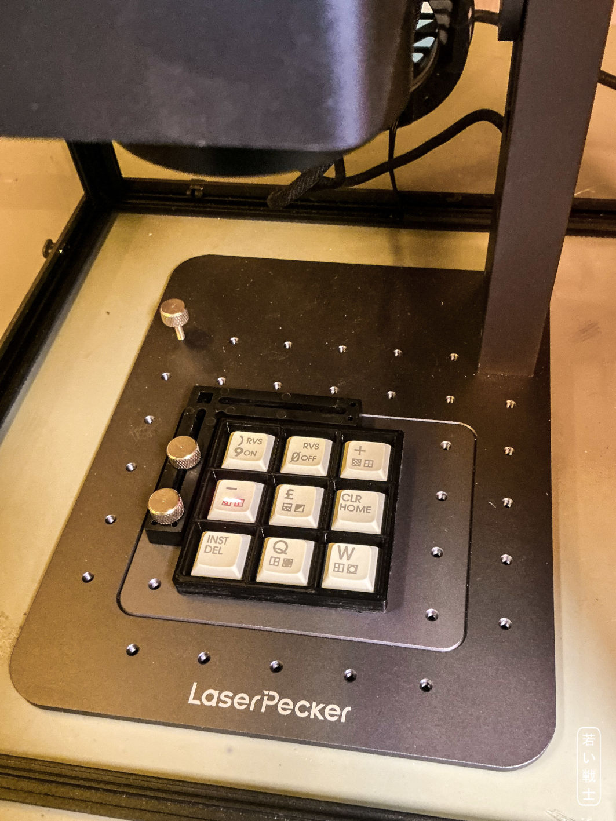
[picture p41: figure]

Figure 10: Laser marking nine keycaps simultaneously in a tray

I made the first keycap set one keycap at a time. Since positioning the keycap is the most time-consuming part of setting up the marking process, a complete set of 67 keycaps took about three hours.

To speed up the process, I made two keycap trays: one that holds nine 1U keycaps and another that holds four 1.5U keycaps (Figure 11). This significantly reduces the setup time, although it also increases the risk of ruining several keycaps at once—which happened to me once.

Figure 11: both keycap trays loaded with blank keycaps

Find the 3D print files in the \Keycaps\print_trays_3D\ directory.

I have tried different things to dye the laser marking (graphite, crayon, dye sublimation ink), none of that came any close to an acceptable result.

# 5. Filled Laser Engraving

The Legends can be laser engraved about 0.2mm deep onto the keycap and later filled with model paint. I have used Revell matt white for this purpose. johnsander from forum64.de suggested to apply a thick layer over the engraved parts, let it dry for a week and polish the excess away with an abrasive polishing wheel for rotary tools.

Figure 12: Engraved black keycap

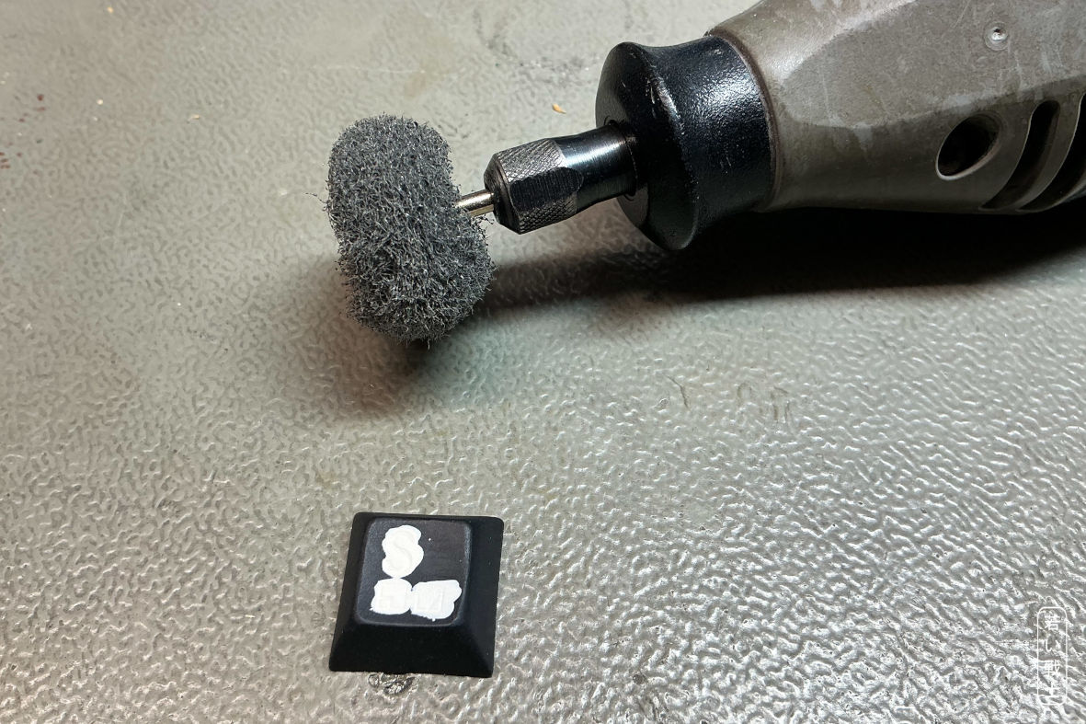
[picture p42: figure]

Figure 13: Keycap filled with white plastic paint and rotary tool

The white filling looked a bit dirty after polishing and the black surface of the keycap was not perfect, either, so I wiped it with a nano-sponge (my favorite is Ma Ant MY-065 because of the size and density) and isopropanol. The result looks impressive, almost like a double shot keycap. It is quite a bit of work to produce such a keycap. The advantage of this method is, that white on dark is possible. Most likely a coating is required to protect the white legends from getting dirty.

Figure 14: polished keycap

# 6. UV-Decals

## 6.1. General Information about UV-decals

During the documentation phase of the C64 keyboard project, I had a conversation with the BadgeMan, who provides really great labels and badges for retro-computer restorations and projects. He suggested making UV decals, which he then created from the files in this project's repository.

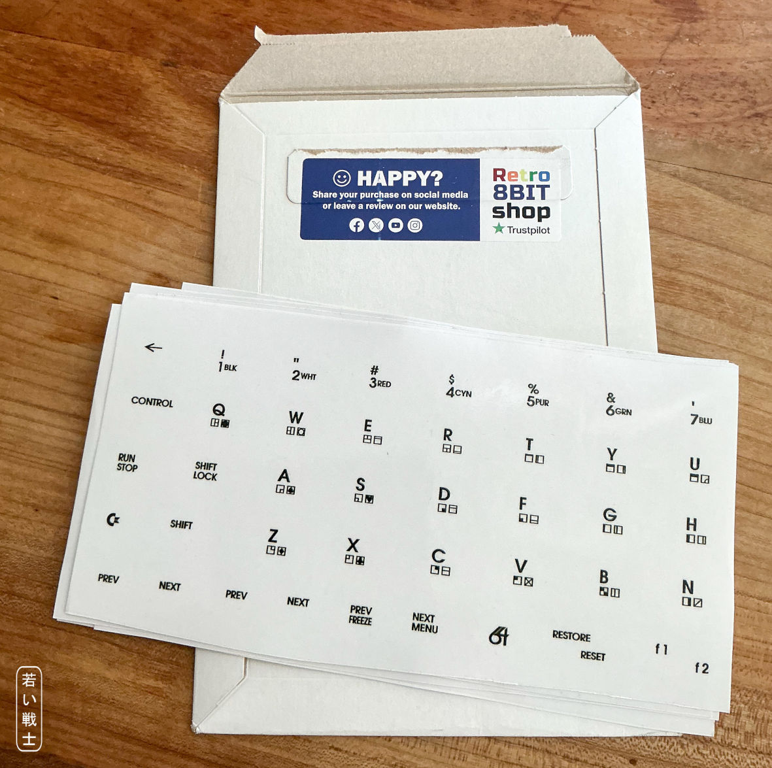
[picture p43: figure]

Figure 15: UV decal sheets from BadgeMan

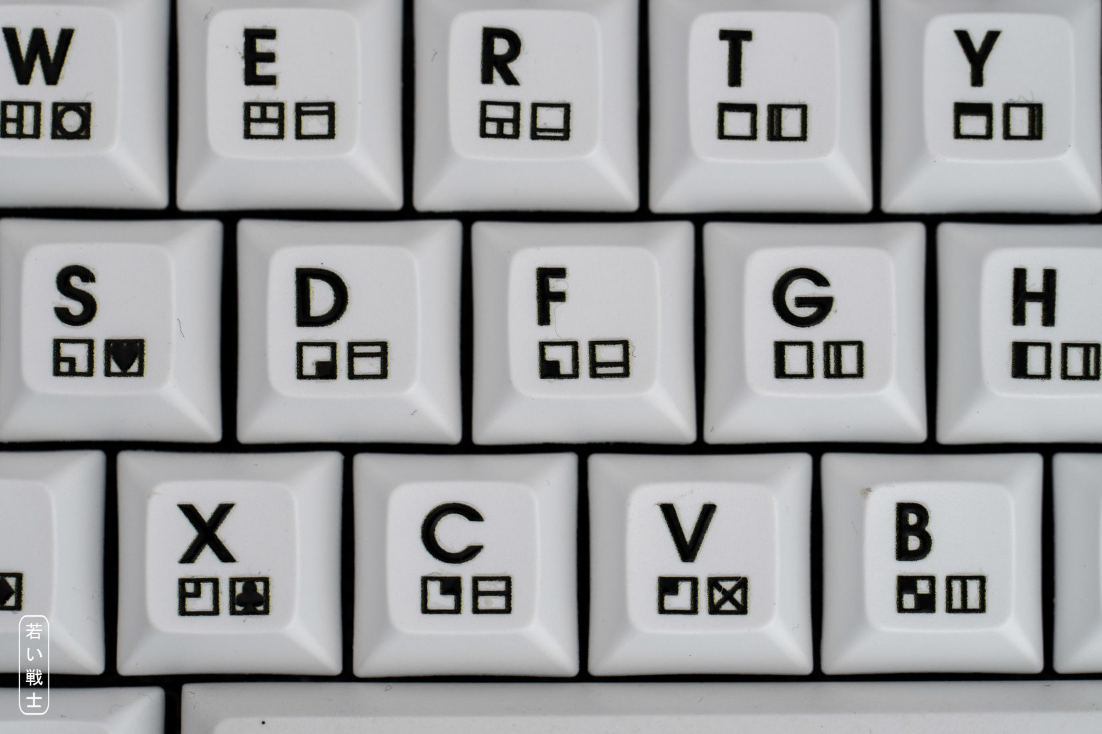
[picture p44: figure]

Figure 16: Keycaps with black UV-decals

Figure 17: Keycaps with white UV-decals

## 6.2. Wear testing

The biggest concern with using UV decals (or any other type of decal) on keycaps was their durability. After applying UV decals to a set of keycaps, I therefore tested a RESTORE key that I had deliberately made for destructive testing.

I attached it to a VICE USB keyboard (as a function key), wrote a short BASIC program to count key presses, and then pressed the key 10,000 times, deliberately applying more friction than would be expected during normal use.

After the counter reached 10,000, I took some pictures of the keycap under a microscope.

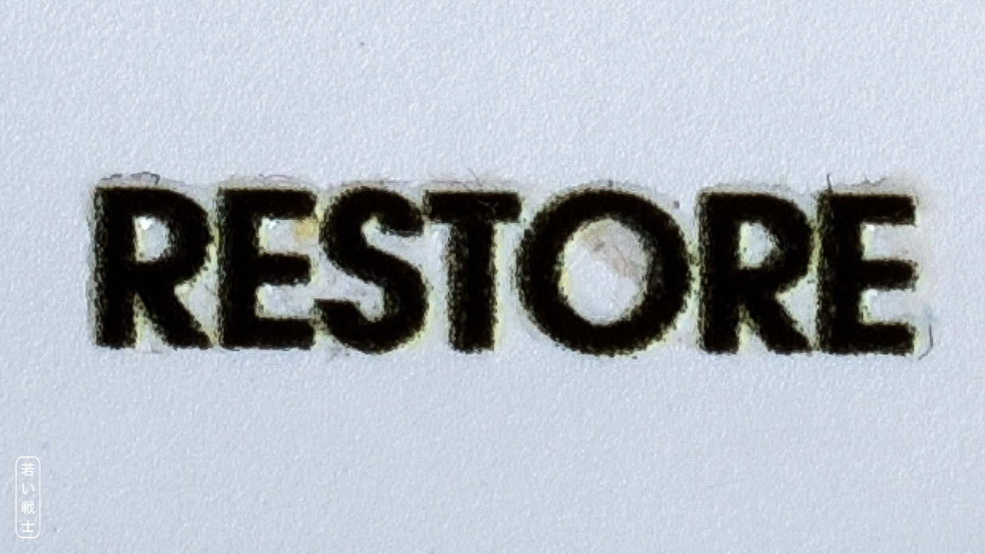
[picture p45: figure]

Figure 18: RESTORE UV-decal after 10,000 key presses (microscope image)

The result of the test was that I could not see any significant difference before and after the test. I therefore do not think that excessive wear of the UV decals is a concern.

## 6.3. Manual Alignment

A further concern was that manually aligning and positioning the UV decals might be difficult, time-consuming, or result in an inconsistent appearance.

Mr. BadgeMan told me that I just had to trust my “carpenter’s eye.” I didn’t even know I had such a thing, but I trusted it, and in my opinion, it worked out pretty well. Maybe there is a Dunning–Kruger effect for carpenter’s eyes, though.

Applying the UV decals is certainly not something you want to do before breakfast, but it didn’t take much longer than an hour and a half to finish the entire set.

What was sometimes difficult and annoying was that, in a few cases, parts of the decals did not stay on the keycap when I peeled off the protective foil. The left PETSCII icon on the C key in was one such case. Carefully reapplying the decal and applying some mild, but not excessive, pressure with a rubber eraser helped in by far the majority of cases, making the damage virtually invisible.

Mr. BadgeMan told me that I just had to trust my “carpenter’s eye.” I didn’t even know I had such a thing, but I trusted it, and in my opinion, it worked out pretty well. Maybe there is a Dunning–Kruger effect for carpenter’s eyes, though.

Applying the UV decals is certainly not something you want to do before breakfast, but it didn’t take much longer than an hour and a half to finish the entire set.

What was sometimes difficult and annoying was that, in a few cases, parts of the decals did not stay on the keycap when I peeled off the protective foil. The left PETSCII icon on the C key in Figure 17 was one such case. Carefully reapplying the decal and applying some mild, but not excessive, pressure with a rubber eraser helped in the vast majority of cases, making the damage virtually invisible.

Figure 19: perspective view on a UV decal

## 6.4. The Process of applying UV Decals

### 6.4.1. Required Tools

There are actually no fancy tools required for applying UV decals. I only use an X-Acto knife (scalpel) and a pair of scissors. A rubber eraser is helpful for pressing the UV decal onto the keycap.

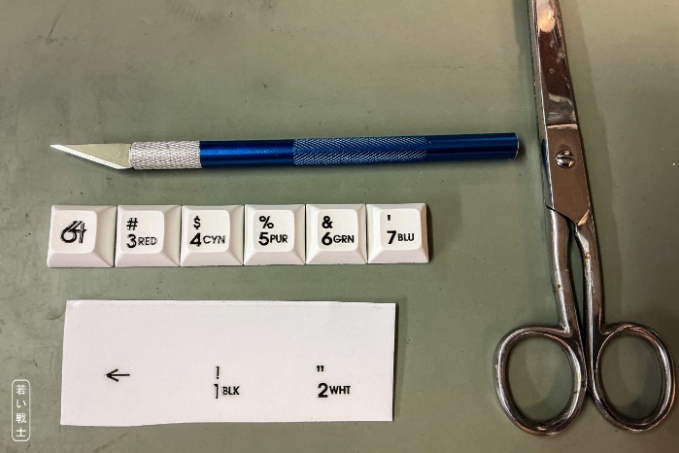
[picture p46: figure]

Figure 20: The required tools

### 6.4.2. Cleaning the Blank Keycap

A good practice is to rub the keycap with isopropanol and a clean, lint-free cloth. I recently came across “Cleanroom Wipers” from the MECHANIC brand on AliExpress, which I really like. I usually use them for cleaning up flux residues (also with the help of isopropanol), and they do an excellent job. They are anti-static, BTW.

Figure 21: Cleanroom whipes

### 6.4.3. Step One: Cutting Out the Decal

The UV decals are intentionally printed with slightly more space between them. It is important to cut them out generously enough to leave sufficient space to hold them. This is essential for positioning the decal above the keycap before applying it.

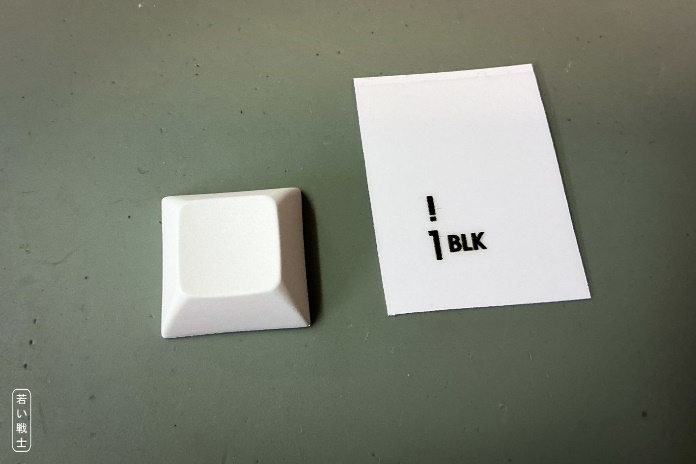
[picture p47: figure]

Figure 22: cutting out the decal

### 6.4.4. Step Two: Positioning the Decal

After peeling off the protective paper, it is easiest to hold and position the decal with the X-Acto knife. I usually hold the opposite corner with my fingers, because a slight tension helps to maneuver the decal above the keycap.

Some decals are positioned off-center, so it is a good idea to keep a picture of the keyboard layout at hand (Figure 4). Eyeballing the correct position of the decals works remarkably well. Most keycap legends are centered, and the PETSCII symbols on many keycaps provide a good reference point. The horizontal positioning should not be completely off, but most key rows are not vertically aligned anyway, so there is definitely some tolerance. The function keys are actually not difficult either—or perhaps you simply have some practice by the time you get there.

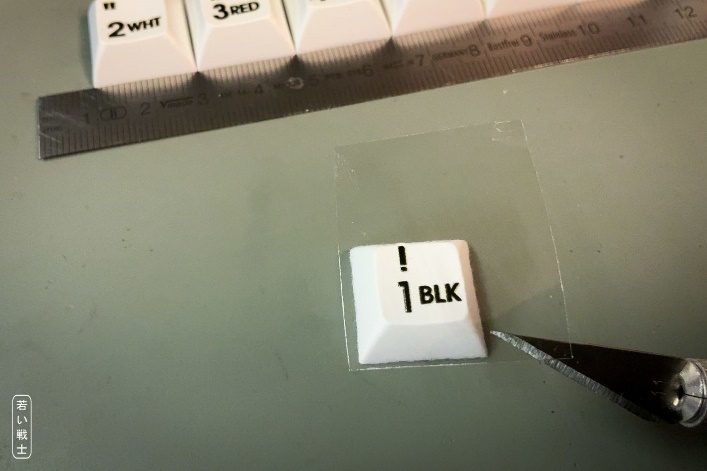
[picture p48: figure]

Figure 23: Positioning the decal

### 6.4.5. Step Three: Attaching the UV Decal

After sticking the decal onto the keycap, I briefly press it onto the keycap with a rubber eraser. Not for very long, and definitely not very hard—just using the weight of my hand. We don't want to deform or break it.

Figure 24: Sticking the UV decal to the keycap

### 6.4.6. Step Three: Peeling Off the Top Foil

Peeling off the foil is a crucial task. You need to carefully watch the keycap legend to prevent breaking it or to lose parts of it (like the dot of the ”!”). If something breaks, not everything is lost. Just lower the foil partially back on the keycap, press it slightly to the keycap and maybe retry peeling form an different direction. This sound more dramatic than it actually is. I only had problems with a handful of keycaps and I could fix all of them except the said dot from the ”!”.

Peeling off the foil is a crucial step. You need to carefully watch the keycap legend to prevent it from breaking or losing parts of it (like the dot of the “!”). If something breaks, not everything is lost. Just lower the foil partially back onto the keycap, press it lightly onto the keycap, and maybe try peeling it off again from a different direction. This sounds more dramatic than it actually is. I only had problems with a handful of keycaps, and I was able to fix all of them except for the aforementioned dot of the “!”.

Figure 25: Peeling off the foil

# 7. UV Printing

UV printing is the method that requires the highest initial investment. UV ink is expensive and has a limited shelf life: it expires after about a year, or after only three months once opened (Mimaki). UV printers start at around €2,500 and can cost considerably more. There have also been a couple of crowdfunding campaigns recently (as of late 2026).

UV printing cannot really be recommended for producing just one or a few keyboards at home. There are UV printing services available, though. Since I do not do UV printing myself, I cannot provide any further insight into this method.

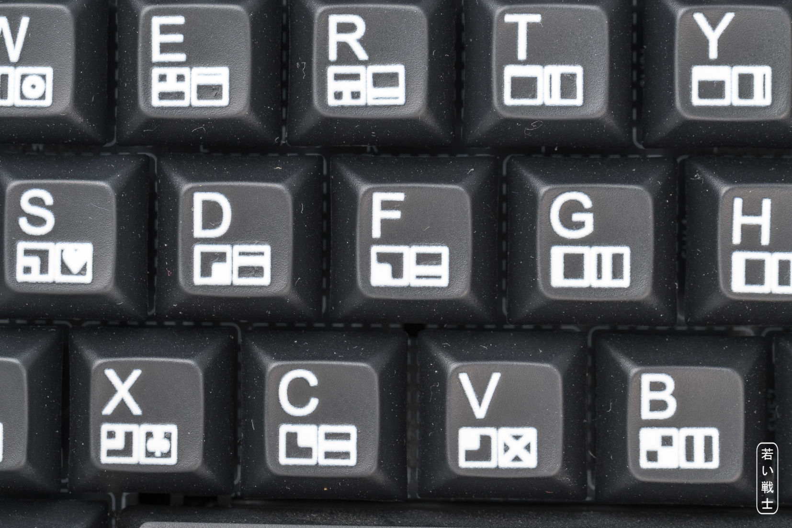
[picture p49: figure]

Figure 26: UV print (white on black keycaps) (by AKCZ/norths.de)

As with UV decals, it is possible to have white legends on black (or other dark) keycaps. The result may look slightly unsharp, although it is somewhat better than with white UV decals. When printing light colors onto dark objects, a white ink layer is typically used underneath the colors to provide a sufficiently bright and opaque base. The additional print layer can result in slightly less sharp edges, which may be noticeable with small keycap legends.

There is a single printing tray that can hold all keycaps (except the space bar, which does not require a print). This tray is meant for UV printing. The size is 191.3mm x 162.2mm x 7.9mm. The print file (vector graphics) is \Keycaps\Inkscape\DSA_keycaps_in_single_tray.svg. Find the 3D print files in the \Keycaps\print_trays_3D directory.

Figure 27: Tray for UV printing, which holds all keycaps

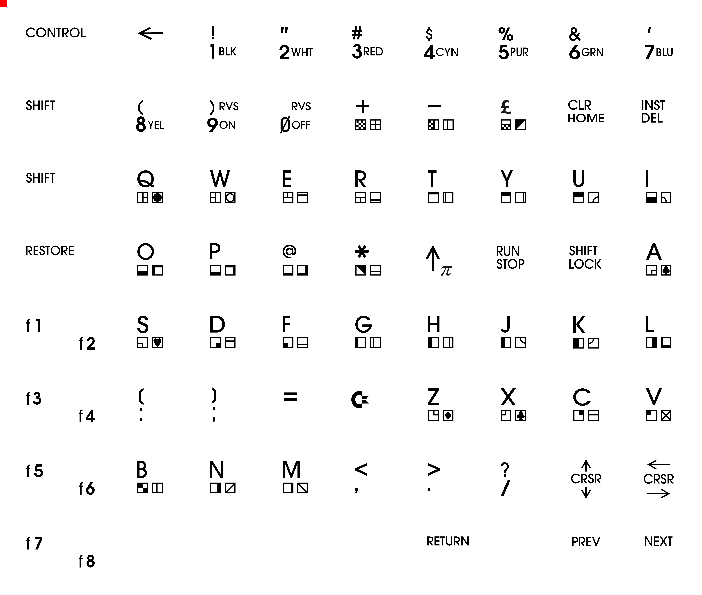
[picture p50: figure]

Figure 28: vector graphic file suitable for the above tray

# 8. Dye Sublimation

## 8.1. Description of Dye Sublimation

Dye sublimation is quite a popular method for adding legends to keycaps. The legends are printed in mirror image onto special transfer paper using a dye-sublimation inkjet printer and dye-sublimation ink. Colored prints are also possible, but only on white keycaps.

Figure 29: Hand-made dye sublimation keycaps

The paper with the printed legend is cut out and placed on the keycap with the ink side facing down. The paper is secured with heat-resistant Kapton tape. Heat (about 200 °C) and pressure are then applied, ensuring that the paper is held closely against the keycap surface. The dye sublimates and diffuses into the keycap material.

Sublimation is when a solid (dye) turns directly into a gas without becoming liquid first. Due to the process, legends are slightly less sharp, than laser marked legends. This is a minimal imperfection and hardly noticeable.

The keycap material should be PBT rather than ABS, as PBT can withstand the temperatures required for the process.

The dye sublimation transfer paper print can be found in the /Keycaps/Inkscape folder. It is not mirrored, since the printer driver of my dye sublimation printer driver already mirrors the printout. The sheet contains every legend twice to allow failures. Further, there are the language specific keys for Spanish, Danish and Swedish.

If you can buy pre-printed dye sublimation transfer paper (see Figure 31), the investment in equipment is comparatively small. My method uses a 10 cm × 10 cm hot plate (about €27 on AliExpress), some aluminum foil for making a mold, and 15mm wide Kapton tape.

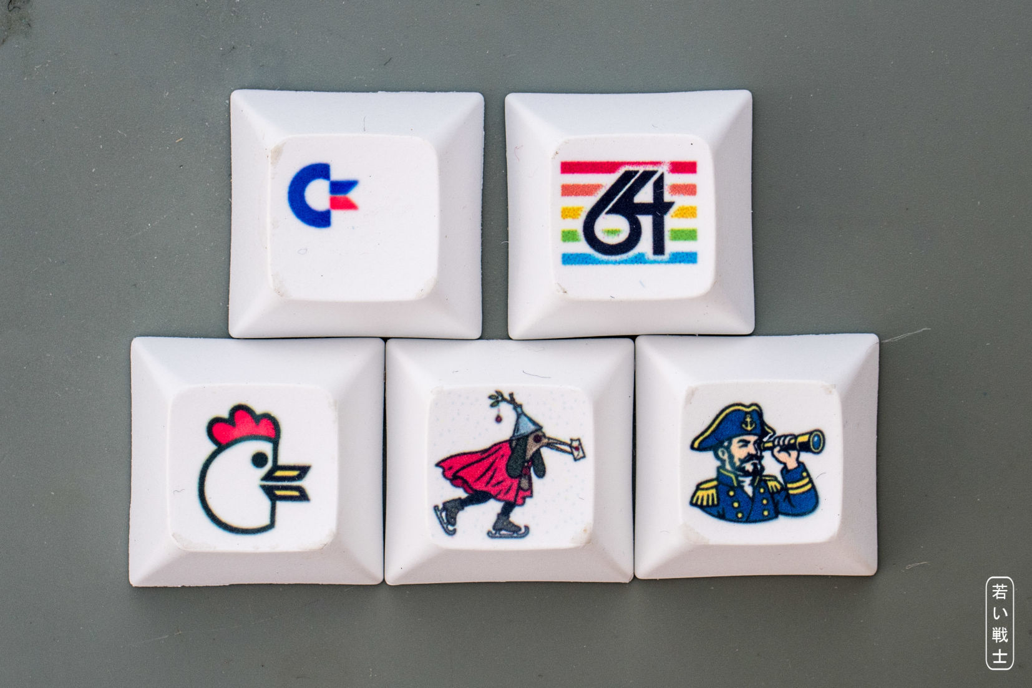
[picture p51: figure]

Figure 30: Colored dye sublimation keycaps

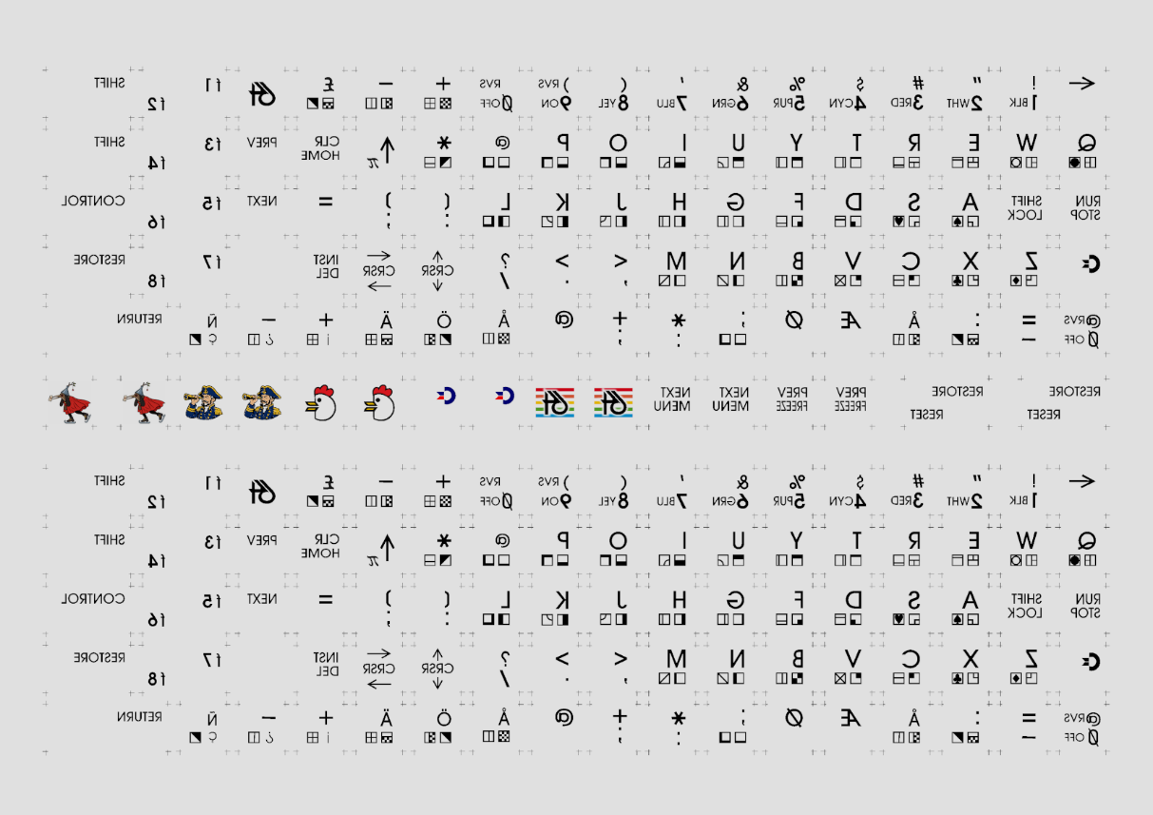
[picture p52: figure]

Figure 31: Dye sublimation transfer paper with C64 keycap legends (mirrored)

I have found videos suggesting the use of a hair straightener with adjustable temperature and silicone blocks for heat transfer. The adjustable hair straighteners I have seen start at about €50, and silicone is not particularly cheap either. In addition, silicone does not conduct heat very well, whereas the hot plate can also be used for SMD soldering, for example, when assembling the keyboard PCB. Hot plate soldering is a very good method for soldering single-sided SMD PCBs. I have been using this method for four years now and have never gone back to other methods.

Further tools:

- A benchtop dispenser for Kapton tape
- An X-Acto knife with a fresh blade
- A steel ruler
- Tweezers for handling the transfer paper cutouts
- A (self-healing) cutting mat
- Pliers that can reach into the keycap from below or a 5.5m – 7mm socket wrench
- A pair of scissors
- A count down timer

Figure 32: Workbench for manual dye sublimation

## 8.2. Wear testing

Keycaps with dye-sublimated legends can withstand a reasonable amount of wear, since the dye diffuses into the plastic. I rubbed a discarded keycap two hundred times with a fiberglass pen, which I normally use for cleaning electrical contacts. After the test, the dye showed no visible signs of damage, and the keycap legend looked as good as it did before the test.

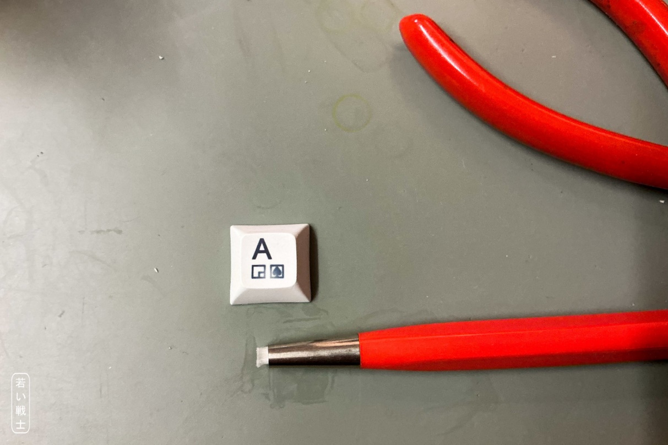
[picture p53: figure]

Figure 33: The (discarded) "A" keycap before the wear test (with glass fiber pen)

As an additional durability test, the keycaps were soaked in isopropanol for about 12 hours. They did not lose any sharpness or contrast.

Figure 34: Keycap after wear testing

## 8.3. Hot Plate Method for Dye Sublimation

### 8.3.1. Building the mold

It is important that heat and pressure are applied evenly across the entire top surface of the keycap. Aluminum foil can be shaped to fit the cavity of this surface and also conducts heat very well.

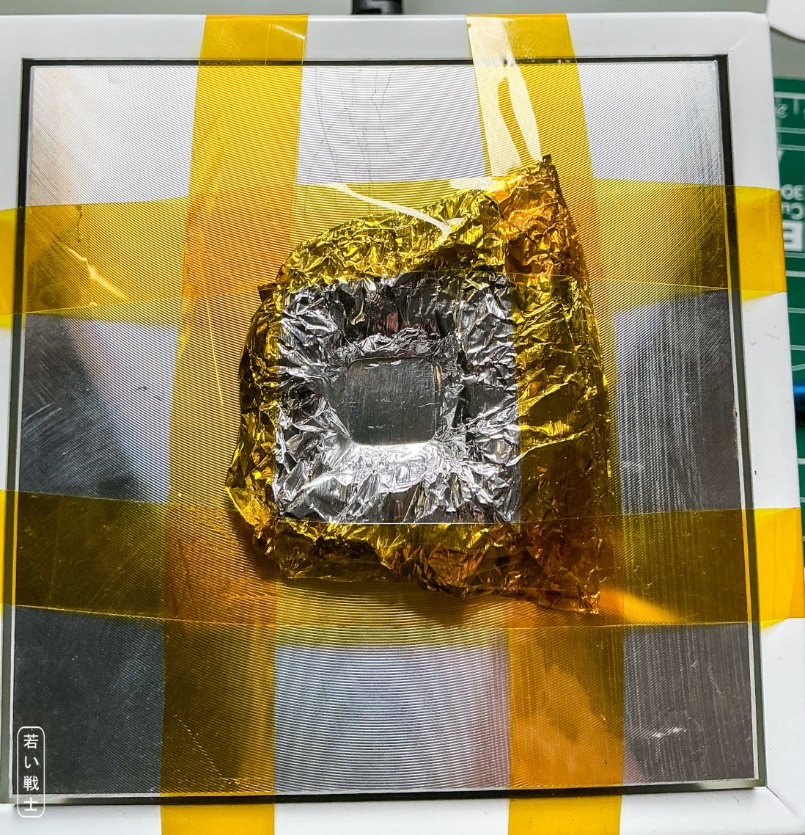
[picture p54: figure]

Figure 35: Aluminum foil mold attached to the hot plate with Kapton tape

Start with a generous amount of aluminum foil and form it into a square several times larger than the keycap. Some extra material should be placed underneath the area that will be shaped to fit the keycap. Then, firmly press a keycap of the size to be printed firmly onto the aluminum foil to form the mold. A few small wrinkles in the foil are not a major problem, but a dent can result in partially blurred legends.

Finally, secure the mold to the hot plate with (heat-resistant) Kapton tape.

### 8.3.2. Cutting The Transfer Paper

I added four register marks to the keycap legends to make it easier to cut them precisely to the size of the keycap's top surface. The register marks are shaped like crosses. This allows you to cut an entire row of keycaps while leaving a small part of each cross visible, so you can still identify the vertical cut lines.

The cuts need to be made quite precisely, as this makes it easier to properly position the individual pieces of transfer paper on the keycap.

Figure 36: Cutting out a single keycap legend

It is important to cut off all four corners of the legend, as they may contain a small part of a register mark. Otherwise, you may end up with some wonderful little dots on your keycap that will not wear off. (see Figure 43).

### 8.3.3. Attaching The Legends to The Keycap

First, cut a sufficiently long piece of Kapton tape. For a 1U keycap, about 4 cm is sufficient; larger keycaps require a slightly longer piece. The tape should be long enough to fully cover the sides of the keycap.

Place the tape on the workbench with the sticky side facing up. Then place the piece of transfer paper, printed side up, centered on the tape. I use tweezers for this job.

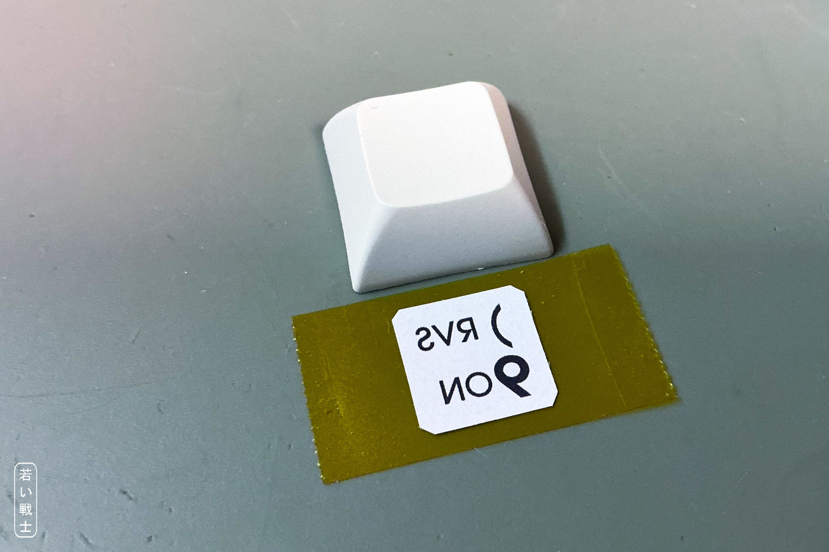
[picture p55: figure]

Figure 37: Placing the transfer paper on the Kapton tape

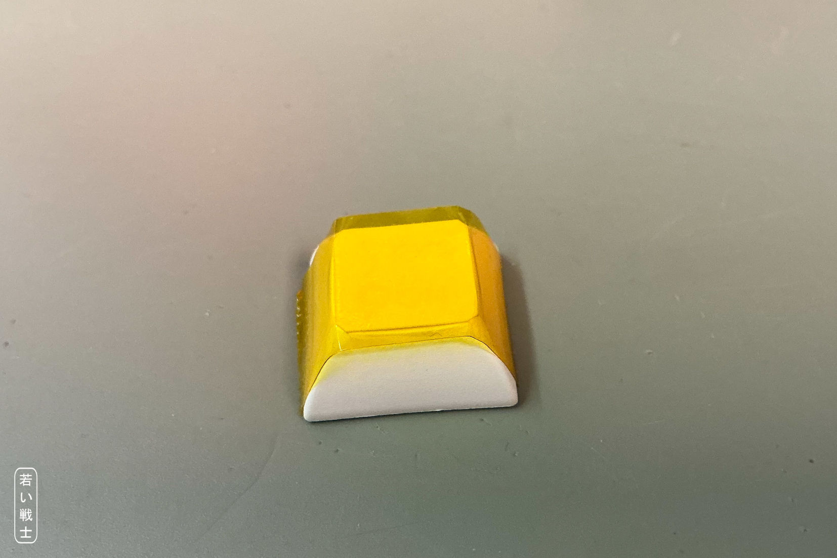
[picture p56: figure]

Figure 38: Attaching the transfer paper on the keycap

Since the cut transfer paper pieces are sufficiently precise, positioning the legends is quite straightforward. After adjusting the position, press the tape onto the top of the keycap and rub it down on both sides so that the legend stays in place. The paper should be able to reach all the way into the deepest part of the keycap's top cavity.

### 8.3.4. Heat Pressing Keycaps

As mentioned before, the important factors in dye sublimation are heat (200°C), time (90 seconds), and pressure.

Set the hot plate to 200°C. Let it heat up to that temperature, then wait a few more minutes until the aluminum foil mold has also reached the required temperature.

Hold the keycap with pliers directly above the mold. Start the 90-second countdown, then lower the keycap precisely into the mold and press down firmly (Figure 39). If you do not position it accurately enough, you may damage the mold. This is the point where concentration is required. There is no need to rush it—taking an extra five seconds to position the keycap correctly does not matter.

Note: I have damaged a keycap due to pressing very hard. The pliers deformed the top surface. I then switched to pressing with a socket wrench (as can be seen in Figure 32).

Figure 39: Heat pressing the keycap

I measured the force I apply using a scale. It showed more than 11 kg, which corresponds to a force of about 110 N. This might be my typical “more power” approach to things.

Before I tried holding the keycap with pliers, I used tweezers, which allowed me to apply a force of about 70 N (equivalent to 7 kg on the scale). This sometimes resulted in blurred legends and discarded keycaps. Also, you can lose your grip on tweezers more easily than on pliers. Keep in mind that the hot plate is at 200°C.

After increasing the applied force, I stopped ruining keycaps.

### 8.3.5. Transfer Paper Residues

After heat pressing, significantly less dye remains on the transfer paper than before (Figure 40). The high pressure may cause the transfer paper to stick to the keycap. Usually, it can be peeled off using an X-Acto knife. Slide the blade between the paper and the keycap. There is usually at least one side where it is easier to get the blade underneath.

If small pieces of paper remain stuck to the keycap (see Figure 41), soaking them in hot, soapy water or running them through a dishwasher cycle may help remove them.

I have not tried the dishwasher method, but I have placed the keycaps in a heat-resistant bowl, added some dish soap, and poured boiling water over them. Once the water had cooled to lukewarm, I rubbed the remaining paper off with my fingers.

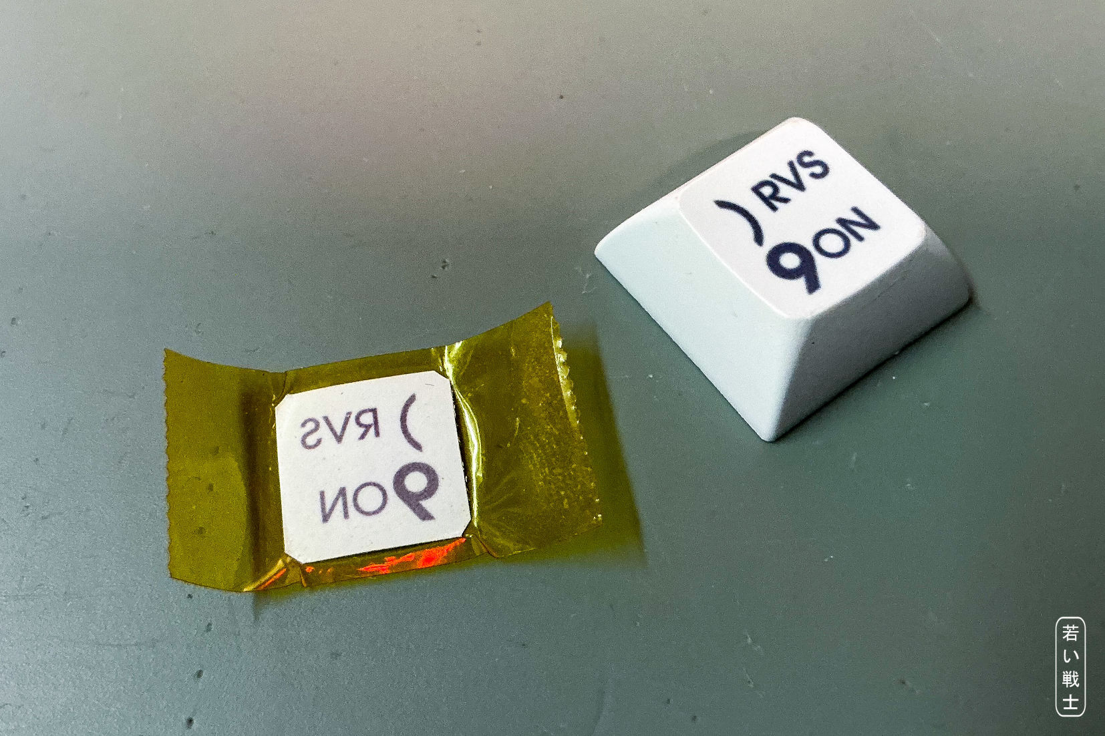
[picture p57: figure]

Figure 40: Keycap and transfer paper after heat pressing

Figure 41: Residues of transfer paper after heat pressing

## 8.4. Dye Sublimation – What Can Go Wrong?

I have not made many sets of dye-sublimated keycaps yet. After a short learning phase to figure out how to make them, I did not have many failed attempts—in fact, only one.

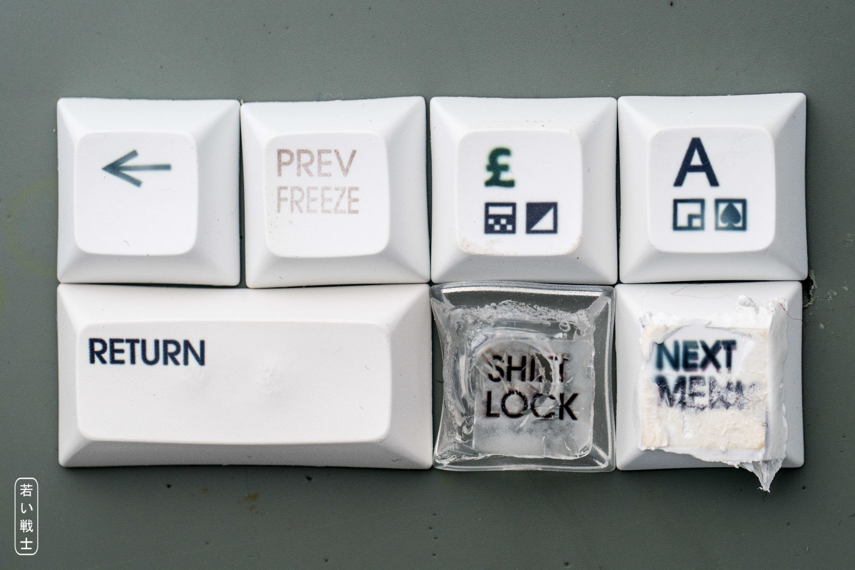
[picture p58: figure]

Figure 42: Failes dye sublimation attempts

- Left arrow: Pressing time too short
- PREV/FREEZE: Pressing time too short
- £: Insufficient and uneven pressure
- A: A dent in the aluminum foil mold between the PETSCII characters
- RETURN: Keycap deformed by excessive pressure from overly pointed pliers
- SHIFT LOCK: Obviously not made of PBT
- NEXT/MENU: Excessive temperature (230°C)

Initially, I did not use a timer, which resulted in the two keycaps with insufficient pressing times. The dye simply needs enough time to transfer to the keycap. A pressing time of 90 seconds turned out to be sufficient.

At first, I pressed the keycaps down using tweezers, but the pressure I could apply (about 70 N) turned out to be insufficient. Areas subjected to too little pressure resulted in blurred legends. Using pliers and, later, a socket wrench, I could easily apply about 110 N (equivalent to the weight of an 11 kg mass). This was sufficient even for the larger 1.5U keycaps and the large 2U RETURN keycap.

My first attempt at dye-sublimating the RETURN keycap failed because I applied too much pressure with overly pointed pliers. The pliers almost pierced the keycap material.

On one occasion, I accidentally dropped a keycap onto the aluminum foil mold, leaving a dent in its surface. The corresponding area of the legend was not sharp.

The clear keycap was declared to be made of PBT, but it obviously was not. After doing some research, I doubt that clear or transparent PBT keycaps are readily available at all. I would recommend avoiding keycaps described as “clear,” “transparent,” or “translucent” for dye sublimation.

I deliberately applied excessive heat (230°C), and the result was as expected. The recommended hot plate temperature is 200°C.

Figure 43: The register marks for cutting made their way to the keycap

Here, I forgot to cut off the corners of the transfer paper. They were barely noticeable on the paper but stand out clearly on the keycap.

# 9. Comparison of Methods

This table shows the same keycaps produced with the different methods.

Laser Marking
UV decals (black)
UV decals (white)
UV print (white)
Dye Sub

Note: The photos were taken on different days, so the camera and lighting setup was not always the same. This results in slightly different sizes and appearances.

The white UV print was made using a different keycap print file. The PETSCII characters are slightly larger, and the letters use a different font (see the “Q”).

Find the original images (not scaled down) in the \Keycaps\pictures\ folder.

| Laser Marking | UV Decals | UV Printing | Dye Sublimation
Costs for a printing service | ? | | | ?
Investment for own tools | 1600€ | (>5000€) | >2500€ | 500€/30€***
Time per keycap set | 1h | 1h | ? | 4h
Costs per print (set)
Print sharpness (black on white) | | | ?
Print contrast (black on white) | | | ?
Prints white on black
Print sharpness (white on black) | | | | d.n.a.
Print contrast (white on black) | Brownish tone | | | d.n.a.
Multi-color keycaps | | | | *
Keycaps of different colors | | | | **

d.n.a. = does not apply

* works on white keycaps only

** not too dark, no white dye is possible

*** The investment depends on whether you buy a dye-sublimation printer or use pre-printed transfer paper.

# 10. Other Ways

## 10.1. Buying Keycaps

The C64 Ultimate/Blingboard64 keycaps will fit this keyboard project. They are the best possible reproduction of the original keycaps and can be purchased fro. There are “original” and “Blingboard64” keycaps. The latter are the proper choice. They fit the switches in the SWxxA position (modern) and require a 7U stabilizer for the spacebar.

The only disadvantage is that the “PREV” and “NEXT” key cannot be populated, which means, that quite a bit of functionality (Kernal switching, scrolling through the LED strip illumination modes) cannot be used.

## 10.2. Using Original Keycaps

Using original keycaps is also an option. Since the switch connector of the keycaps does not fit on the MX compatible switches, there is are adapters required for the keycaps. These are the same like for the MechBoard64. They can be purchased from https://www.retrofuzion.com/ (MechBoard 64 Injection Molded Keycap Adapters). If you chose this way, please make sure, that they are not sold out.

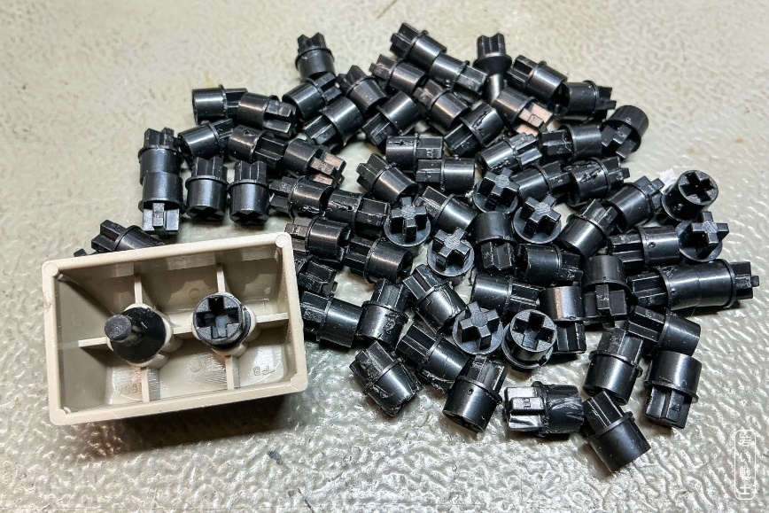
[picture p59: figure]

Figure 44: 1.5U keycap with keycap adapters (Retro Fuzion)

The disadvantage is again the 9U spacebar is occupying the space for the “PREV” and “NEXT” key, which offer the Kernal switching and LED strip functionality. Also, the adapters add some height to the keycaps (1.9mm).

The original 9U space bar requires a 9U stabilizer, which cannot be purchased. The instructions on making such a stabilizer are part of this repository.

The 1.5U switches have to be populated in the proper position (SWxx instead of SWxxA) for these keycaps.

## 10.3. Print Services

I have tried norths.de for UV printing, I did not pay money for that, though. So, I cannot tell the price of the service. I am evaluating the UV printing capabilities of teiledrucker.at, who is specialized on printing plastic bricks. The keycaps are not printed yet, due to a printer breakdown. I will take pictures and update this document ASAP.

In forum64.de, I have received recommendations for other keycap services.

- https://yuzukeycaps.com/de
- https://maxkeyboard.com/

I did not try them out, so I cannot say anything about them.

1. Check if they only offer standard keyboard layouts. The C64 keyboard is not standard
2. Check the keycap profiles, they offer. If those are different for every row, make sure they offer 1.5U for every row, and 2U keycaps for Row 3 (see Figure 2)
3. Ask for the price.
4. Please let me know your experience.

# 11. Acknowledgements

I would like to thank everyone who contributed ideas and suggestions for making keycaps for this project:

- Marco Van de Meulenhof for the idea of using UV decals and for printing them.
- johnsander from forum64.de for explaining how engraved keycaps can be filled with paint.
- Anthony Jacoway for the idea of using aluminum foil as a mold for dye-sublimation printing on keycaps. This was a game changer!
- David Ludwig (norths.de) for UV-printing the set of black and orange keycaps.
- Peter Schulz (teiledrucker.at) for discussing the keycap printing tray with me.

I am also grateful to everyone who followed my progress in making the keycaps, asked questions, and joined the discussions. Your interest and feedback have helped me put together this documentation and may well inspire further keyboard and keycap projects.

# 12. Product References and Disclaimer

Throughout this documentation, I mention specific products, brand names, and suppliers. These references are provided solely for informational purposes and are not intended as advertising or endorsements. I have not received any compensation or other benefits for mentioning them. I refer to these products and suppliers simply because I have used them myself and can therefore share my personal experience with them.

# 13. Revision history

## 13.1. Rev. 0.0

- Initial release

How_to_keycaps.docx 09.10.2026 18:23 Drafted by Sven Petersen Page 2 of 2 Doc.-No.: 230-6-01-00.0

How_to_keycaps.docx 09.10.2026 18:23 Drafted by Sven Petersen Page 1 of 1 Doc.-No.: 230-6-01-00.0

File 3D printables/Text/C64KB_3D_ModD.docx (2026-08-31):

C64 Mechanical Keyboard & Kernal Switcher

3D Printables

Module Description

# 1. Introduction

The C64 Keyboard PCB requires either a mounting frame for installation in a C64 or C64C case, or a USB keyboard case. All parts were designed to fit on a 3D printer with a 25 cm-wide print bed.

The mounting frame has been tested with various cases, including the C64 Breadbin, different C64C cases, and the C64C clip case.

There are two different versions of the C64 USB keyboard:

- Classic: For use with original keycaps and a classic 9U space bar.
- Modern: For use with modern keycaps, including DIY and Blingboard64/C64U keycaps.

The difference between the two versions is the plates.

# 2. The Mounting Frame

The mounting frame is attached to the C64 Keyboard PCB using 16 C 2.2 × 6.5 H DIN 7981 self-tapping sheet-metal screws.

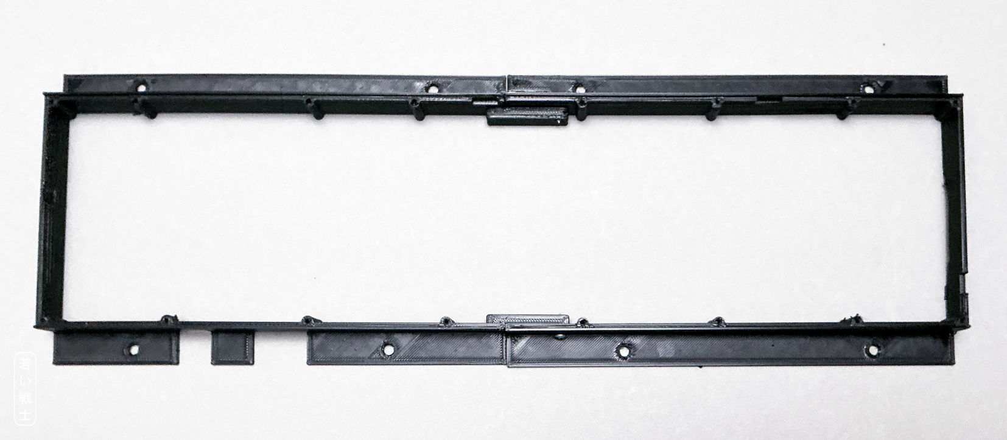
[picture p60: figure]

Figure 1: Mounting frame (Rev. 1)

For PCB Rev. 0, a Rev. 0 mounting frame is required. For PCB Rev. 1 and Rev. 2, a Rev. 1 mounting frame is required. The difference is that the Rev. 1 mounting frame supports a 9U stabilizer, which requires one of the mounting screws to be moved a few millimeters to the right.

A stiffener is an optional part used to increase the rigidity of the PCB. It is attached to the keyboard using 9 C 2.2 × 6.5 H DIN 7981 self-tapping sheet-metal screws (Figure 4). In my experience, the stiffener is not required. It is identical for all PCB revisions.

There are two additional C 2.9 × 9.5 H DIN 7981 screws that hold the two sides of the frame together. They are installed approximately in the middle of the north and south sides, as shown in Figure 2.

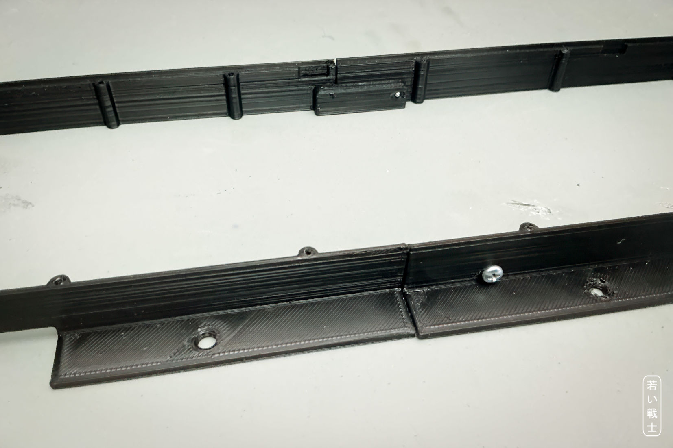
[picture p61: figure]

Figure 2: the two halves of the frame, joined by two horizontal screws

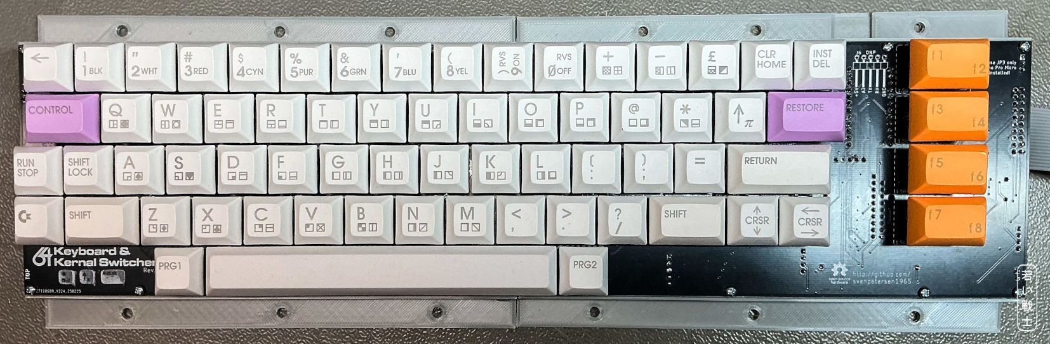
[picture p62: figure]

Figure 3: The keyboard PCB Rev. 0 mounted on a Rev. 0 frame

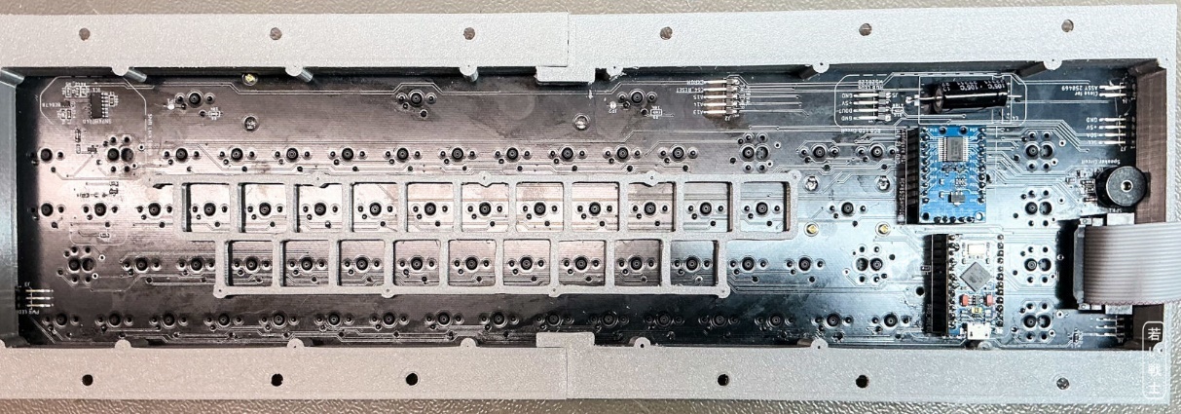
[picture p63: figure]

Figure 4: Keyboard with stiffener

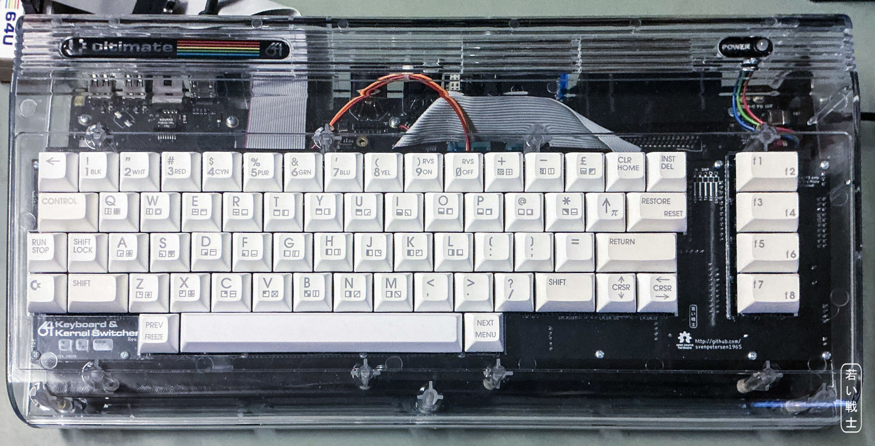
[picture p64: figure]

Figure 5: Keyboard mounted in a C64 breadbin case (clear, RetroFuzion)

In a C64C clip case, the keycaps protrude slightly from the case. This is because the PCB needs to rest against the case. The height of the mounting frame is determined by the height of the clips.

With a standard C64C case, the height of the keycaps is perfectly acceptable.

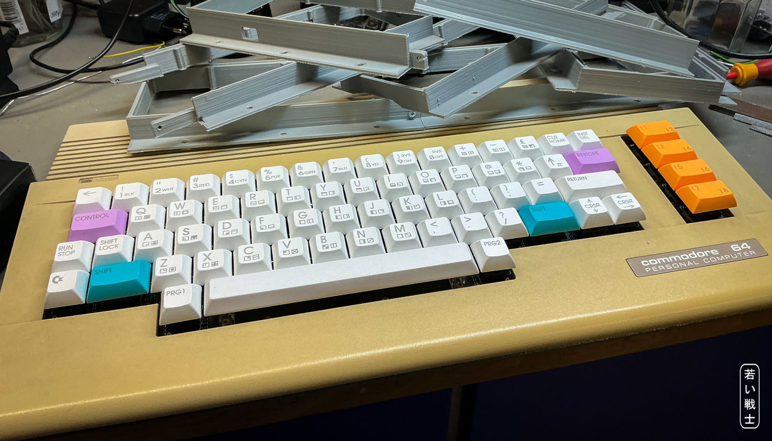
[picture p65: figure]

Figure 6: Keyboard in a C64C clip case

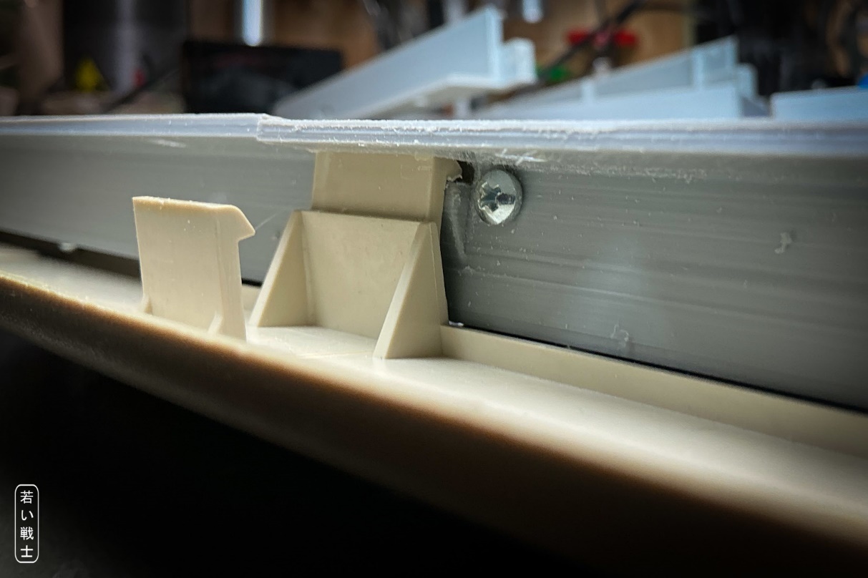
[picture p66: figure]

Figure 7: The clip case clip, the C 2.9x6.5 H screw

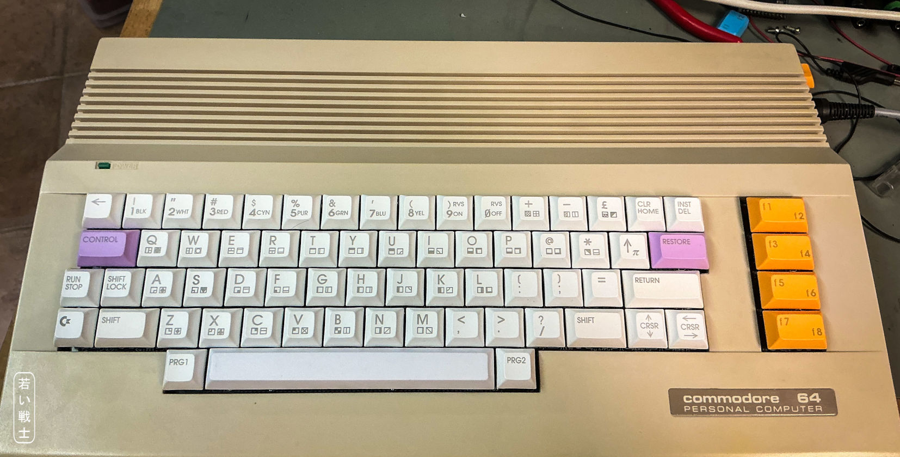
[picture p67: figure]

Figure 8: C64 keyboard in a normal C64C case

# 3. The C64 USB Keyboard Case

The USB keyboard case consists of 7 different parts:

- The plate (standard or classic) – two halves
- The case – two halves
- The bottom – 3 parts

The plate is elevated 5 mm above the PCB and has cutouts for the keyboard switches. To fit on an average 3D printer, it is printed in two parts.

There are two versions:

- Standard: all 1.5U switches populated in SW**A positions, 7U stabilizer
- Classic: all 1.5U switches populated in SW** positions, 9U stabilizer

The case is divided into two halves for the same reason: to fit on a standard 3D printer.

The bottom is divided into three parts. The middle part spans over both case halves to add some stability.

The USB keyboard case requires 42 C 2.2 × 6.5 H DIN 7981 self-tapping sheet-metal screws:

- 16 for the PCB
- 14 for the plate
- 12 for the bottom

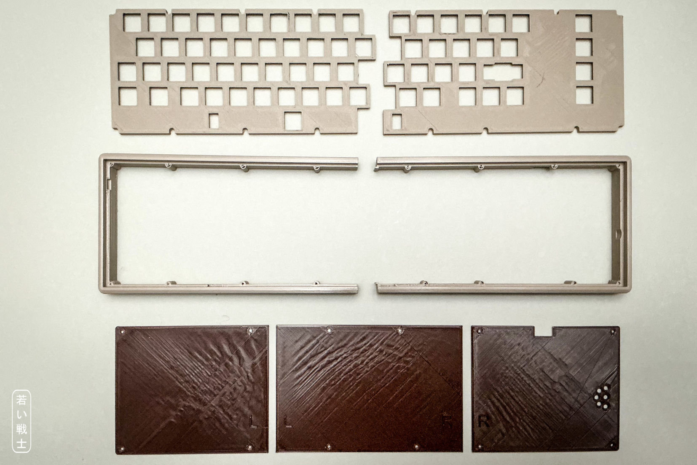
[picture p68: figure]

Figure 9: USB-Keyboard case parts: plate (top), case (mid), bottom (bottom)

It is important that the plates are properly de-burred before installation. They are already slightly wider than the standard dimensions because cutouts tend to be narrower than designed when 3D printed.

Failing to de-burr the plates can result in excessive force being required to install the switches, switches not seating properly—especially when using hot-swap sockets—and damage to the hot-swap sockets. I have experienced the latter myself.

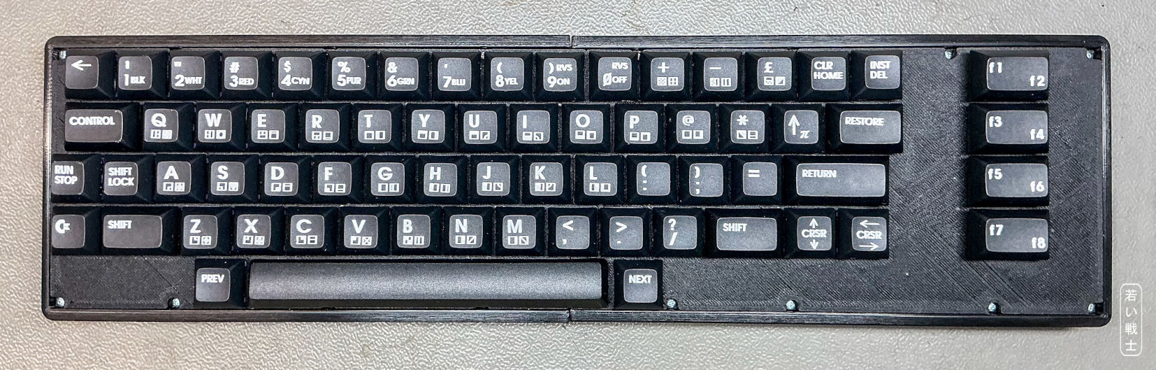
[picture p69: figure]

Figure 10: USB keyboard case with DIY keycaps (UV-decals)

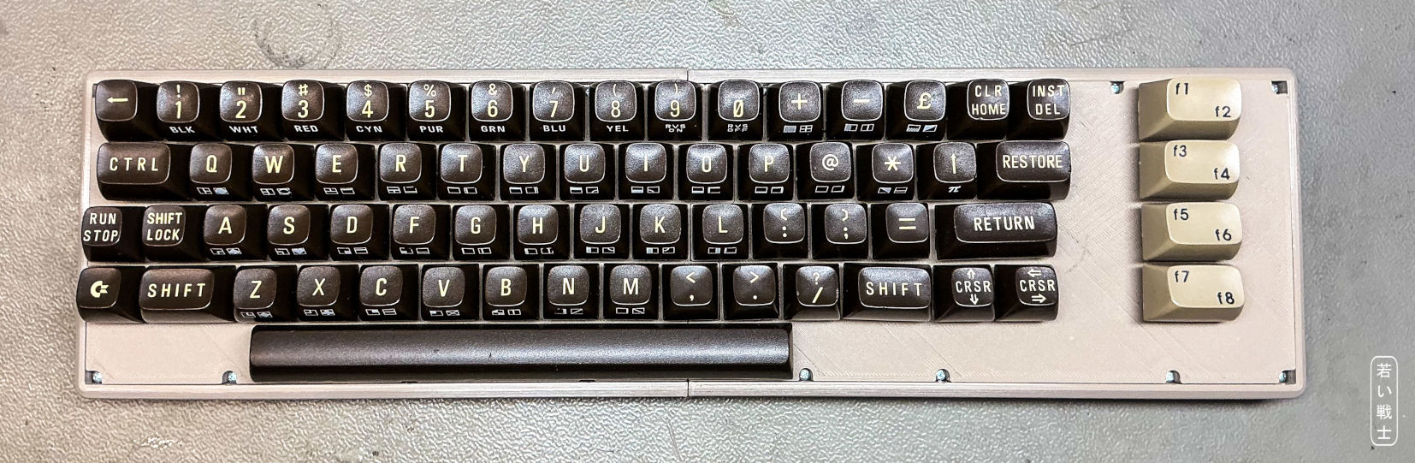
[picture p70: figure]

Figure 11: USB keyboard case with original keycaps

The plates would also fit with the mounting frame, if desired. They are made for PCB Rev. 1 and 2. They are using the same mounting holes of the PCB like the stiffener (plus holes added in PCB Rev. 1).

C64KB_3D_ModD.docx 31.08.2026 16:52 Drafted by Sven Petersen Page 2 of 2 Doc.-No.: 229-6-01-00

C64KB_3D_ModD.docx 31.08.2026 16:52 Drafted by Sven Petersen Page 1 of 1 Doc.-No.: 000-6-00-00

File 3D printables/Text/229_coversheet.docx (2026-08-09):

Project Documentation

C64 Keyboard 3D printables

Project number: 229

Revision: 1

Date: 09.08.2026

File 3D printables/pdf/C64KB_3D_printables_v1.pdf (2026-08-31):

# Project Documentation

## C64 Keyboard 3D printables

## Project number: 229

## Revision: 1

## Date: 09.08.2026

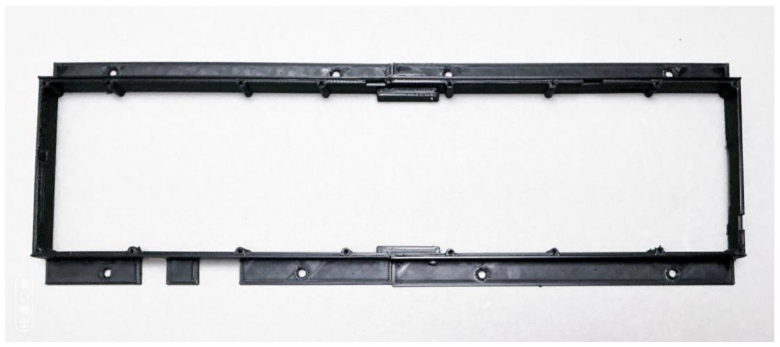
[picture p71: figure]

C64KB_3D_ModD.docx | | 31.08.2026 16:52
Drafted by Sven Petersen | Page 1 of 6 | Doc.-No.: 000-6-00-00

### C64 Mechanical Keyboard & Kernal Switcher

### 3D Printables

### Module Description

## 1. Introduction

The C64 Keyboard PCB requires either a mounting frame for installation in a C64 or C64C case, or a USB keyboard case. All parts were designed to fit on a 3D printer with a 25 cm-wide print bed.

The mounting frame has been tested with various cases, including the C64 Breadbin, different C64C cases, and the C64C clip case.

There are two different versions of the C64 USB keyboard:

- Classic: For use with original keycaps and a classic 9U space bar.
- Modern: For use with modern keycaps, including DIY and Blingboard64/C64U keycaps.

The difference between the two versions is the plates.

## 2. The Mounting Frame

The mounting frame is attached to the C64 Keyboard PCB using 16 C 2.2 × 6.5 H DIN 7981 self-tapping sheet-metal screws.

Figure 1: Mounting frame (Rev. 1)

For PCB Rev. 0, a Rev. 0 mounting frame is required. For PCB Rev. 1 and Rev. 2, a Rev. 1 mounting frame is required. The difference is that the Rev. 1 mounting frame supports a 9U stabilizer, which requires one of the mounting screws to be moved a few millimeters to the right.

A stiffener is an optional part used to increase the rigidity of the PCB. It is attached to the keyboard using 9 C 2.2 × 6.5 H DIN 7981 self-tapping sheet-metal screws (Figure 4). In my experience, the stiffener is not required. It is identical for all PCB revisions.

There are two additional C 2.9 × 9.5 H DIN 7981 screws that hold the two sides of the frame together. They are installed approximately in the middle of the north and south sides, as shown in Figure 2.

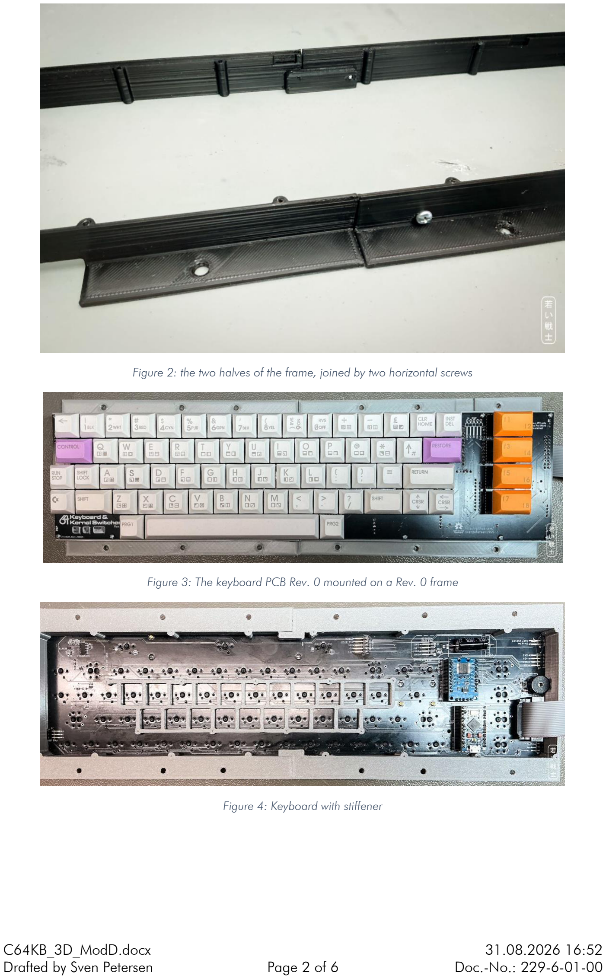
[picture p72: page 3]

Drafted by Sven Petersen | Page 2 of 6 | Doc.-No.: 229-6-01-00

Figure 2: the two halves of the frame, joined by two horizontal screws

Figure 3: The keyboard PCB Rev. 0 mounted on a Rev. 0 frame

Figure 4: Keyboard with stiffener

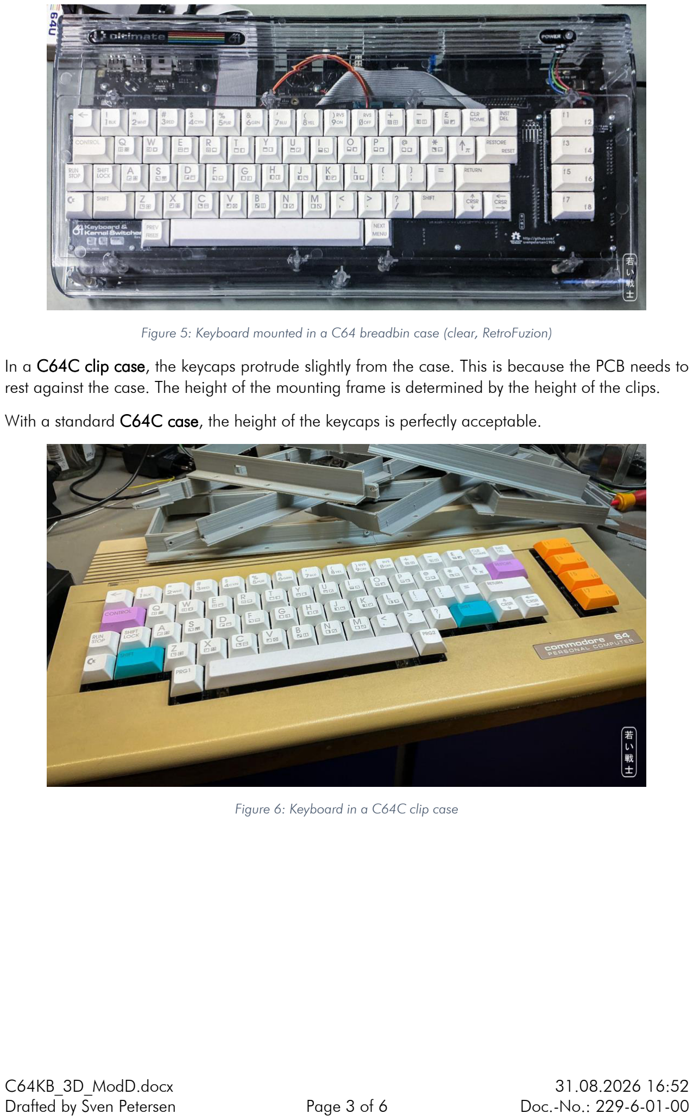
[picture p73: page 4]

Drafted by Sven Petersen | Page 3 of 6 | Doc.-No.: 229-6-01-00

Figure 5: Keyboard mounted in a C64 breadbin case (clear, RetroFuzion)

In a C64C clip case, the keycaps protrude slightly from the case. This is because the PCB needs to rest against the case. The height of the mounting frame is determined by the height of the clips.

With a standard C64C case, the height of the keycaps is perfectly acceptable.

Figure 6: Keyboard in a C64C clip case

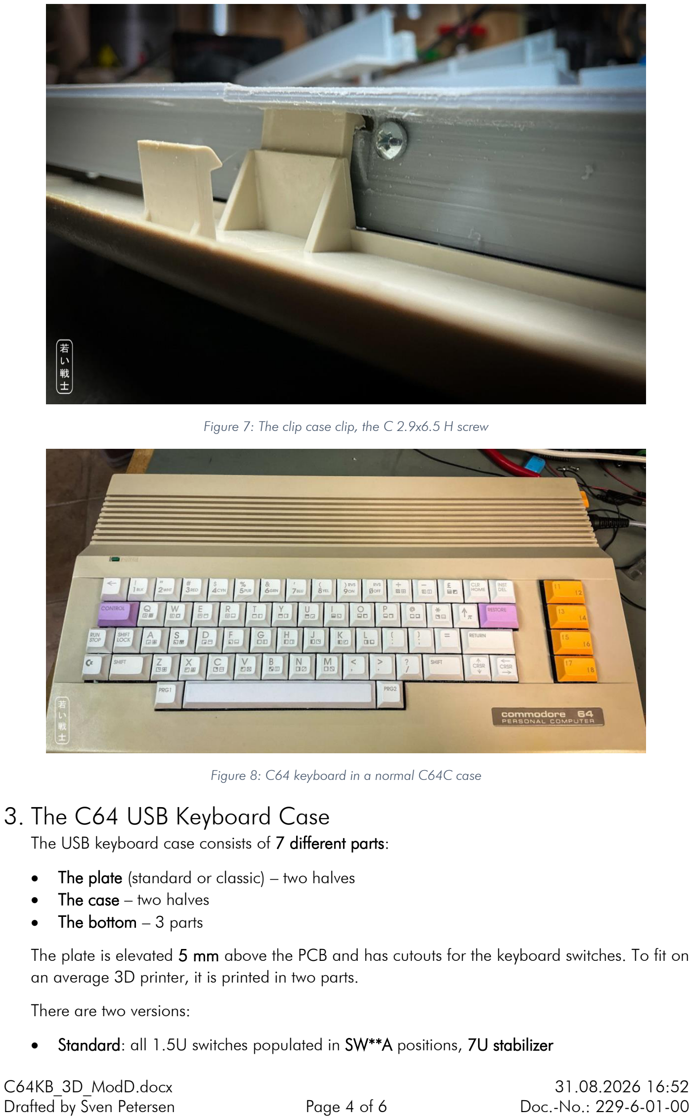
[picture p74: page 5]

Drafted by Sven Petersen | Page 4 of 6 | Doc.-No.: 229-6-01-00

Figure 7: The clip case clip, the C 2.9x6.5 H screw

Figure 8: C64 keyboard in a normal C64C case

## 3. The C64 USB Keyboard Case

The USB keyboard case consists of 7 different parts:

- The plate (standard or classic) – two halves
- The case – two halves
- The bottom – 3 parts

The plate is elevated 5 mm above the PCB and has cutouts for the keyboard switches. To fit on an average 3D printer, it is printed in two parts.

There are two versions:

- Standard: all 1.5U switches populated in SW**A positions, 7U stabilizer

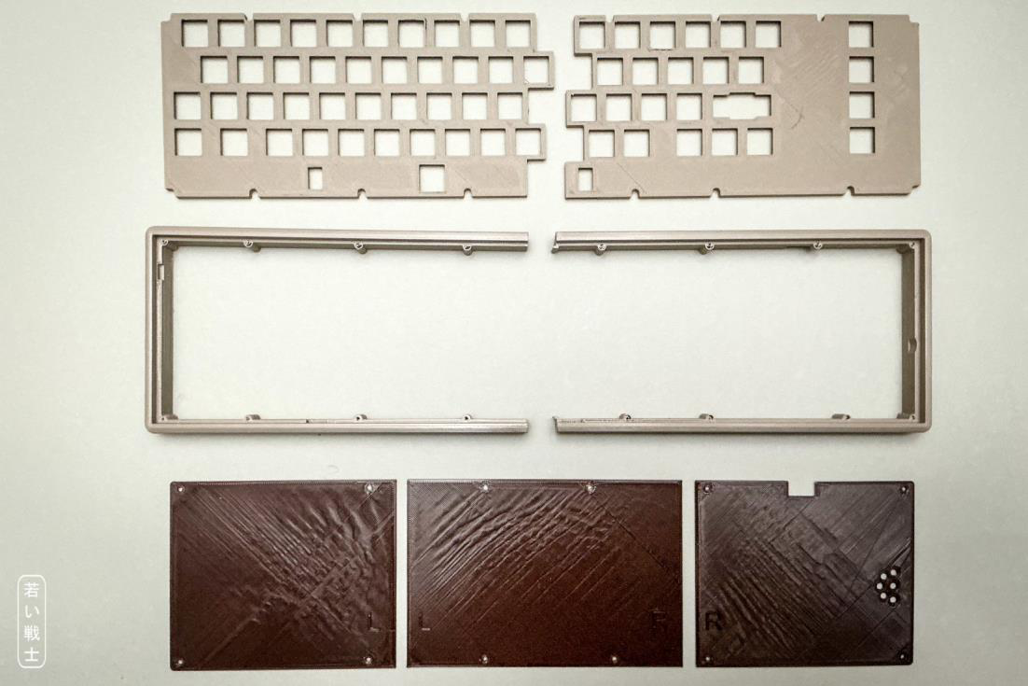
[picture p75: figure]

Drafted by Sven Petersen | Page 5 of 6 | Doc.-No.: 229-6-01-00
- Classic: all 1.5U switches populated in SW** positions, 9U stabilizer

The case is divided into two halves for the same reason: to fit on a standard 3D printer.

The bottom is divided into three parts. The middle part spans over both case halves to add some stability.

The USB keyboard case requires 42 C 2.2 × 6.5 H DIN 7981 self-tapping sheet-metal screws:

- 16 for the PCB
- 14 for the plate
- 12 for the bottom

Figure 9: USB-Keyboard case parts: plate (top), case (mid), bottom (bottom)

It is important that the plates are properly de-burred before installation. They are already slightly wider than the standard dimensions because cutouts tend to be narrower than designed when 3D printed.

Failing to de-burr the plates can result in excessive force being required to install the switches, switches not seating properly—especially when using hot-swap sockets—and damage to the hot-swap sockets. I have experienced the latter myself.

Figure 10: USB keyboard case with DIY keycaps (UV-decals)


Drafted by Sven Petersen | Page 6 of 6 | Doc.-No.: 229-6-01-00

Figure 11: USB keyboard case with original keycaps

The plates would also fit with the mounting frame, if desired. They are made for PCB Rev. 1 and 2. They are using the same mounting holes of the PCB like the stiffener (plus holes added in PCB Rev. 1).

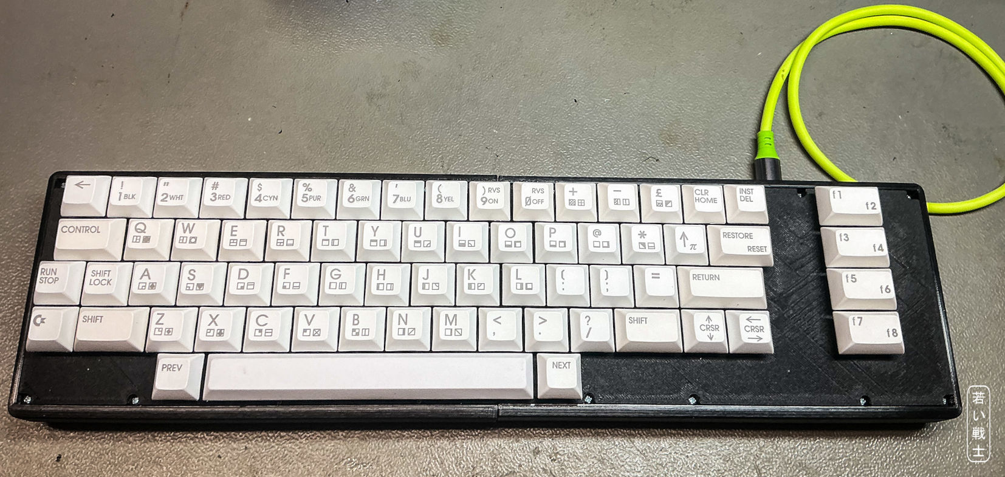
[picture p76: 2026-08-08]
3D printables/pictures/4571_-_USB_case_mounted_top.JPG

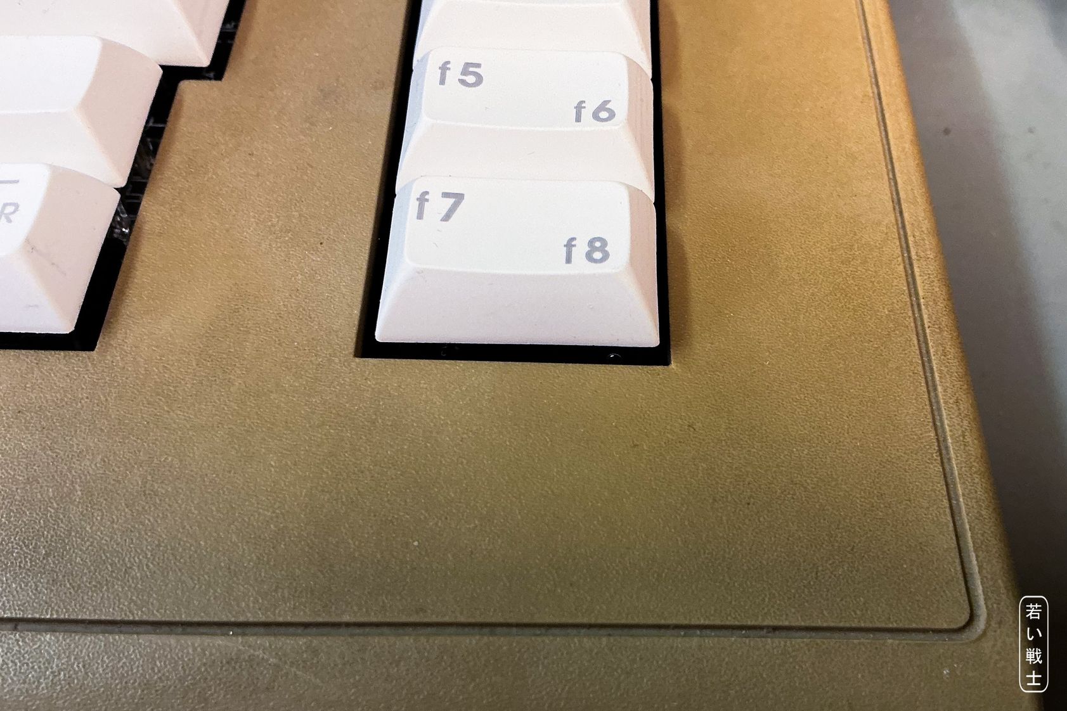
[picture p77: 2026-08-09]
C64 Keyboard Standard Version/Rev. 0/pictures/0297_-_kb_installed_f-keys.JPG

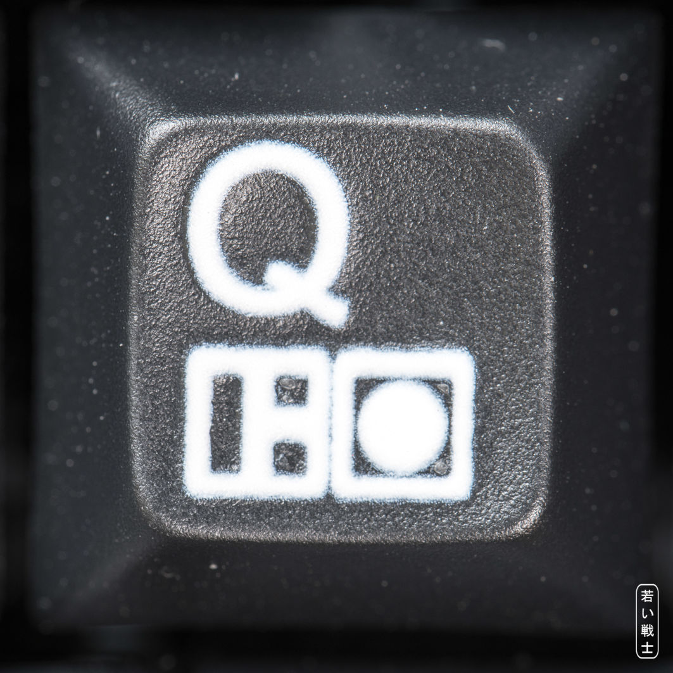
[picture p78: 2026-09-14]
Keycaps/pictures/6061_-_UV_print_white_Q.JPG

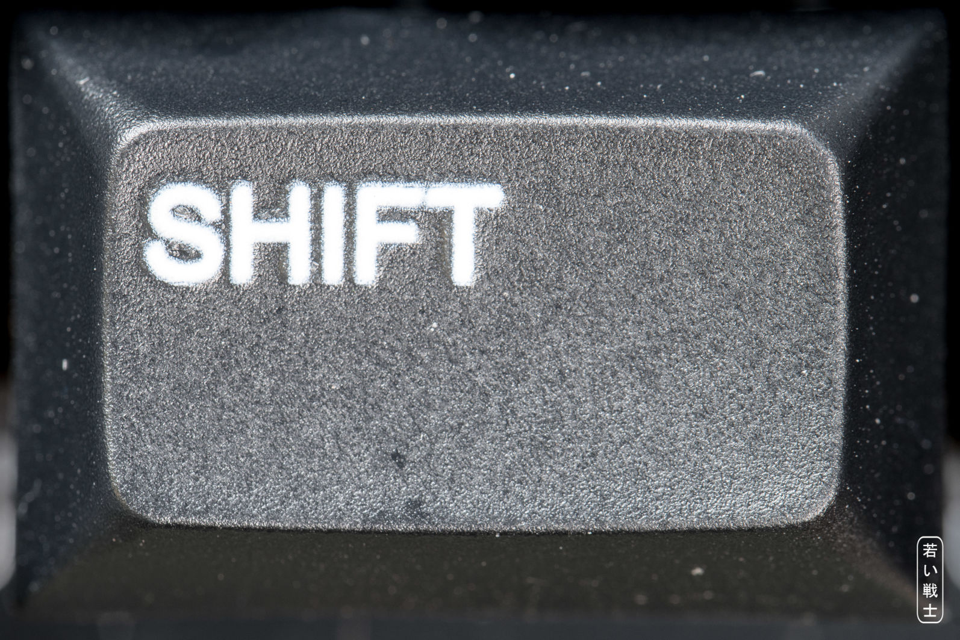
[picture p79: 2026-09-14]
Keycaps/pictures/6063_-_UV_print_white_SHIFT.JPG

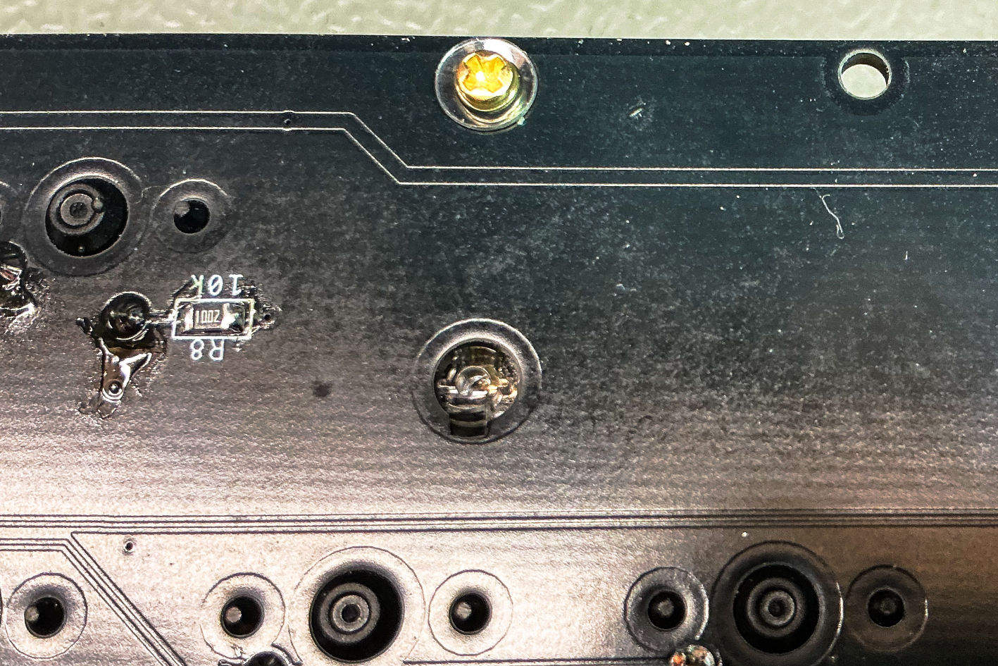
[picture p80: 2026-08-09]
C64 Keyboard Standard Version/Rev. 0/pictures/0274_-_szabilizer_installation_bottom.JPG

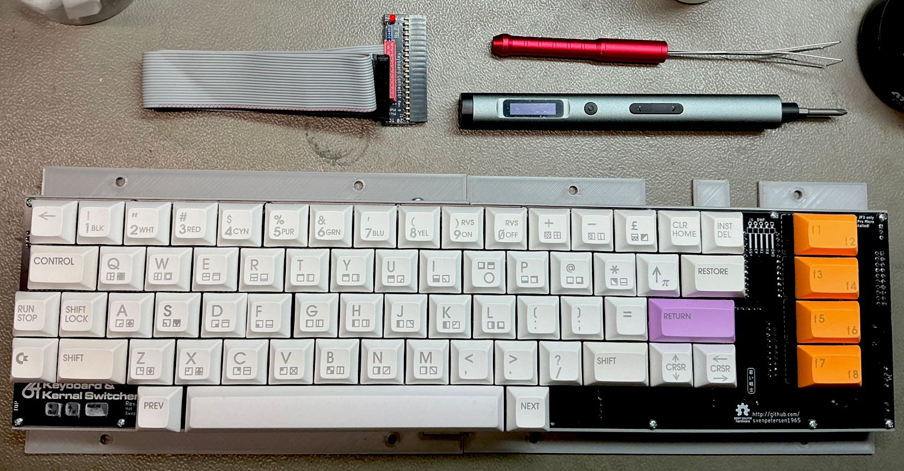
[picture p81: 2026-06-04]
pictures/3992_-_full_assembly_w_keycaps.JPG

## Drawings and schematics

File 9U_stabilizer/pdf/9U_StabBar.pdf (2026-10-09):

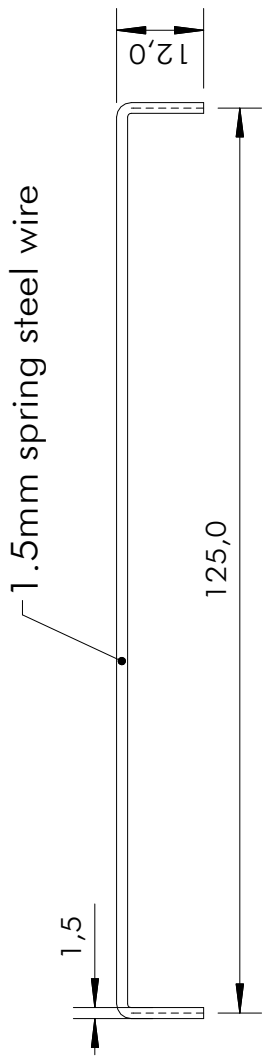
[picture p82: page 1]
Rev.: 0; 1 File:; Title:; Doc.-No.: 232-3-01-00; Date: 09.10.2026 18:36; 9U_StabBar.skf; C64 Keyboard; 9U Stabilizer Bar

Draft.: Sven Petersen

https://github.com/svenpetersen1965

1.5mm spring steel wire

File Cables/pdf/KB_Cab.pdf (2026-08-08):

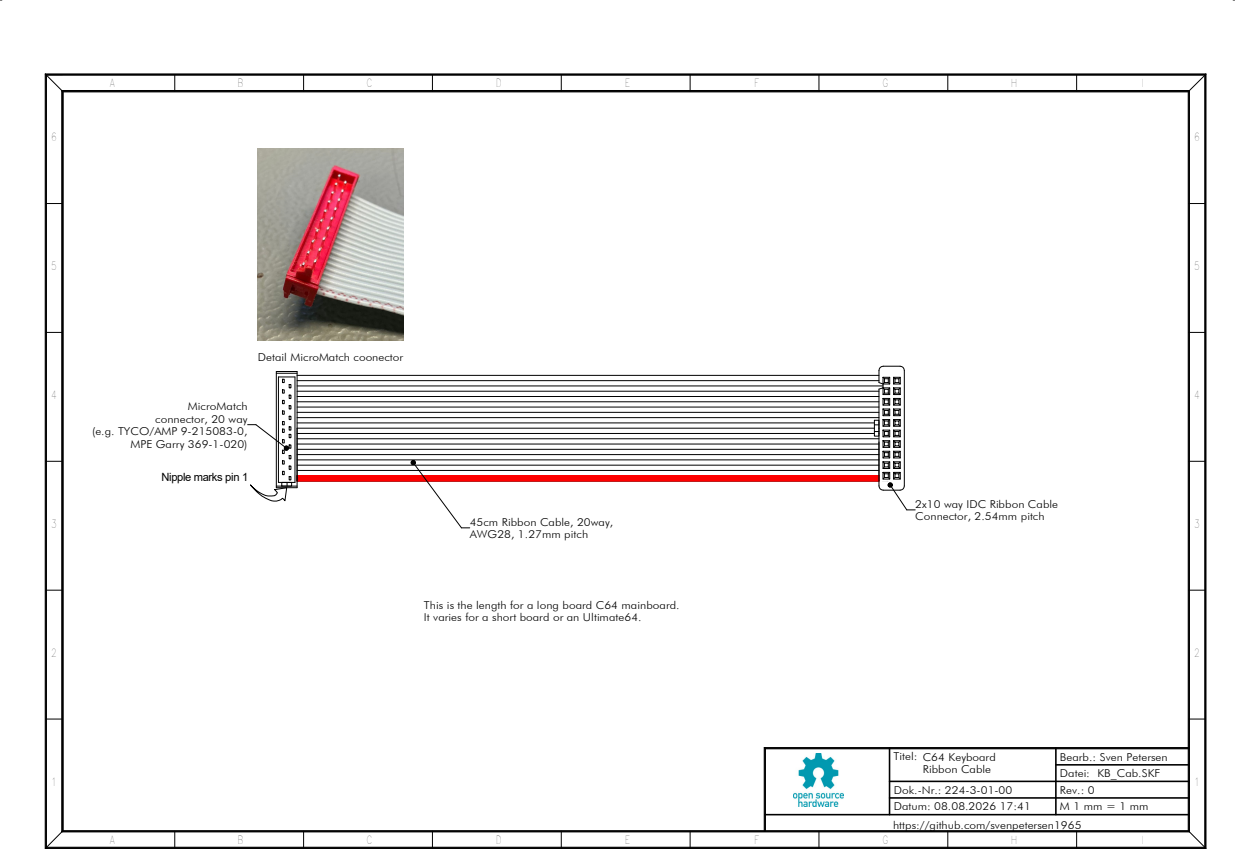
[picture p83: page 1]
Ribbon Cable; KB_Cab.SKF; MicroMatch connector, 20 way (e.g. TYCO/AMP 9-215083-0, MPE Garry 369-1-020); 45cm Ribbon Cable, 20way, AWG28, 1.27mm pitch

Detail MicroMatch coonector

Nipple marks pin 1

2x10 way IDC Ribbon Cable
Connector, 2.54mm pitch

This is the length for a long board C64 mainboard.
It varies for a short board or an Ultimate64.

Titel:
C64 Keyboard
Dok.-Nr.: 224-3-01-00
Datum: 08.08.2026 17:41
https://github.com/svenpetersen1965

Bearb.: Sven Petersen
Datei:
Rev.: 0

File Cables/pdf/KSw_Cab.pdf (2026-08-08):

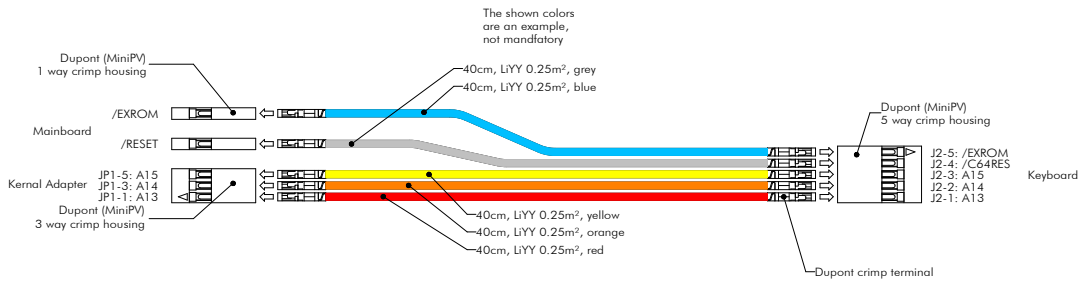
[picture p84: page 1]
Title:; Doc.-No.: 223-3-01-00; Date: 08.08.2026 17:35; J2-5: /EXROM J2-4: /C64RES J2-3: A15 J2-2: A14 J2-1: A13; 40cm, LiYY 0.25m², yellow; 40cm, LiYY 0.25m², orange; 40cm, LiYY 0.25m², red; 40cm, LiYY 0.25m², blue; 40cm, LiYY 0.25m², grey; /EXROM; /RESET; Kernal Adapter; Mainboard; Keyboard; KSw_Cab.skf

The shown colors
are an example,
not mandfatory

Dupont (MiniPV)
1 way crimp housing

5 way crimp housing

3 way crimp housing

Dupont crimp terminal

C64 Keyboard
Kernal Switch Cable

Draft.: Sven Petersen
File:
Rev.: 0

https://github.com/svenpetersen1965

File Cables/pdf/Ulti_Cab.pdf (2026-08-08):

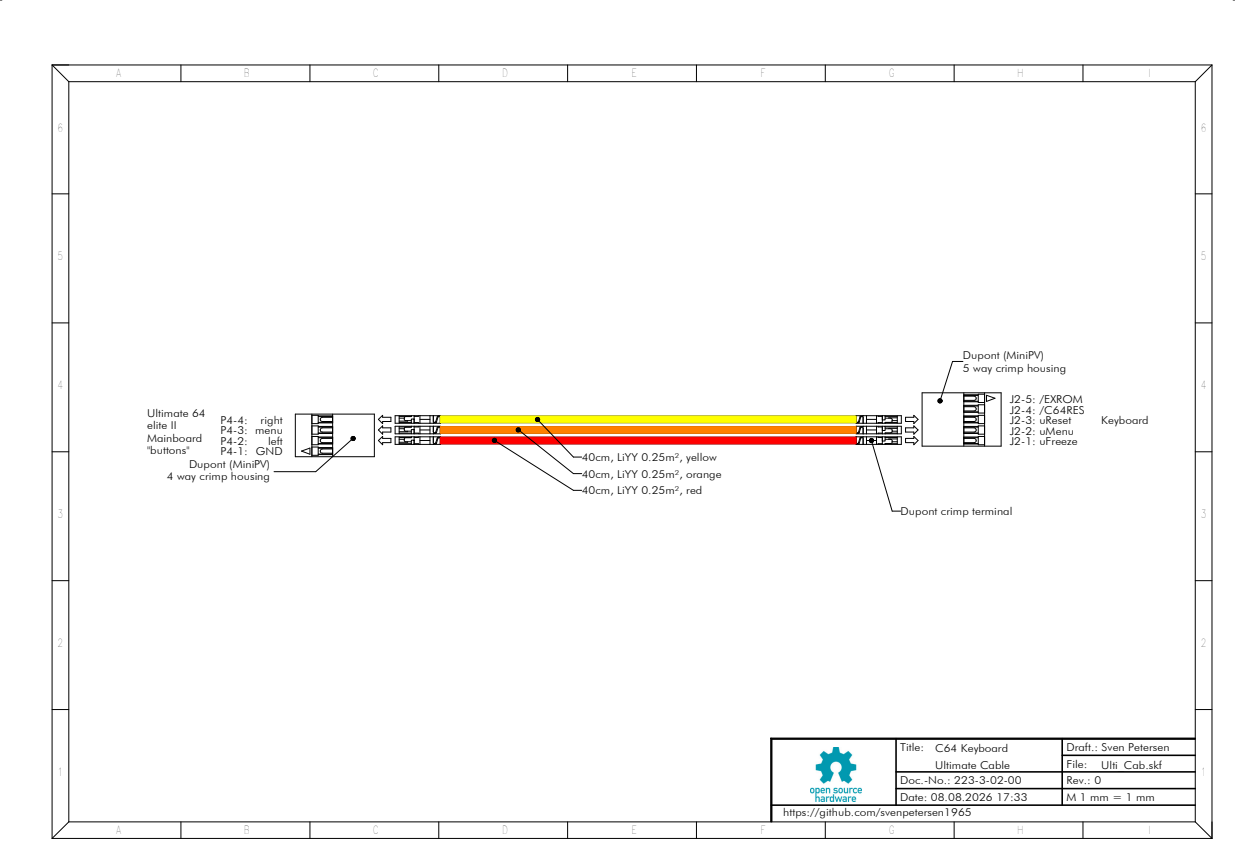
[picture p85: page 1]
Title:; Doc.-No.: 223-3-02-00; Date: 08.08.2026 17:33; J2-5: /EXROM J2-4: /C64RES J2-3: uReset J2-2: uMenu J2-1: uFreeze; Dupont (MiniPV) 4 way crimp housing; 40cm, LiYY 0.25m², yellow; 40cm, LiYY 0.25m², orange; 40cm, LiYY 0.25m², red; GND; left; menu; Keyboard; Ulti_Cab.skf; C64 Keyboard; Ultimate Cable; Ultimate 64 elite II Mainboard "buttons"; right

Dupont (MiniPV)
5 way crimp housing

Dupont crimp terminal

Draft.: Sven Petersen
File:
Rev.: 0

https://github.com/svenpetersen1965

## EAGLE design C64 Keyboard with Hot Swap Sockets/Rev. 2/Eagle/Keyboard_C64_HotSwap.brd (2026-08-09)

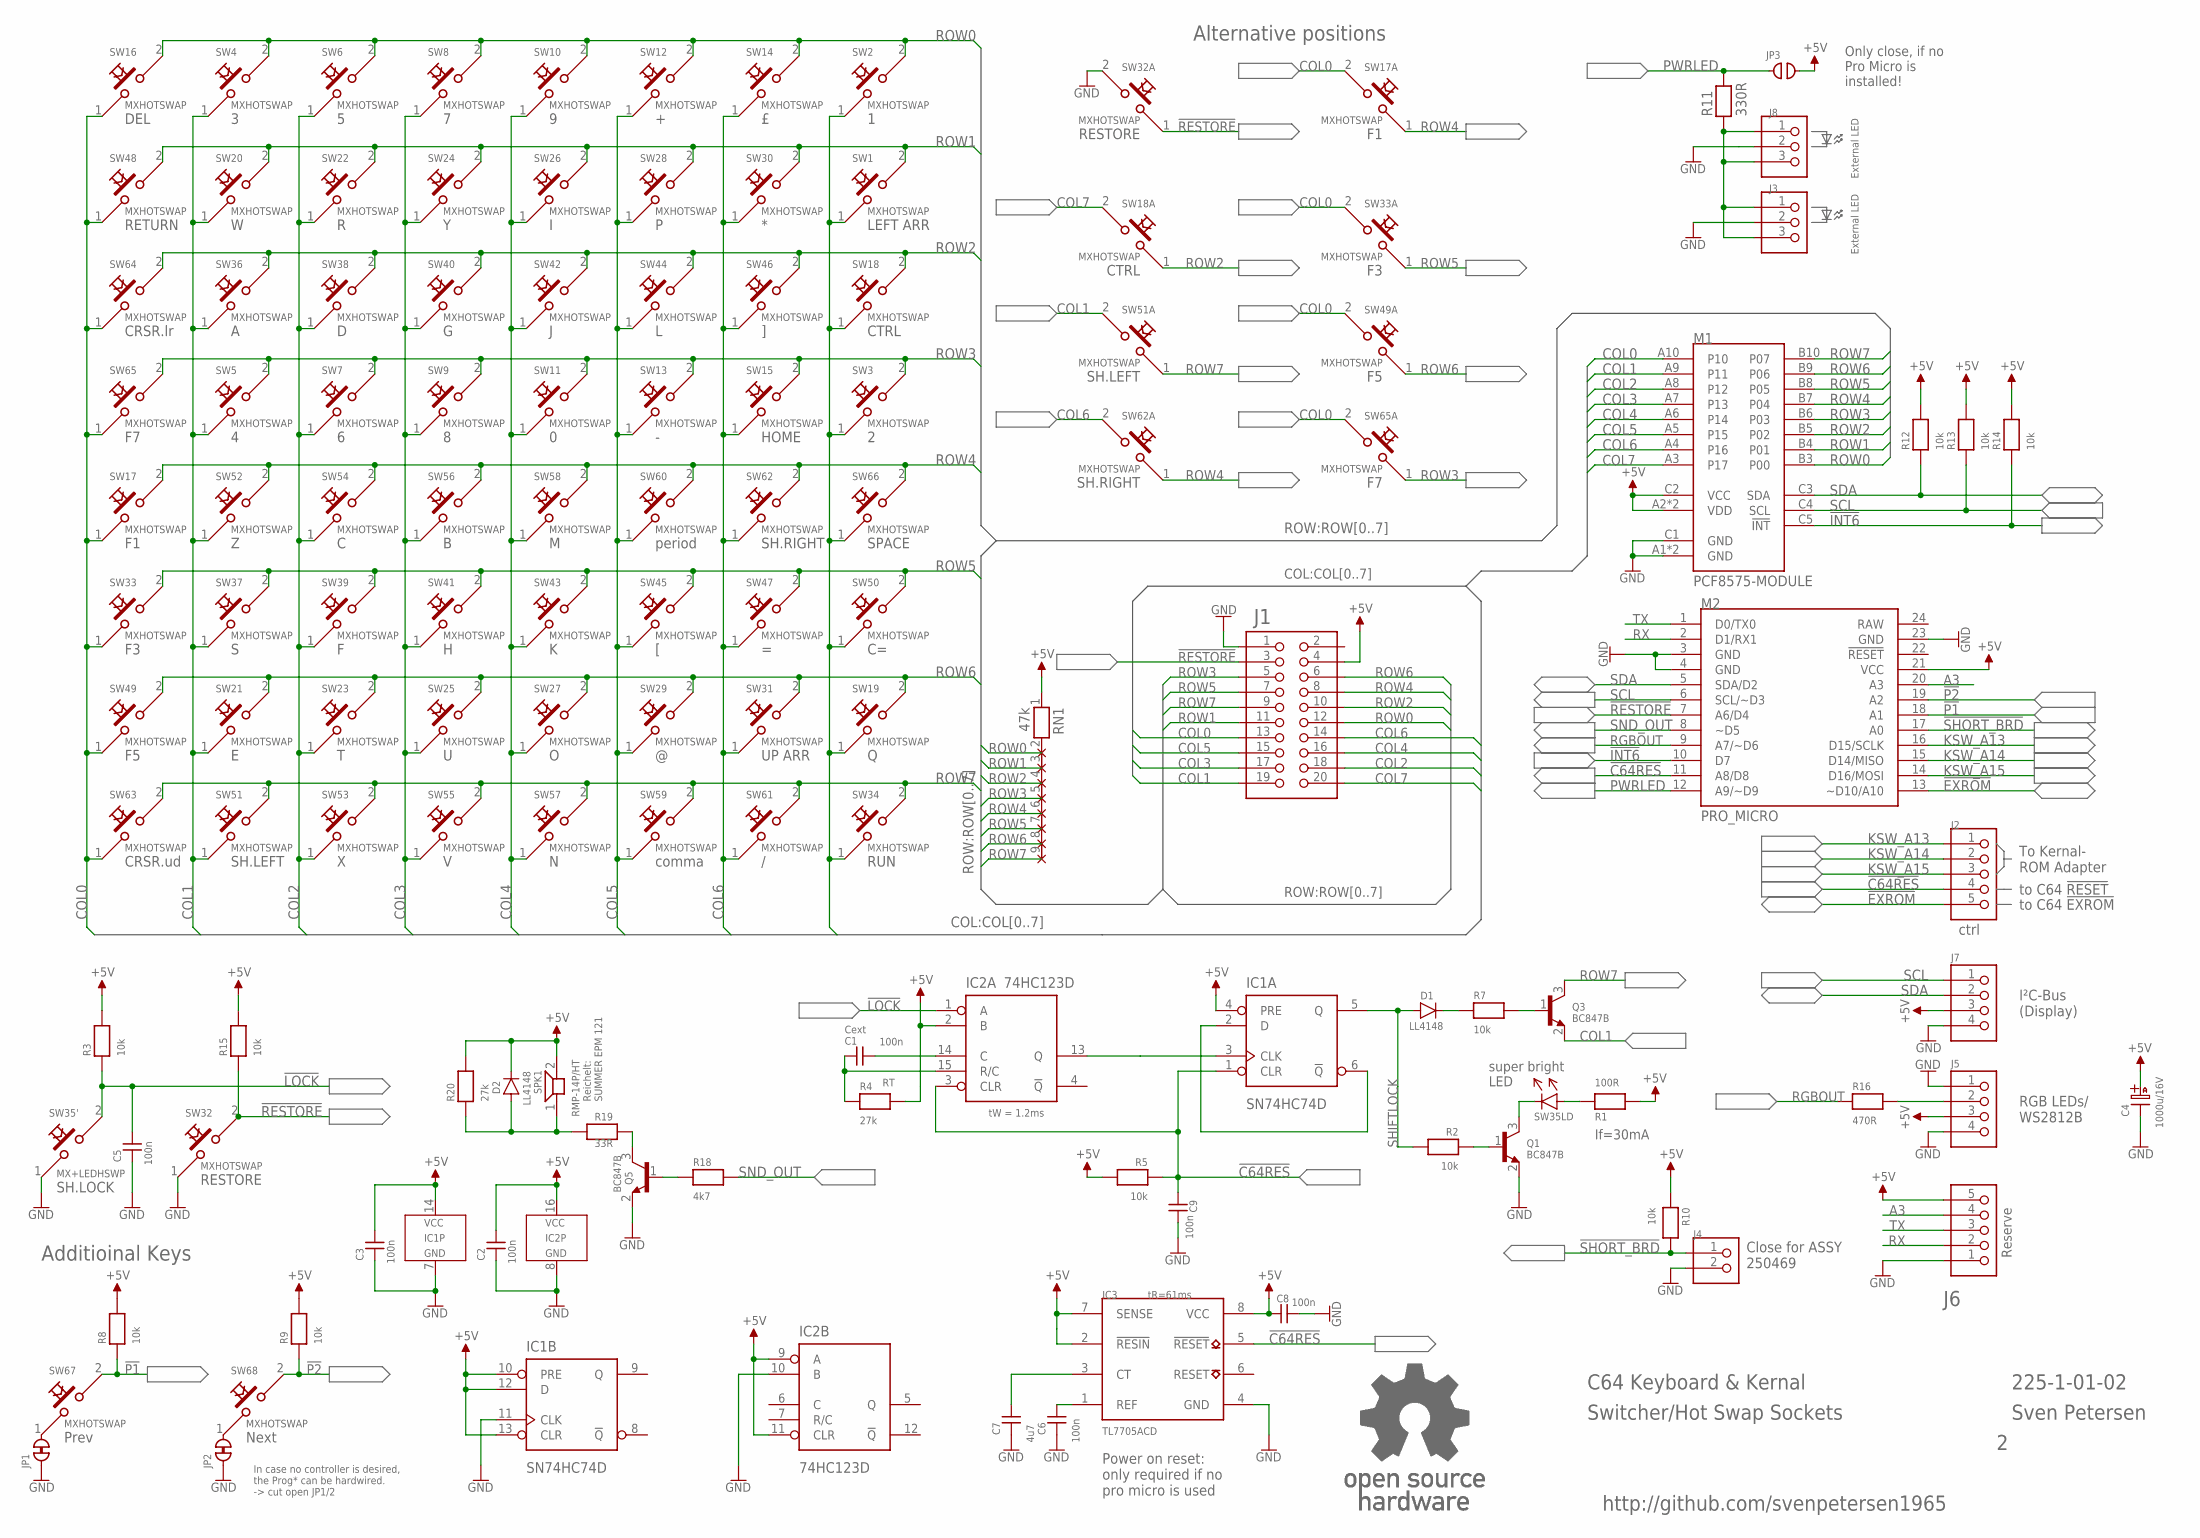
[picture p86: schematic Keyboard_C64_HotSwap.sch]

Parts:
C1, C2, C3, C5, C6, C8, C9: 100n; 0805
C4: 1000u/16V; C30X16L
C7: 4u7; 0805
D1, D2: LL4148; SOD80C
IC1: SN74HC74D; SO-14
IC2: 74HC123D; SO-16
IC3: TL7705ACD; SO8
J1: PINHD-2X10WH; 2X10WH
J2, J6: PINHD-1X590°; 1X05/90
J3, J8: PINHD-1X3/90; 1X03/90
J4: PINHD-1X2/90; 1X02/90
J5, J7: PINHD-1X4/90; 1X04/90
JP1, JP2: CLOSED; CP_CL
JP3: OPEN; CP_OP
M1: PCF8575-MODULE; PCF8575MODUL
M2: PRO_MICRO
Q1, Q3, Q5: BC847B; SOT23
R1: 100R; 0805
R2, R3, R5, R7, R8, R9, R10, R12, R13, R14, R15: 10k; 0805
R4, R20: 27k; 0805
R11: 330R; 0805
R16: 470R; 0805
R18: 4k7; 0805
R19: 33R; 0805
RN1: 47k; RN-9
SPK1: RMP-14P/HT
SW1, SW2, SW3, SW4, SW5, SW6, SW7, SW8, SW9, SW10, SW11, SW12, SW13, SW14, SW15, SW16, SW17, SW17A, SW18, SW18A, SW19, SW20, SW21, SW22, SW23, SW24, SW25, SW26, SW27, SW28, SW29, SW30, SW31, SW32, SW32A, SW33, SW33A, SW34, SW36, SW37, SW38, SW39, SW40, SW41, SW42, SW43, SW44, SW45, SW46, SW47, SW48, SW49, SW49A, SW50, SW51, SW51A, SW52, SW53, SW54, SW55, SW56, SW57, SW58, SW59, SW60, SW61, SW62, SW62A, SW63, SW64, SW65, SW65A, SW66, SW67, SW68: MXHOTSWAP; CHERRYMX_HOTSWAP
SW35: MX+LEDHSWP; CHERRYMX_HSWP_LD
U$90: OPEN_SOURCE_HW; OPENHW

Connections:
!C64RES: C9.1, IC1.1 (CLR), IC2.3 (CLR), IC3.5 (!RESET), J2.4, M2.11 (A8/D8), R5.1
!EXROM: J2.5, M2.13 (~D10/A10)
!INT6: M1.C5 (!INT), M2.10 (D7), R14.1
!LOCK: C5.2, IC2.1 (A), R3.1, SW35.2
!P1: M2.18 (A1), R8.1, SW67.2
!P2: M2.19 (A2), R9.1, SW68.2
!RESTORE: J1.3, M2.7 (A6/D4), R15.1, SW32.2, SW32A.1
!SHORT_BRD: J4.1, M2.17 (A0), R10.2
+5V: C2.2, C3.2, C4.A (+), D2.K, IC1.4 (PRE), IC1.10 (PRE), IC1.12 (D), IC1.13 (CLR), IC1.14 (VCC), IC2.2 (B), IC2.9 (A), IC2.11 (CLR), IC2.16 (VCC), IC3.2 (!RESIN), IC3.7 (SENSE), J1.4, J5.3, J6.5, J7.3, JP3.2, M1.A2 (VDD), M1.B2 (VDD), M1.C2 (VCC), M2.21 (VCC), R1.2, R3.2, R4.2, R5.2, R8.2, R9.2, R10.1, R12.2, R13.2, R14.2, R15.2, R20.2, RN1.1, SPK1.2
A3: J6.4, M2.20 (A3)
COL0: J1.13, M1.A10 (P10), SW16.1, SW17.1, SW17A.2, SW33.1, SW33A.2, SW48.1, SW49.1, SW49A.2, SW63.1, SW64.1, SW65.1, SW65A.2
COL1: J1.19, M1.A9 (P11), Q3.2 (E), SW4.1, SW5.1, SW20.1, SW21.1, SW36.1, SW37.1, SW51.1, SW51A.2, SW52.1
COL2: J1.18, M1.A8 (P12), SW6.1, SW7.1, SW22.1, SW23.1, SW38.1, SW39.1, SW53.1, SW54.1
COL3: J1.17, M1.A7 (P13), SW8.1, SW9.1, SW24.1, SW25.1, SW40.1, SW41.1, SW55.1, SW56.1
COL4: J1.16, M1.A6 (P14), SW10.1, SW11.1, SW26.1, SW27.1, SW42.1, SW43.1, SW57.1, SW58.1
COL5: J1.15, M1.A5 (P15), SW12.1, SW13.1, SW28.1, SW29.1, SW44.1, SW45.1, SW59.1, SW60.1
COL6: J1.14, M1.A4 (P16), SW14.1, SW15.1, SW30.1, SW31.1, SW46.1, SW47.1, SW61.1, SW62.1, SW62A.2
COL7: J1.20, M1.A3 (P17), SW1.1, SW2.1, SW3.1, SW18.1, SW18A.2, SW19.1, SW34.1, SW50.1, SW66.1
GND: C2.1, C3.1, C4.K (-), C5.1, C6.1, C7.1, C8.2, C9.2, IC1.7 (GND), IC1.11 (CLK), IC2.8 (GND), IC2.10 (B), IC3.4 (GND), J1.1, J3.2, J4.2, J5.1, J5.4, J6.1, J7.4, J8.2, JP1.1, JP2.1, M1.A1 (GND), M1.B1 (GND), M1.C1 (GND), M2.3 (GND), M2.4 (GND), M2.23 (GND), Q1.2 (E), Q5.2 (E), SW32.1, SW32A.2, SW35.1
KSW_A13: J2.1, M2.16 (D15/SCLK)
KSW_A14: J2.2, M2.15 (D14/MISO)
KSW_A15: J2.3, M2.14 (D16/MOSI)
LOCK: IC1.3 (CLK), IC2.13 (Q)
unnamed: R1.1, SW35.LDA (A)
unnamed: Q1.3 (C), SW35.LDC (K)
unnamed: Q1.1 (B), R2.1
unnamed: C1.2, IC2.14 (C)
unnamed: IC1.2 (D), IC1.6 (!Q)
unnamed: D1.K, R7.1
unnamed: Q3.1 (B), R7.2
unnamed: Q5.1 (B), R18.1
unnamed: J3.1, J3.3, J8.1, J8.3, R11.1
unnamed: Q5.3 (C), R19.2
unnamed: D2.A, R19.1, R20.1, SPK1.1
unnamed: J5.2, R16.2
unnamed: JP1.2, SW67.1
unnamed: JP2.2, SW68.1
unnamed: C1.1, IC2.15 (R/C), R4.1
unnamed: C8.1, IC3.8 (VCC)
unnamed: C6.2, IC3.1 (REF)
unnamed: C7.2, IC3.3 (CT)
PWRLED: JP3.1, M2.12 (A9/~D9), R11.2
RAW: M2.24 (RAW)
RGBOUT: M2.9 (A7/~D6), R16.1
ROW0: J1.12, M1.B3 (P00), RN1.2, SW2.2, SW4.2, SW6.2, SW8.2, SW10.2, SW12.2, SW14.2, SW16.2
ROW1: J1.11, M1.B4 (P01), RN1.3, SW1.2, SW20.2, SW22.2, SW24.2, SW26.2, SW28.2, SW30.2, SW48.2
ROW2: J1.10, M1.B5 (P02), RN1.4, SW18.2, SW18A.1, SW36.2, SW38.2, SW40.2, SW42.2, SW44.2, SW46.2, SW64.2
ROW3: J1.5, M1.B6 (P03), RN1.5, SW3.2, SW5.2, SW7.2, SW9.2, SW11.2, SW13.2, SW15.2, SW65.2, SW65A.1
ROW4: J1.8, M1.B7 (P04), RN1.6, SW17.2, SW17A.1, SW52.2, SW54.2, SW56.2, SW58.2, SW60.2, SW62.2, SW62A.1, SW66.2
ROW5: J1.7, M1.B8 (P05), RN1.7, SW33.2, SW33A.1, SW37.2, SW39.2, SW41.2, SW43.2, SW45.2, SW47.2, SW50.2
ROW6: J1.6, M1.B9 (P06), RN1.8, SW19.2, SW21.2, SW23.2, SW25.2, SW27.2, SW29.2, SW31.2, SW49.2, SW49A.1
ROW7: J1.9, M1.B10 (P07), Q3.3 (C), RN1.9, SW34.2, SW51.2, SW51A.1, SW53.2, SW55.2, SW57.2, SW59.2, SW61.2, SW63.2
RX: J6.2, M2.2 (D1/RX1)
SCL: J7.1, M1.C4 (SCL), M2.6 (SCL/~D3), R13.1
SDA: J7.2, M1.C3 (SDA), M2.5 (SDA/D2), R12.1
SHIFTLOCK: D1.A, IC1.5 (Q), R2.2
SND_OUT: M2.8 (~D5), R18.2
TX: J6.3, M2.1 (D0/TX0)

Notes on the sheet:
Alternative positions
Additioinal Keys
To Kernal- ROM Adapter
to C64 !RESET
Close for ASSY 250469
to C64 !EXROM
ctrl
I²C-Bus (Display)
External LED
Reichelt: SUMMER EPM 121
225-1-01-02
Sven Petersen
C64 Keyboard & Kernal
Switcher/Hot Swap Sockets
http://github.com/svenpetersen1965
RGB LEDs/ WS2812B
In case no controller is desired, the Prog* can be hardwired. -> cut open JP1/2
Reserve
Only close, if no Pro Micro is installed!
super bright LED
If=30mA
Cext
tW = 1.2ms
Power on reset: only required if no pro micro is used
tR=61ms

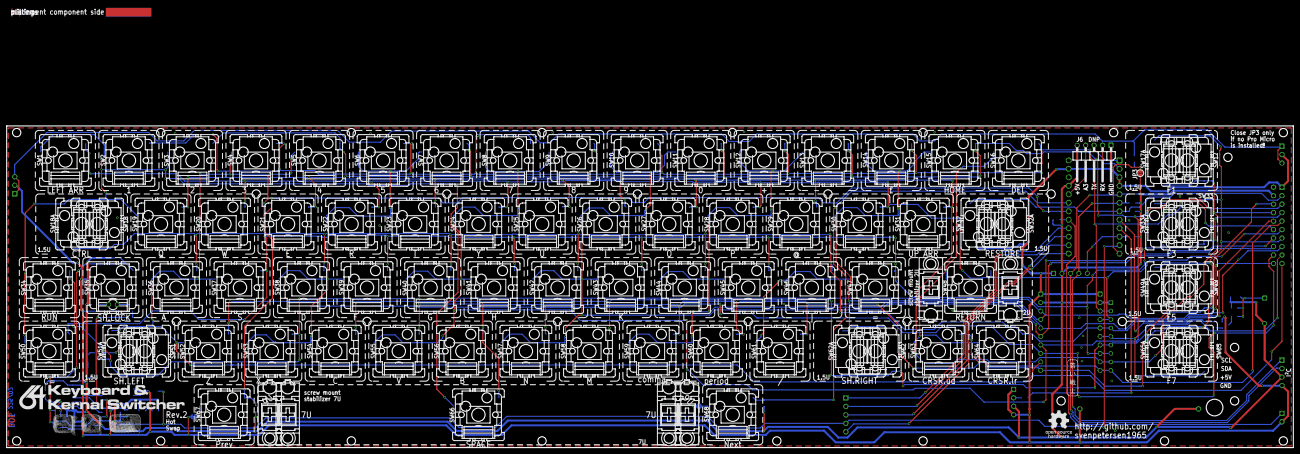
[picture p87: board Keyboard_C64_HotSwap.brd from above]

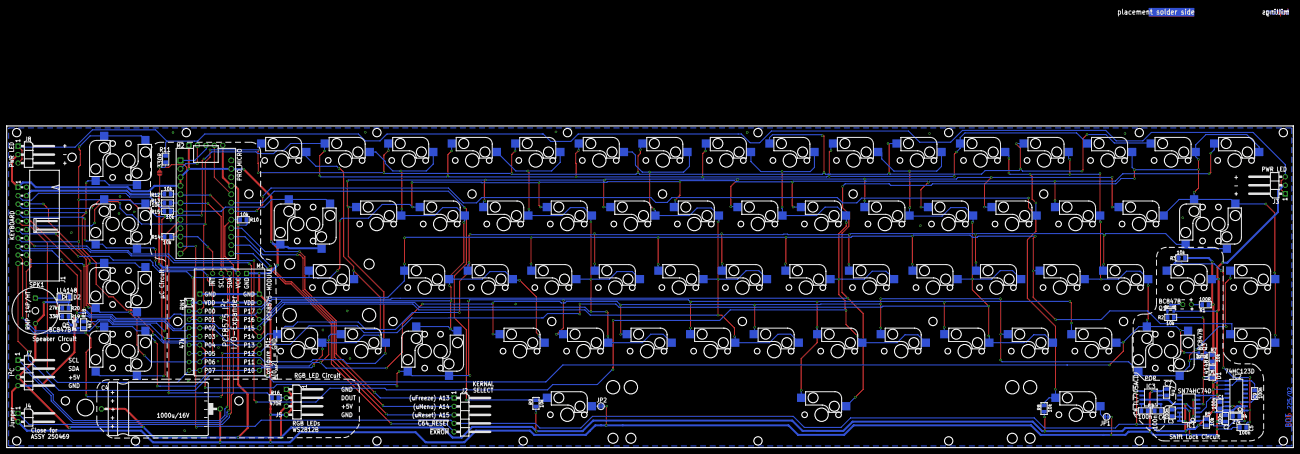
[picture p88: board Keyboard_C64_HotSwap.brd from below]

Board: 2 copper layers, 385.6 x 96.4 mm, 206 parts (48 on the bottom side), 57 nets.

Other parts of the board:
U$92, U$93, U$94, U$95, U$96, U$97, U$98, U$106: KCAP_1_5U
U$99, U$100, U$101, U$102, U$103, U$107, U$108, U$109, U$110, U$111, U$112, U$113, U$114, U$115, U$116, U$117, U$118, U$119, U$120, U$121, U$122, U$123, U$124, U$125, U$126, U$127, U$128, U$129, U$130, U$131, U$132, U$133, U$134, U$135, U$136, U$137, U$138, U$139, U$140, U$141, U$142, U$143, U$144, U$145, U$146, U$147, U$148, U$149, U$150, U$151, U$152, U$153, U$154, U$155, U$156, U$157, U$158, U$159: KCAP_1U
U$104: KCAP_7U
U$105: KCAP_2U
U$161: 2LAYER
U$162: PCB-TITLE/
U$164: C64_KEYS
U$172, U$175, U$181: STABIL_PIN_SCREW_L
U$173, U$174, U$180: STABIL_PIN_SCREW
U$176: 64KB
U$178: SVEN_TAG

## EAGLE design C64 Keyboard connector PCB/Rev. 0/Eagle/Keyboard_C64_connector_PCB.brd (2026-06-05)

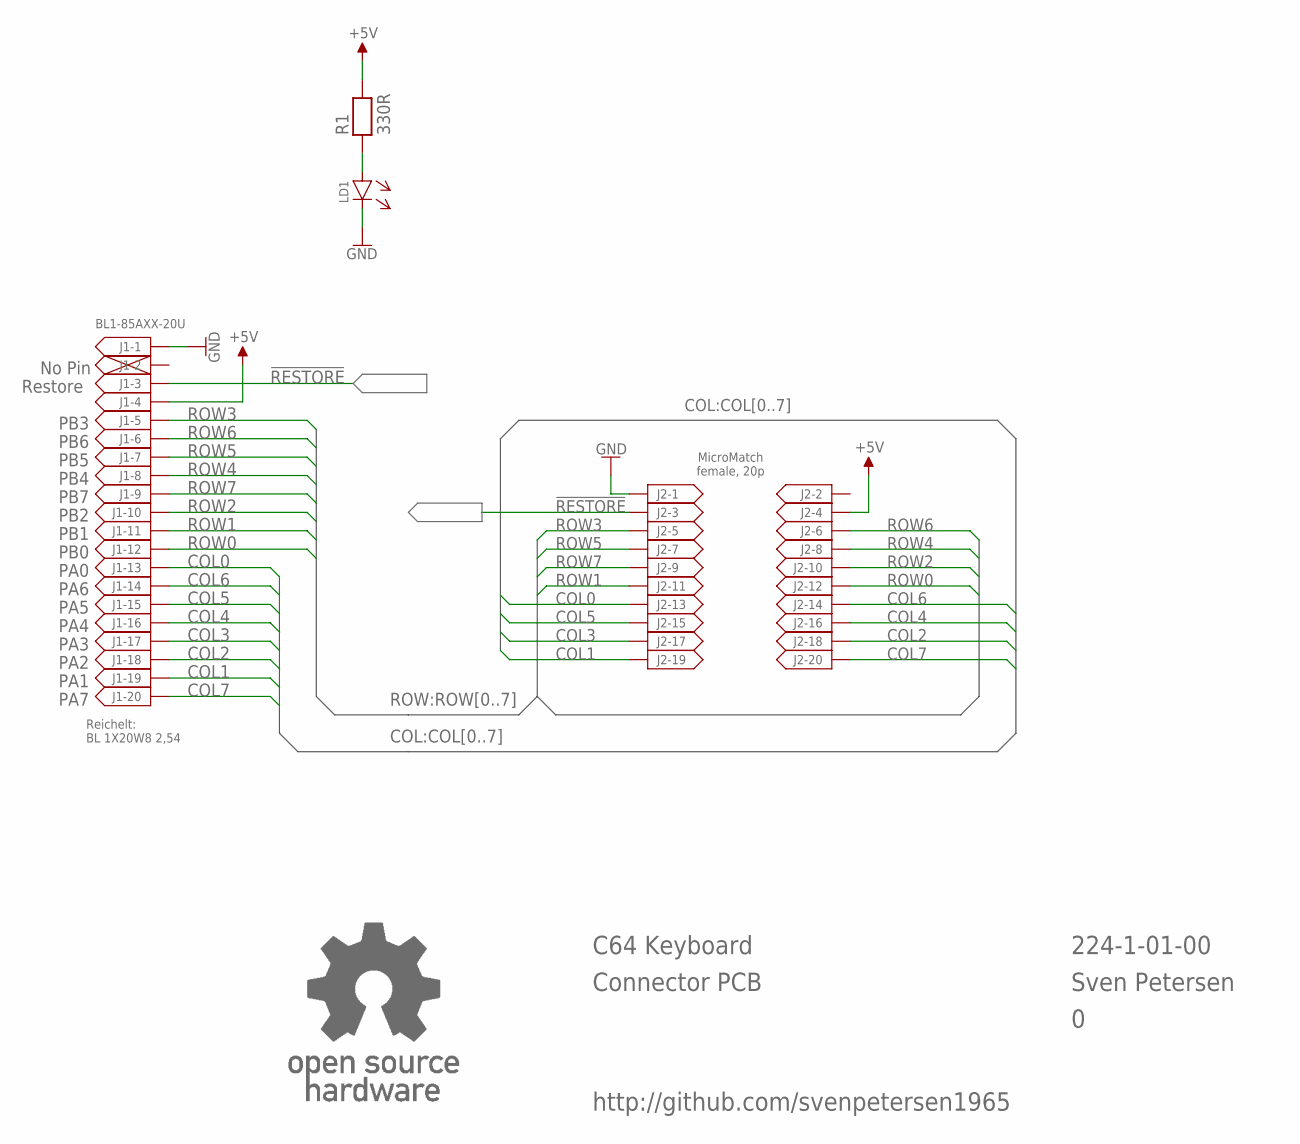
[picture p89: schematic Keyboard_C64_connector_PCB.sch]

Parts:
J1: BL1-85AXX-20U
J2: MICMA20B
LD1: 3MM
R1: 330R; R-10
U$9: OPEN_SOURCE_HW; OPENHW

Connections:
!RESTORE: J1.3, J2.3
+5V: J1.4, J2.4, R1.2
COL0: J1.13, J2.13
COL1: J1.19, J2.19
COL2: J1.18, J2.18
COL3: J1.17, J2.17
COL4: J1.16, J2.16
COL5: J1.15, J2.15
COL6: J1.14, J2.14
COL7: J1.20, J2.20
GND: J1.1, J2.1, LD1.C (K)
unnamed: LD1.A, R1.1
ROW0: J1.12, J2.12
ROW1: J1.11, J2.11
ROW2: J1.10, J2.10
ROW3: J1.5, J2.5
ROW4: J1.8, J2.8
ROW5: J1.7, J2.7
ROW6: J1.6, J2.6
ROW7: J1.9, J2.9

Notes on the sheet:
PB3
PB6
PB5
PB4
PB7
PB2
PB1
PB0
PA0
PA6
PA5
PA4
PA3
PA2
PA1
PA7
No Pin
Restore
C64 Keyboard
Connector PCB
224-1-01-00
Sven Petersen
Reichelt: BL 1X20W8 2,54
http://github.com/svenpetersen1965
MicroMatch female, 20p

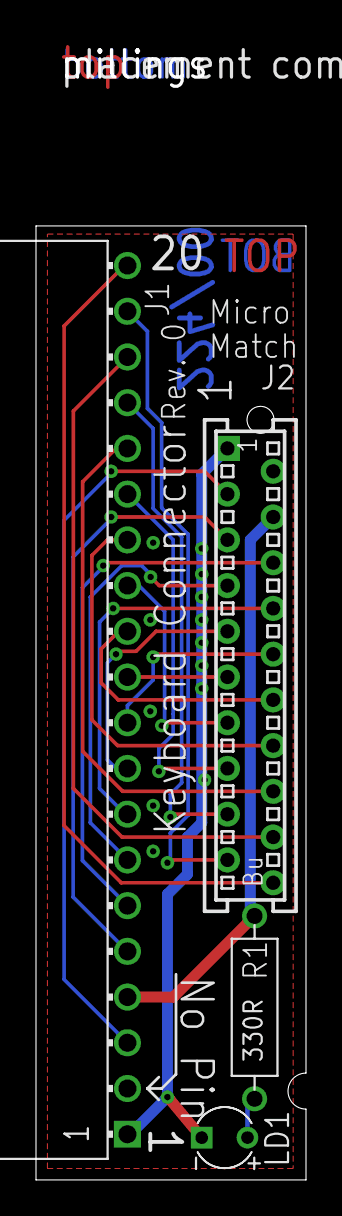
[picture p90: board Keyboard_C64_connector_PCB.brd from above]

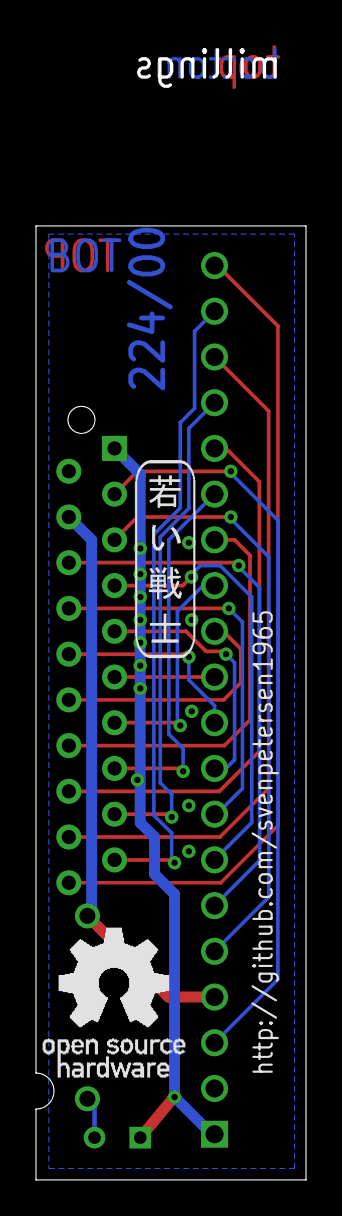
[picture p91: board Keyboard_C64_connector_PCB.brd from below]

Board: 2 copper layers, 15.0 x 53.0 mm, 8 parts (2 on the bottom side), 20 nets.

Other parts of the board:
U$6: 2LAYER
U$7: PCB-TITLE/
U$8: SVEN_TAG

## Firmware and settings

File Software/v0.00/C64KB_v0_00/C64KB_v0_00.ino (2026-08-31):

/* C64 Keyboard Software */
/* https://github.com/svenpetersen1965 */
/*
  Version History
  v0.00: initial release
*/


#define versionString "v0.00"

/* ======= user configuration preprocessor macros ===================================== */

/* ====== un-comment the used type of OLED display ore none =========================== */
//#define OLED091                  // 0.91" OLED Display, SSD1306, 128x32 pixel, I²C
//#define OLED096                  // 0.96" OLED Display, SSD1306, 128x64 pixel, I²C
//#define OLED130                  // 1.30" OLED Display, SH1106,  128x64 pixel, I²C

//#define OLEDturn                // turn OLED display 180°, if mechanically required 

/* ====== play the Commodore jingle at powre on ====================================== */
#define playKeepingUp              // play the "Are you keeping up.." jingle on startup

/* ====== un-commwnt only one of these USB keyboard layouts to activae USB-Keyboard 
   if the keyboard should connect to a mainboard via pin header, do not active USB keyboard at all */
// #define KB_US                     // USB HID Keyboard US Layout (positional) for Vice
// #define KB_DE                     // USB HID Keyboard German Layout (positional) for Vice
// #define KB_SE                     // USB HID Keyboard Swedish Layout (positional) for Vice
// #define KB_BMC64                  // USB HID Keyboard BMC64 Layout (positional) for BMC64/Raspberry Pi C64 emulation

/* ====== the ultimate 64 has a pinheader "buttons". ================================= */ 
/*  This preprocessor macro will activate controlling the buttons via pin header J2    */
// #define Ultimate                  // use J2 A13, 14, 15 as button left (freeze), menu, right (reset)

/* ====== WS2812B RGB LRD strip (aka neopixel) ======================================= */ 
// #define RGB                          //neopixel (WS2812) RGB strip

// customizable parameters for the RGB LED strip:
#define numRGB       23               // a strip of <num> RGB LEDs. number of LEDs on your strip
#define effectLen    46               // the effect length needs to be longer or equal than numRGB.
                                      // can be higher than numRGB, a higher number produces a smoother effect                     
#define RGBbright    32               // basic brightness of the RGB strip (0 = lowest, 255 = brightest)
#define RGBspeed     0                // speed of the fade effect (0 = fastest)

/* Kernal names */
// These are the names of the 8 kernals, which will be displayed on the OLED display (in case attached)
// NOT LONGER THAN 10 CHARACTERS !!!! 
//     maximum -->          <--length

#define KrnName1 "Kernal #1" // name of Kernal #1 being displayed on the OLED display
#define KrnName2 "Kernal #2" // name of Kernal #2 being displayed on the OLED display
#define KrnName3 "Kernal #3" // name of Kernal #3 being displayed on the OLED display
#define KrnName4 "Kernal #4" // name of Kernal #4 being displayed on the OLED display
#define KrnName5 "Kernal #5" // name of Kernal #5 being displayed on the OLED display
#define KrnName6 "Kernal #6" // name of Kernal #6 being displayed on the OLED display
#define KrnName7 "Kernal #7" // name of Kernal #7 being displayed on the OLED display
#define KrnName8 "Kernal #8" // this will not be displayed in case a short board adapter is used, leave as is.
/*
#define KrnName1 "Commodore" // name of Kernal #1 being displayed on the OLED display
#define KrnName2 "JiffyDOS" // name of Kernal #2 being displayed on the OLED display
#define KrnName3 "JaffyDOS" // name of Kernal #3 being displayed on the OLED display
#define KrnName4 "DolphinDOS" // name of Kernal #4 being displayed on the OLED display
#define KrnName5 "SpeedDOS" // name of Kernal #5 being displayed on the OLED display
#define KrnName6 "Kernalv2.1" // name of Kernal #6 being displayed on the OLED display
#define KrnName7 "Exos v3" // name of Kernal #7 being displayed on the OLED display
#define KrnName8 "TurboAcc."
*/

/* ====== Logo on OLED on start ===================================================== */
#define Logo64               // Logo "64" on OLED display
//#define Logo20               // Logo "VIC-20" on OLED display

/* ====================== End of user definable preprocessor macros ================= */

//do not change:
#define numRGBmodes 10               // number of RGB modes

// defining the displays
#ifdef OLED091                     //0.91" OLED with SSD1306 controller and 128x32 pixel
  #define OLED
  #define SCREEN_WIDTH 128         // screen width in pixel 
  #define SCREEN_HEIGHT 32         // screen height in pixel
  #define SSD1306                  // type of OLED controller
#endif

#ifdef OLED096                     //0.96" OLED with SSD1306 controller and 128x64 pixel
  #define OLED
  #define SCREEN_WIDTH 128         // screen width in pixel
  #define SCREEN_HEIGHT 64         // screen height in pixel
  #define SSD1306                  // type of OLED controller
#endif

#ifdef OLED130                     //1.3" OLED with SH1106 controller and 128x64 pixel
  #define OLED
  #define SCREEN_WIDTH 128         // screen width in pixel
  #define SCREEN_HEIGHT 64         // screen height in pixel
  #define SH1106                   // type of OLED controller
#endif

// if one of the keyboard layouts is activated, then activate USBkeyboard
#ifdef KB_US
  #define USBkeyboard                  // this enables a USB keyboard, which is suitable for VICE
  #define KB Keyboard
#endif

#ifdef KB_DE
  #define USBkeyboard                  // this enables a USB keyboard, which is suitable for VICE
  #define KB Keyboard
#endif

#ifdef KB_SE
  #define USBkeyboard                  // this enables a USB keyboard, which is suitable for VICE
  #define KB Keyboard
#endif

#ifdef KB_BMC64                        
  #define USBkeyboard                  // this enables a USB keyboard, which is suitable for BMC64/RaspberryPi
  #define KB BootKeyboard              // BMC64 requires a boot keyboard
#endif

// defining some strings. Each should not be longer than 10 characters
// These could be a name of the kernal images in the EPROOM 
#ifdef OLED
  typedef char msgString[11];
  const msgString  kernalNames[10] = { {KrnName1},             // names of the kernals
                                       {KrnName2},
                                       {KrnName3},
                                       {KrnName4},
                                       {KrnName5},
                                       {KrnName6},
                                       {KrnName7},
                                       {KrnName8},
                                       {"USB-KeyB"},
                                       {"Ultimate"}
  };
#endif

#ifdef OLED
  //                              -->          <--
  const msgString Messages[11] = { {"Reset"},                   // messages shown on screen
                                   {"EXROMReset"},
                                   {"RestoreFix"},
                                   {"RGB Mode -"},
                                   {"RGB Mode +"},
                                   {"US posit."},
                                   {"DE posit."},
                                   {"SE posit."},
                                   {"Freeze"},
                                   {"Menu"},
                                   {"BMC64 p."}
  };
#endif

#include <EEPROM.h>                     // Library for accessing the (non-volatile) EEPROM 
#include <Wire.h>                       // import Wire library 
#include <avr/pgmspace.h>               // for accessing the sine table

// #include <LiquidCrystal_I2C.h>       // import LiquidCrystal_I2C library
#ifdef OLED
  #include <Adafruit_GFX.h>             // https://github.com/adafruit/Adafruit-GFX-Library
  #ifdef SSD1306
    #include <Adafruit_SSD1306.h>       // https://github.com/adafruit/Adafruit_SSD1306
    #define tCol SSD1306_WHITE
  #endif
  #ifdef SH1106
    #include <Adafruit_SH110X.h>        // https://github.com/adafruit/Adafruit_SH110X
    #define tCol SH110X_WHITE
  #endif
#endif

#ifdef USBkeyboard                      // the PCF8575 is the I²C 16 bit IO extender for the keyboard scan
  #include <PCF8575.h>                  // https://github.com/RobTillaart/PCF8575
  #define PCF_Addr 0x20                 // the I²C address of it.  
  
  #include <HID-Project.h>              // https://github.com/NicoHood/HID
  #include <HID-Settings.h> 
#endif

#ifdef RGB                              // the NeoPixel library is required for the WS2812B LED strips
  #include <Adafruit_NeoPixel.h>        // https://github.com/adafruit/Adafruit_NeoPixel
#endif

// pin definitions
#define nRestore 4
#define buzzer   5
#define rgbPin   6
#define nC64res  8
#define pwrLed   9
#define nExrom   10
#ifndef Ultimate
  #define kswA13   15
  #define kswA14   14
  #define kswA15   16
#else
  #define uFreeze  15
  #define uMenu    14
  #define uReset   16
#endif
#define shortBrd A0
#define nPrev    A1
#define nNext    A2
#define PCFint   7

// definition of the RESTOREfix puls trail 
#define numPulses      5          // number of pulses
#define pulseDuration  30         // duration/period of a pulse in milli seconds

#ifdef Ultimate
  #define uTime 300               // 300ms button down duration
#endif

#ifdef OLED
  // Declaration for an SSD1306 display connected to I2C (SDA, SCL pins)
  #define OLED_RESET     -1 // Reset pin # (or -1 if sharing Arduino reset pin)
  #ifdef SSD1306
    // Declaration for an SSD1306 display connected to I2C (SDA, SCL pins)
    Adafruit_SSD1306 display(SCREEN_WIDTH, SCREEN_HEIGHT, &Wire, OLED_RESET); // start SSD1306 OLED display
  #endif
  #ifdef SH1106
    Adafruit_SH1106G display = Adafruit_SH1106G(SCREEN_WIDTH, SCREEN_HEIGHT, &Wire, OLED_RESET); // start SH1106G OLED display
  #endif
#endif

#ifdef RGB
  Adafruit_NeoPixel strip(numRGB, rgbPin, NEO_GRB + NEO_KHZ800);                                 // initialize RGB LED strip
#endif

#ifdef USBkeyboard  
  PCF8575 pcf(PCF_Addr);                            // initialize the PCF8587 I/O expander for (USB) Keyboard Scan
#endif
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
void loop() {
  // if an USB Keyboard is defines and noi scan signals from the C64 have been found
  
  #ifdef USBkeyboard
    if (USBkbActive) {                // doKBscan is set by the timer interrupt ebery 8 msecs 
      if (doKBscan) {                 // scan the keyboard (*** times per second, if the timer interrupt has set doKBscan)    
        doKBscan = false;             // reset semaphore doKBscan
        keyScan();                    // scan the keyboard
      }
    }
  #endif

  /* ====== State machine ========================================================== */
  // the timer interrupt controls everything here and modifies the restoreSemaphore
  switch (restoreSemaphore) {
    case rIdle:  {                            // idle state
      if (refresh) {                          // if the OLED display requires a refresh after displaying something else
        refresh = false;                      // reset the flag
        #ifdef OLED
          displayKernal(KNumber);             // display the active kernal 
          displayURL();
          display.display();
        #endif        
      }
      // the tick01sec is set by the timer interrupot every 0.1s, so the stuff, which has to be done every 0.1 sec will be triggered by that
      if (tick01sec) {                        // execute RGB stuff every 0.1 secs 
        tick01sec = false;                    // reset 0.1 sec tick
        #ifdef RGB
          executeRGB( modeNumber );           // call RGB LED strip execution routine
        #endif
      }
      break;
    }
    
    // ==== RESTORE pressed >0.3 secs => 
    case rFix: {                               // C64 ===>  RESTORE fix (RESTORE puls train)                           
      #ifdef OLED
        if (activeRefresh()) {
          displayKernal(KNumber);               // Display Kernal name on OLED
        }
        displayMsg(2);                         // display  "Restore Fix" on display
      #endif
      setRefreshCntDwn(2000);                  // set count down for thew display refresh to 2 seconds
      #ifdef USBkeyboard                       // USB-Keyboard ===>
        if (USBkbActive) {
          KB.press( (KeyboardKeycode) KEY_RESTORE );     // send restore key scan code  on USB keyboard 
          waitMs(100);
          KB.release( (KeyboardKeycode) KEY_RESTORE );
          #ifndef KB_BMC64                                         // if not BMC64
            waitMs(300);
            KB.press( (KeyboardKeycode) KEY_RESTORE );   // the second time
            waitMs(100);
            KB.release( (KeyboardKeycode) KEY_RESTORE );
          #endif
        }
      #endif 
      #ifndef USBkeyboard                      // if it is a real C64 connected
        #ifndef Ultimate                       // and not an ultimate (the ultimate does not require a restore puls train)
          restorePulses();                     // issue a pulse trail on the RESTORE pin.
        #endif
      #endif  
      restoreSemaphore = rIdle;                // reset the restore semaphore to idle
      break;
    }
    
    // ==== RESTORE helt for >3 secs =>
    case rReset: {                             
      #ifdef OLED
        if (activeRefresh()) {
          displayKernal(KNumber);              // Display Kernal name on OLED
        }
        displayMsg(0);                         //  Display "Reset"
      #endif
      setRefreshCntDwn(2000);                  // Set display refresh countdown to 2 secs.
      tone( buzzer, 1000 );                    // 1kHz sound on snd_out
      waitMs( 250 );
      noTone( buzzer );
      #ifdef USBkeyboard                       // USB keyboard?
        #ifndef KB_BMC64                       // if it is not
          keyPlusAlt ( KEY_F9 );               // ALT+F9 is "soft reset" in VICE
        #else
          keyPlusClips (KEY_F1);               // C= + F1 for BMC64 (This has to be defines as soft reset)
        #endif
      #endif
      #ifdef Ultimate                          // in Ultimate 64 mode => Button uRESET
        digitalWrite(uReset, LOW);
        digitalWrite( pwrLed, 0 );             // Signaling active: turn Power LED off
        pinMode( nC64res, OUTPUT);             // resetting the shift lock status
        pinMode(uReset, OUTPUT);               // "press" button uReset 
        waitMs(uTime);                         // wait some time
        pinMode(uReset, INPUT);                // release the button: Switch to Hi-Z
        pinMode( nC64res, INPUT );             // release the reset for the shift lock state flipflop
        digitalWrite( pwrLed, 1 );             // power LED on again
      #else
        resetC64( false );                     // C64: reset C64 in normal mode
      #endif
      restoreSemaphore = rIdle;                // put state machine in idle state  
      break;
    }

    // ==== RESTORE helt for >5 secs =>
    case rExrom: {                             // EXROM reset
      #ifdef OLED
        if (activeRefresh()) {
          displayKernal(KNumber);              // Display Kernal name on OLED
        }
        #ifndef Ultimate
          displayMsg(1);                         // display "EXROM reset" on OLED display
        #else
          displayMsg(0);                         // display "Reset" on OLED display 
        #endif 
      #endif
      #ifdef Ultimate                          // in Ultimate 64 mode => Button uRESET
        digitalWrite(uReset, LOW);
        digitalWrite( pwrLed, 0 );             // Signaling active: turn Power LED off
        pinMode( nC64res, OUTPUT);             // resetting the shift lock status
        pinMode(uReset, OUTPUT);               // "press" button uReset 
        waitMs(uTime);                         // wait some time
        pinMode(uReset, INPUT);                // release the button: Switch to Hi-Z
        pinMode( nC64res, INPUT );             // release the reset for the shift lock state flipflop
        digitalWrite( pwrLed, 1 );             // power LED on again
      #endif
      setRefreshCntDwn(2000);                  // Set display refresh countdown to 2 secs.
      #ifdef USBkeyboard
        #ifndef KB_BMC64                       
          keyPlusAlt ( KEY_F12 );              // VICE  => F12+ALT is "hard reset" in VICE
        #else                                  
          keyPlusClips(  KEY_F3 );             // BMC64 => C= + F3 for BMC64 (This has to be defines as hard reset)
        #endif
      #endif
      resetC64(true);                          // C64   => reset C64, EXROM mode 
      restoreSemaphore = rIdle;                // put state machine in idle state 
      break;
    }
    
    // ==== PREV key with RESTORE detected =>
    case kPrev: {
      #ifdef USBkeyboard
        #ifndef KB_BMC64                      
          keyPlusAlt ( KEY_8 );               // VICE  => <ALT>+<8> is "attach disk image" in VICE
        #else
          keyPlusClips( KEY_F5);              // BMC64 => Send C= + F5 (this needs to be defined in the menu)
        #endif
      #endif
      #ifdef Ultimate                         // Ultimate =>
        #ifdef OLED
          displayMsg(8);                      // Display "FREEZE"
          setRefreshCntDwn(2000);             // Set display refresh countdown to 2 secs.
        #endif
        tone(buzzer, 3000);                   // buzzer tone 3kHz
        digitalWrite(uFreeze, LOW);           // press Ultimate Freeze button
        pinMode(uFreeze, OUTPUT);
        waitMs(uTime);
        pinMode(uFreeze, INPUT);
        noTone(buzzer);
      #else                                   // C64 =>
        readJumper();                         // read short board jumper J4
        if (KNumber > 1) {                    // if kernal number > 1
          KNumber--;                          // decrement it
        }
        else {             
          KNumber = 8 - KOffset;              // if 0: set to highest kernal number (rotate through kernal numbers)
        }
        #ifdef OLED                           // Display Kernal name on OLED
          displayKernal(KNumber);     
          displayURL();        
        #endif
        setKswAddr( KNumber );                // set the MS address bits for the kernal ROM
        resetC64(false);                      // reset the C64 normal mode
        EEPROM.write(eeKernal, KNumber);      // save the chosen Kernalnumber in EEPROM
        waitMs( 1000 );                       // wait for the user releasing the restore key
      #endif                                   
      restoreSemaphore = rIdle;               // put state machine in idle state
      break;
    }
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

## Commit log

2026-06-04 3D printed frame
    [C63KB_Stiffener.stl, C64 Keyboard Frame v0.f3d, C64 Keyboard Frame v1.f3d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]
2026-06-04 Print trays
    Trays for keycap fabrication
    [c64_kb_1U_grid v3.stl, c64_kb_1U_grid.f3d, c64_kb_1_5U_grid v5.stl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]
2026-08-08 3D printables
    [C63KB_Stiffener.stl, C64 Keyboard Frame v0.f3d, C64 Keyboard Frame v1.f3d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]
2026-09-14 Delete Keycaps/print_trays/fusion360/c64_kb_1U_grid.f3d
    Obsolete file removed
    [c64_kb_1U_grid.f3d]
2026-09-14 Delete Keycaps/print_trays/fusion360/c64_kb_1_5U_grid.f3d
    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
    [c64_kb_1_5U_grid.f3d]
2026-10-12 Add Gerber without document frame
2026-10-12 *_noFrame* gerbers added
2026-10-19 Added Calculation. Fixed connector part number.
2026-10-19 Fixed a connector part number in the BOM
    The micro match IDC connector is MPE 371-1-020
